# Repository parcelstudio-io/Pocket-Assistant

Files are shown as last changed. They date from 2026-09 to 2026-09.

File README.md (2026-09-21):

# Pocket AI Assistant

This repository turns the [Huy Vector Pocket AI Assistant](https://www.huyvector.org/robots-kinetic/pocket-ai-assistant) reference build into a reviewable project with a pinned vendor image, safe host-side flashing tools, a source-buildable Xiaozhi board port, an audited bill of materials, and an assembly/test checklist.

## Start here: one small step at a time

Follow the [action-only fast track](plan/FAST_TRACK.md). It tells you exactly
what to take out, what to connect, what command to run, and what result counts
as a pass. Do one numbered step at a time; do not unpack the whole project.

The first physical step needs one controller and a proven USB data cable. The
controller order is recorded, but the planned cable purchase is not confirmed;
the guide links the recorded candidate and shows how to test any cable you
already own. It then adds the button, OLED, and microphone one at a time. The
default source build is an **offline bench test**: it reports microphone levels
over USB and tests the OLED without Wi-Fi, a cloud account, an amplifier, or a
battery.

Leave the battery, charger, external regulators, amplifier, and metal case off
this first prototype. OLED/microphone power comes only from the controller's
3.3 V output. Never connect an external power source to that rail while USB is
connected.

The [technical USB quickstart](docs/PROTOTYPE_QUICKSTART.md) remains the compact
reference for experienced builders and troubleshooting. Engineering
explanations moved out of the action guide into the
[fast-track theory companion](plan/FAST_TRACK_THEORY.md). The
[15-session daily plan](plan/DAILY_STUDY_AND_LAB_PLAN.md) is the deep track —
full measurement labs, evidence discipline, and per-day material prep lists —
worth returning to before any future battery, audio-power, or enclosure work.

## Choose a firmware path

| Path | Use it when | What is reproducible |
| --- | --- | --- |
| Corrected source — recommended | Offline prototype tests first; assistant mode later | Pinned upstream/SDK, checked overlay, and a manifest of the actual local build |
| Pinned vendor image — historical | Investigating the creator's published behavior and face assets | Download integrity only; its GPIO8 microphone and 24 kHz audio are not the corrected prototype contract |

These paths are deliberately separate. The creator published only a merged binary, not the custom `pocket-wall-e-c3` source or face assets. Inspection identifies it as a private Xiaozhi `2.4.0` build made with `ESP-IDF v5.5.2-dirty`. The editable port in [`firmware/`](firmware/) reconstructs the board against public [Xiaozhi v2.4.0](https://github.com/78/xiaozhi-esp32/releases/tag/v2.4.0) and its supported ESP-IDF v6.0.2 toolchain; it is not claimed to be byte-identical.

## Repository map

```text
.
├── docs/
│   ├── FINAL_MATERIALS_FOR_REVIEW.md  current Phase 0 purchase authority
│   ├── CLAUDE_R1_BUILD_PROPOSAL.md    archived compact-build proposal
│   ├── MATERIALS.md              archived R1 order sheet; do not order from it
│   ├── BUILD_GUIDE.md            video correlation; final assembly is held
│   ├── WIRING_AND_ASSEMBLY.md    archived R1 power wiring; not build authority
│   └── BOM.md                    historical creator-page ↔ R1 reconciliation
├── edu/
│   ├── README.md                 course index and source-of-truth map
│   ├── STUDY_PLAN.md             battery-free fifteen-session curriculum
│   ├── 01-how-it-fits-together.md applied system and signal overview
│   ├── 05_COLOR_AND_FINISH.md    provisional finish study
│   └── fundamentals/             durable electronics lessons and references
├── firmware/
│   ├── src/                      editable pocket-wall-e-c3 board overlay
│   ├── scripts/                  prepare, build, and source-flash helpers
│   ├── source-build.json         validated source-build digest and inputs
│   └── README.md                 source workflow and known differences
├── simulation/
│   ├── diagram.json              partial ESP32-C3/OLED/button Wokwi fixture
│   └── README.md                 simulation limits and lint command
├── plan/
│   ├── FAST_TRACK.md             action-only beginner build guide
│   └── FAST_TRACK_THEORY.md      optional theory mapped to each build step
└── tools/
    ├── netcheck.py               static checker; legacy power model withdrawn
    ├── pocket_ai_device.py       vendor-image fetch/verify/flash/monitor CLI
    ├── vendor-firmware.json      artifact provenance and integrity metadata
    └── tests/                    host-tool unit tests
```

A [partial Wokwi fixture](simulation/README.md) checks the corrected OLED and
GPIO10 button diagram. It intentionally does not model the power or audio
hardware.

Software setup can start without a new purchase. The first physical boot needs
a proven data cable, and a fully bare controller/OLED/microphone set needs 26
header pins; check the fast track before ordering or soldering anything. For a
**later battery-powered assembly**,
[docs/FINAL_MATERIALS_FOR_REVIEW.md](docs/FINAL_MATERIALS_FOR_REVIEW.md)
records the proposed F0 hardware and its unresolved tests; it is not a prerequisite
shopping list for the USB prototype. Do not connect the cell, cut brass, assemble
that power chain, or pocket-carry it without completing the relevant tests.
The former complete-cart decision is retained
unchanged in [docs/CLAUDE_R1_BUILD_PROPOSAL.md](docs/CLAUDE_R1_BUILD_PROPOSAL.md)
for review; [docs/MATERIALS.md](docs/MATERIALS.md),
[docs/BUILD_GUIDE.md](docs/BUILD_GUIDE.md), and
[docs/WIRING_AND_ASSEMBLY.md](docs/WIRING_AND_ASSEMBLY.md) describe that
superseded R1 candidate and are not purchasing or assembly authority.

Use the [electronics course](edu/README.md) as a reference when a step introduces
a new concept, not an entrance exam. Regardless of revision,
do **not** strip a lithium cell, solder to its can, use the brass frame as a
conductor, or charge an undocumented cell.

## Historical vendor-image workflow

Skip this section for the beginner prototype. Use the corrected source below;
a matching vendor checksum does not establish compatible microphone wiring or
MAX98357A audio timing.

For Phase 0, flash a bare SuperMini. An assembled service design is not yet
released. Until the proposed supply and I2S/control isolation pass every
source-state test, **unplug the pack and detach the external power and
amplifier-signal harnesses before connecting the SuperMini USB-C**, and never
connect both USB-C ports. Generic SuperMini clones have varying VBUS/`5V`
arrangements, so the final solution cannot rely on an assumed clone diode.

```bash
python3 -m venv .venv
. .venv/bin/activate
python -m pip install --upgrade pip
python -m pip install --requirement tools/requirements.txt

python tools/pocket_ai_device.py fetch
python tools/pocket_ai_device.py verify
python tools/pocket_ai_device.py ports
python tools/pocket_ai_device.py info --port /dev/ttyACM0
python tools/pocket_ai_device.py flash --port /dev/ttyACM0 --dry-run
python tools/pocket_ai_device.py flash --port /dev/ttyACM0
python tools/pocket_ai_device.py monitor --port /dev/ttyACM0
```

Replace `/dev/ttyACM0` with the explicit port reported on your machine. The image is a merged ESP32-C3 image and is written at `0x0`; the tool verifies it and asks for confirmation before writing. See [`tools/README.md`](tools/README.md) for Windows/macOS port names, BOOT-mode recovery, Wi-Fi provisioning, and privacy notes.

## Build the editable source port

The source workflow fetches the pinned upstream repository into an ignored working directory, applies the local board files, checks the upstream commit, and builds with ESP-IDF v6.0.2:

```bash
firmware/scripts/setup.sh
. firmware/.work/esp-idf/export.sh
firmware/scripts/build.sh
```

Setup is needed once; activate `export.sh` again in each new terminal.
`build.sh` defaults to offline diagnostics. Use `build.sh --assistant` only
after those tests pass and you are ready to configure the third-party service.
Read [`firmware/README.md`](firmware/README.md) before using the source-flash helper.
It records the expected toolchain, generated output, pin assignments, and the
differences from the opaque vendor image.

## Hardware contract

| Function | Module signal | ESP32-C3 GPIO |
| --- | --- | ---: |
| OLED I2C | SDA / SCL | 21 / 20 |
| Shared I2S clocks | WS / BCLK | 1 / 2 |
| Microphone input | I2S microphone data (#6049 ICS-43434 Phase 0 primary; INMP441 alternate) | 4 |
| Amplifier output | MAX98357A DIN | 3 |
| Optional external action button | active-low button | 10 |

The corrected source build accepts a 0.96-inch 128×64 SSD1306 I2C module at address `0x3c` or `0x3d`, uses 16 kHz duplex audio, and puts the I2S microphone's data output on GPIO4 with its left-slot select grounded. The Phase 0 primary is the controlled Adafruit #6049 ICS-43434 (`SEL` → GND); INMP441 (`L/R` → GND) remains an alternate after its carrier pinout is checked. The pinned creator binary instead requires microphone data on GPIO8 and OLED address `0x3c`. Both audio modules share `WS` and `BCLK`. GPIO10 is the active-low application input, while the SuperMini's ROM BOOT button remains GPIO9.

## What has and has not been verified

- The published binary's size, digest, merged-image markers, chip target, application metadata, and partition offsets were inspected and pinned.
- The host CLI has unit tests and refuses an unverified image or implicit serial-port target.
- Each successful source build records its exact inputs, effective configuration,
  mode, and output digest in ignored `firmware/dist/source-build.json`. The
  [checked-in reference record](firmware/source-build.json) describes one specific
  build; neither a checksum nor successful compilation proves hardware operation.
- The USB prototype was built and established `PASS 9` on 2026-09-20: two cold
  starts without a reset loop, every button press logged, the OLED starting and
  toggling, and speech microphone RMS roughly 4x the quiet floor with
  `read_errors=0`. That is a bench result recorded by the builder, not an
  automated one: no assembled battery circuit has been connected, the amplifier
  stays disabled, and `firmware/source-build.json` still records
  `hardware_tested: false` because that flag describes what the build workflow
  verified, which remains nothing physical.
- On 2026-09-21 the builder provisioned board `A1` onto Wi-Fi under the 8.5 dBm
  transmit-power cap and received one remote response from the Xiaozhi backend
  (`PASS 10C`). That is also a builder-reported bench result. The amplifier
  stays disabled, so there is still no spoken output. Follow [Lesson 13's staged integration method](edu/fundamentals/13-debugging-integration-and-capstone.md), keep a separate [lab record](edu/fundamentals/reference/lab-record-template.md) for each article, and use the [current F0 promotion gates](docs/FINAL_MATERIALS_FOR_REVIEW.md#promotion-gates-before-claude-may-say-final-go) before any cell connection or pocket carry.

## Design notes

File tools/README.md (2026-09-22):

# Device host tools

For the beginner USB prototype, start with the
[action-only fast track](../plan/FAST_TRACK.md) and the corrected source
diagnostic build. The [quickstart](../docs/PROTOTYPE_QUICKSTART.md) remains the
compact technical reference. You do not need to download the vendor binary or
create a second Python environment after activating ESP-IDF. The tests and
`netcheck.py` below are useful for both paths; this page's `fetch`/`flash`
commands are for the **historical vendor image only**, not the corrected-source
artifact.

The Pocket AI Assistant normally runs without a laptop-side application. The
ESP32-C3 firmware provisions Wi-Fi locally, then obtains its MQTT or WebSocket
session details from a Xiaozhi-compatible OTA/bootstrap service. These tools are
only for retrieving the published image, flashing it safely, and viewing logs.

The published download is a **merged 4 MB ESP32-C3 image**. It must be written at
address `0x0`, not at the application-only address `0x10000`. The manifest pins
the exact byte size and SHA-256 observed on 2026-09-01. If the publisher changes
the file behind the Google Drive link, the tool stops instead of flashing an
unreviewed artifact.

## Set up the host environment

Python 3.10 or newer and a USB **data** cable are required. From the repository
root:

```bash
python3 -m venv .venv
. .venv/bin/activate
python -m pip install --upgrade pip
python -m pip install --requirement tools/requirements.txt
```

On Windows PowerShell, activate with `.venv\Scripts\Activate.ps1`. Linux users
may need membership in their distribution's serial-port group (often
`dialout`) and must sign out and back in after changing it.
If `python3 -m venv` reports that `ensurepip` is unavailable, install your
distribution's Python venv package (commonly `python3-venv`) and retry; do not
fall back to installing or running the flashing stack as root.

## Verify the host tools

From the repository root:

```bash
python3 -m unittest discover -s tools/tests -v
python3 tools/netcheck.py
```

The unit tests exercise image validation, write safeguards, source-build
provenance, and intentionally invalid logical connections. `netcheck.py`
checks the corrected-source GPIO/protocol contract, endpoint uniqueness, and
the modeled floating speaker connections. It does not inspect your breadboard
or qualify power, USB isolation, physical modules, audio, RF, or fit.

## Fetch and verify

```bash
python tools/pocket_ai_device.py fetch
python tools/pocket_ai_device.py verify
```

The default image location is the ignored `tools/.cache/pocket-esp-ai.bin`.
Neither the third-party binary nor credentials are committed to the repository.

## Identify and flash the board

Connect the ESP32-C3 directly over USB, close programs using its serial port,
then list ports:

```bash
python tools/pocket_ai_device.py ports
python tools/pocket_ai_device.py info --port /dev/ttyACM0
```

Use the port shown on your system (`/dev/ttyACM0`, `/dev/ttyUSB0`, a macOS
`/dev/cu.*` device, or a Windows `COM` port). The tool never guesses the target
for a write. To preview and then perform the flash:

```bash
python tools/pocket_ai_device.py flash --port /dev/ttyACM0 --dry-run
python tools/pocket_ai_device.py flash --port /dev/ttyACM0
```

Flashing at `0x0` replaces the bootloader, partition table, application, assets,
and NVS, so saved Wi-Fi configuration is cleared. The tool verifies the image
again and requires typing `FLASH` before it starts. Use `--yes` only in a
controlled automated workflow.

If automatic reset cannot enter the ROM bootloader, hold the board's **BOOT**
button, tap **RESET** (or reconnect USB), release **BOOT**, and retry. Do not use
the destructive erase command as a routine prerequisite. It is available for
recovery and has a separate confirmation:

```bash
python tools/pocket_ai_device.py erase --port /dev/ttyACM0
```

## View boot logs and provision Wi-Fi

```bash
python tools/pocket_ai_device.py monitor --port /dev/ttyACM0
```

The console uses 115200 baud; exit it with `Ctrl+]`. On a clean first boot, the
firmware is expected to create a `Xiaozhi-XXXX` Wi-Fi provisioning access point,
where the suffix is device-specific. Confirm the actual name in the boot log,
join it from a phone or computer, and open <http://192.168.4.1> if the captive
portal does not appear. Choose a 2.4 GHz network and enter its credentials in
the device-hosted form.

The stock image uses `https://api.tenclass.net/xiaozhi/ota/` as its bootstrap
service. That third-party service receives device metadata and assistant audio;
review its terms and privacy behavior before using it. No cloud token or API key
belongs in this repository. A different backend requires a compatible OTA
service URL and, preferably, a source build configured for that service.

## Check which Wi-Fi network a board has saved

`saved_wifi.py` reads only the board's NVS settings partition, prints the saved
network names with every password shown as `<hidden, set>` or `<hidden, empty>`,
and deletes its temporary copy even if a step fails. The read resets the board
once and writes nothing. Run it inside the ESP-IDF environment:

```bash
. firmware/.work/esp-idf/export.sh
python tools/saved_wifi.py --port /dev/ttyACM0
```

`No saved Wi-Fi network` is the expected result after a full diagnostics
reflash, which writes a blank settings area.

## Troubleshooting

- `No serial ports found`: try a known data-capable cable and another USB port.
- Permission denied on Linux: fix serial-group or device permissions; do not run
  the whole workflow as root.
- Connection timeout: manually enter download mode with BOOT/RESET and retry at
  a lower baud, for example `--baud 115200`.
- SHA-256 mismatch: do not bypass verification. Check whether the publisher has
  intentionally released a new image, then review and update the manifest.
- Boot loop after a successful write: capture the complete 115200-baud log and
  confirm the board is actually an ESP32-C3 with at least 4 MB of flash.

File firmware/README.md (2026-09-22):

# Pocket AI Assistant firmware

This directory provides a buildable source overlay for the Pocket AI Assistant's
ESP32-C3 hardware. It pins the public Xiaozhi application, adds the project's
board registration and intended pin map, forces the 4 MB flash layout,
and produces a merged image that can be flashed at address `0x0`.

> **Current-contract boundary:** the corrected source targets an I2S
> microphone on GPIO4 (Phase 0 primary: Adafruit `#6049` ICS-43434 with `SEL`
> low; held alternate: INMP441 with `L/R` low) and a MAX98357A
> amplifier on GPIO3, with shared clocks on GPIO1/GPIO2 at 16 kHz. This README
> is not purchase authority; the release decision is
> [FINAL_MATERIALS_FOR_REVIEW.md](../docs/FINAL_MATERIALS_FOR_REVIEW.md).

## Beginner default: offline USB diagnostics

Start with the [action-only fast track](../plan/FAST_TRACK.md), not the vendor
binary. The [prototype quickstart](../docs/PROTOTYPE_QUICKSTART.md) is the
compact technical reference. The default build tests the OLED and prints
microphone levels over USB. It does not start Wi-Fi, provision an account, or
send recordings anywhere. The amplifier is disabled. Begin with a bare
controller; add the OLED and microphone one at a time, powered from its 3.3 V
output only.

From the repository root, in Bash:

```bash
firmware/scripts/setup.sh
. firmware/.work/esp-idf/export.sh
firmware/scripts/build.sh
python3 firmware/scripts/verify_source_build.py
```

Setup downloads the pinned SDK and its tools and can take several minutes.
It does not need hardware or administrator privileges. Run setup once and
source `export.sh` again in each new terminal. Use `build.sh --diagnostics`
as an explicit alias for the default, or `build.sh --assistant` later for the
networked application. Both supported modes keep the amplifier disabled.
The last successful build is the one the verifier and flash helper select.

## Source status and limits

The project author publishes a merged binary but not the corresponding board
source. This adapter is therefore a careful source reconstruction, **not** the
author's original code and not a byte-for-byte rebuild of that binary.

- The vendor image identifies itself as Xiaozhi `2.4.0`, board
  `pocket-wall-e-c3`, built by a private `ESP-IDF v5.5.2-dirty` tree.
- This source workflow pins public Xiaozhi tag `v2.4.0` at commit
  `5540258abcbfa62518d09959308200be1c5b1b2b` and the upstream-preferred
  ESP-IDF `v6.0.2`.
- The author's `PocketOledDisplay` behavior is unpublished. The overlay keeps a
  board-specific display extension point but currently uses Xiaozhi's standard
  128x64 OLED interface instead of attempting to imitate the custom face UI.
- The checked-in `dependencies.lock` pins the 60 managed components and their
  registry hashes used by the validated build. The build fails if the component
  manager tries to rewrite that lock.
- `SOURCE_DATE_EPOCH` is fixed to the upstream commit timestamp so generated
  app metadata and compiler date/time strings do not depend on build time.
- A successful build creates ignored `dist/source-build.json`, recording the
  actual image, all local source inputs, effective configuration, build mode,
  and tool versions. Verification checks these again before flashing. The
  checked-in `source-build.json` is a reference for a specific build, not a
  permanent checksum every future source edit must reproduce. Local records
  do not inherit old claims of identical clean builds or hardware tests.
- The source and configuration can be compiled without the device. Electrical,
  microphone, speaker, button, and end-to-end assistant behavior still require
  a hardware smoke test.

Assistant mode additionally diverges for English users: wake word
`wn9s_hiesp` ("Hi, ESP") and `CONFIG_LANGUAGE_EN_US` replace the vendor
image's Mandarin `wn9s_nihaoxiaozhi` and zh-CN strings (both set in
`sdkconfig.defaults` and the board `config.json`; the explicit
`# CONFIG_SR_WN_WN9S_NIHAOXIAOZHI is not set` line is required because the
WakeNet9s entries are independent bools, not a choice group).

### Amplifier-enabled build for Step 11

`build.sh --assistant --amplifier` (or `--assistant-local ... --amplifier`)
enables the amplifier for fast-track Step 11, where the MAX98357A takes `VIN`
from the controller's `5V` pin and GPIO5 drives its `SD` pin directly with a
pull-down. The firmware holds GPIO5 low from its earliest board init, starts the
I2S clocks with zero data, waits the startup delay, raises GPIO5, waits the
turn-on delay, and only then sends audio, capped by `CONFIG_POCKET_AI_MAX_VOLUME`.
The diagnostics build refuses `--amplifier`. The build record, verifier, and
flash preview print `amplifier: ENABLED (Step 11, USB-powered)`. None of this
has run on hardware yet.

### Local OpenAI voice bridge

**Parked build note (2026-09-21):** The prepared A1 image is
`dist/pocket-wall-e-c3-v2.4.0-idf-v6.0.2.bin` (SHA-256
`903e5cfe6fedae2bd0f245ac432105347dc94b5688010092a39f8c20dfa753ff`).
It is the `assistant-local` build of Xiaozhi v2.4.0 on ESP-IDF v6.0.2,
targeting ESP32-C3 with a private bridge URL on host `192.168.1.171`.
The amplifier is disabled. The image passed source verification and a flash
dry run; it has **not** been flashed to A1 or tested with the OpenAI API or
speaker. Recheck the host IP and rebuild before use if the network changes.

`build.sh --assistant-local --bridge-url=http://HOST:8765/ota/SECRET` builds the
same A1 assistant with its Xiaozhi audio WebSocket pointed at the LAN bridge
in [`bridge/`](bridge/). Replace `HOST` with the computer's LAN IP address
that A1 can reach; use the `A1_OTA_TOKEN` generated for the bridge as `SECRET`.
The build keeps OpenAI credentials on that computer and
ignores any older Xiaozhi OTA URL saved on A1. If the bridge is unavailable,
the firmware waits for it instead of using a cached cloud WebSocket address.
The bridge computer and A1 must be on the same reachable network while using
this build. Reflashing the merged image at `0x0` may erase saved Wi-Fi settings;
be ready to provision Wi-Fi again.

The current supported build still holds GPIO5 low and writes silence to the
speaker path. It can validate microphone upload and OpenAI responses, but A1
will not speak until the MAX98357A interface and power sequence have passed
the hardware checks below and an amplifier-enabled build mode is added.

For the exact published image and its pinned checksum, use the
[host flashing and verification tools](../tools/README.md).

## Current corrected-source pin map

| Function | ESP32-C3 GPIO | Peripheral connection |
| --- | ---: | --- |
| I2S word select | 1 | #6049 ICS-43434 `WS/LRCLK` (alt: INMP441 `WS`) and MAX98357A `LRC` |
| I2S bit clock | 2 | #6049 ICS-43434 `BCLK` (alt: INMP441 `SCK`) and MAX98357A `BCLK`; expected 1.024 MHz |
| I2S speaker data | 3 | MAX98357A `DIN` |
| I2S microphone data | 4 | #6049 ICS-43434 `DOUT` (alt: INMP441 `SD`) |
| Optional action/config input | 10 | Active-low push button to GND if fitted |
| OLED SCL | 20 | SSD1306 SCL |
| OLED SDA | 21 | SSD1306 SDA |

These are logical endpoints. The F0 hardware experiment interposes a one-way
TXU0104 boundary between GPIO1/GPIO2/GPIO3 and the amplifier. It proposes
GPIO5, with 4.7 kΩ to ground, as channel A4; B4 then releases `SD_MODE` into
left-channel operation. The #2873 open-drain power-good output independently
gates TXU `OE` through a 10 kΩ pull-up to 5V_SYS, so loss of rail-good disables
all amplifier-side outputs. Official chip reset does not itself pull MTDI
(GPIO5) high, but firmware APIs can enable that pull-up: GPIO5 must be driven low
at the earliest board-init point and must not be reset into a pulled-up state.
The candidate has no MCU `PG` sense input: firmware sequencing uses a qualified
startup/rail delay and valid zero-data I2S while `PG` independently vetoes
`OE`. The delay before nonzero samples must cover measured worst-case `PG`
release plus amplifier turn-on, or the final schematic needs a reviewed
level-safe sense path.
The board codec implements the GPIO5 mute/startup/shutdown sequence, but the
physical interface and its timing are **not hardware-qualified**. The supported
prototype builds deliberately keep `CONFIG_POCKET_AI_ENABLE_QUALIFIED_AMPLIFIER`
off. Leave the amplifier disconnected for the USB quickstart; on a separate
unqualified audio fixture, keep `SD_MODE` hard-grounded. Do not bypass that mute
just to hear a sound. Enabling a qualified fixture later requires deliberate
configuration/tooling changes and measured startup, shutdown, and partial-power
checks. A firmware volume limit alone is not a speaker-power qualification.

At 16,000 frames/s and 64 bit clocks per frame, the I2S bit clock is
`16,000 × 64 = 1.024 MHz`. The microphone uses the intended left slot with its
select pin low (#6049 `SEL`; INMP441 `L/R`). The pinned codec selects mono DMA
with `I2S_STD_SLOT_LEFT`; source inspection therefore predicts active left and
inactive right TX slots because ESP-IDF copy-mono is enabled only for a `BOTH`
slot mask. Treat that as unverified until a hardware capture confirms it. Do
not assume the #3006 default mix gives full amplitude; qualify its `SD` mode
and select left explicitly if the capture confirms an inactive right slot.

### Historical vendor/video contract

The published vendor image uses a microphone harness with data on GPIO8,
SSD1306 address `0x3C`, and 24 kHz full-duplex audio. Those recovered values
are historical replication evidence only — never wire the corrected-source
GPIO4 harness for the vendor binary or vice versa. DFRobot `DFR0954` remains
an unqualified amplifier alternative; do not substitute it for a MAX98357A
breakout without revisiting the rail analysis in the materials decision.

The editable corrected source build uses 16 kHz duplex audio, receives mic data
on GPIO4 so GPIO8 can retain a defined high boot strap, probes SSD1306 at
`0x3C` and `0x3D`, and continues headless when no display answers. GPIO10 is
the active-low action/config input; GPIO9 remains ROM BOOT. The
[project overview](../edu/01-how-it-fits-together.md) summarizes this
corrected-source logical contract. This README and the board configuration
remain authoritative for firmware details. Do not mix the two wiring
contracts.

## Directory layout

```text
firmware/
├── partitions/       reviewed 4 MB partition table
├── patches/          Xiaozhi CMake/Kconfig board registration
├── scripts/          setup, prepare, build, record, verify, and flash entry points
├── src/boards/       project-owned board adapter and pin configuration
├── dependencies.lock pinned ESP-IDF component graph and registry hashes
├── source-build.json reference build record (local builds use dist/source-build.json)
├── sdkconfig.defaults
└── versions.env      pinned source and SDK versions
```

`scripts/prepare.sh` creates an ignored checkout under `.work/`, verifies the
exact upstream commit, applies the registration patch, and copies the reviewed
board files. A plain `prepare.sh` preserves and rejects a mismatched checkout.
`prepare.sh --refresh` archives that checkout instead of deleting it, then
prepares the updated overlay. `build.sh` uses this recoverable refresh
automatically, so an intentional source edit does not require manual cache
surgery. Build products go to ignored `dist/`.

## Build

The helper scripts require Bash and Python 3.10 or newer. Linux/macOS users
can use `setup.sh` above; Windows users should use a configured WSL environment
and arrange USB forwarding for the device. Git must already be installed. If
SDK setup reports a missing OS package such as Python venv support, install
that named prerequisite with your OS package manager and rerun setup; do not
run the firmware or flashing workflow as root.

An existing official Espressif ESP-IDF `v6.0.2` checkout at commit
`7101770dc6db2667b3c477cc31365dd1acd6db4e` can also be used: source its
`export.sh` instead. The build rejects a different SDK commit or tracked SDK
modifications. Python tool versions are recorded from the actual environment.

From the repository root:

```bash
firmware/scripts/build.sh
```

The build script rejects a different SDK version, regenerates `sdkconfig`, adds
the board overrides, compiles the app and default assets, and creates:

```text
firmware/dist/pocket-wall-e-c3-v2.4.0-idf-v6.0.2.bin
```

That file is a complete merged 4 MB-layout image for offset `0x0`. The app
partition begins at `0x10000`; do not write the merged image there.
Read the exact size, digest, and selected mode from `dist/source-build.json`
or run the verifier. There is intentionally no second, manually maintained
checksum in this README. A changed source input or modified binary after the
build fails verification; rebuild intentionally instead of bypassing the check.

To change an ordinary Kconfig option permanently, edit `sdkconfig.defaults` and
rerun the build. The CLI selects diagnostics versus assistant mode explicitly
and holds amplifier enable off. Temporary `menuconfig` edits are intentionally
replaced on the next scripted build. Source modifications belong in `src/` or
`patches/`, not the generated `.work/` checkout; refreshed checkouts are archived
so any earlier experiments remain recoverable.

## Flash and monitor source builds

For the USB bench prototype, use only the controller, button, and optional
OLED/microphone powered by the controller's 3.3 V output. Disconnect the
battery, charger, external regulators, amplifier, and all separately powered
wiring. A controller-powered peripheral is not an external supply; an
unpowered regulator connected to the same rail still is a back-power path.
Unplug USB before changing any wiring. Do not flash a permanently assembled
multi-supply harness until its service-isolation scheme is tested.
Then identify the serial port, close other serial
monitors, preview the operation, and run it, for example:

```bash
firmware/scripts/flash.sh /dev/ttyACM0 --dry-run
firmware/scripts/flash.sh /dev/ttyACM0 --monitor
```

Use the actual port on the host (`/dev/cu.*` on macOS; use the serial path exposed
inside WSL/Git Bash on Windows). The script requires typing the exact target
unless `--yes` is deliberately used for automation. It verifies the complete
merged image and byte-producing local inputs, then invokes esptool directly at
offset `0x0`; the flash step cannot trigger a rebuild after verification. Its
blank NVS area clears existing Wi-Fi settings. If automatic reset fails,
hold the module's GPIO9 **BOOT** button, tap RESET or reconnect USB, release
BOOT, and retry.

The default diagnostic image reports its mode over USB and remains offline;
use the quickstart to interpret the OLED and microphone results. No raw
recording is saved. Missing peripherals are reported, not prerequisites for
controller bring-up.

**Assistant mode only:** on a clean first boot, connect to the expected
device-specific `Xiaozhi-XXXX`
Wi-Fi provisioning access point, confirm its actual name in the boot log, and
open <http://192.168.4.1> if the captive portal does not appear. On this board
the firmware caps Wi-Fi transmit power at 8.5 dBm after every radio start, for
the provisioning access point and for the station connection, because the
SuperMini's ceramic antenna left the access point invisible at the default
20 dBm; the log prints `Wi-Fi max TX power capped at 8.5 dBm` for each. Xiaozhi's
default build uses `https://api.tenclass.net/xiaozhi/ota/` as its third-party
bootstrap service. Review that service's privacy and operational requirements
before sending microphone audio to it.

The pinned provisioning component creates that temporary access point without
Wi-Fi authentication and serves the form over unencrypted HTTP. It stores the
selected SSID and password in unencrypted NVS. Provision only in a private
location, preferably onto a dedicated guest/IoT SSID with a unique password;
nearby parties could otherwise observe or interfere. A reset does not remove
the saved credentials. The full source-flash operation above writes blank NVS
and clears them, so complete that reflash before a provisioned board leaves
your control.

This 4 MB layout has a factory application and no OTA application slot. The
firmware hides the unsupported manual-update tool and refuses OTA before
changing application state. Update this prototype using the USB flash helper,
not an online firmware-update command.

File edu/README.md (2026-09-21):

# Pocket Assistant electronics course

This directory teaches the electrical-engineering ideas needed to reason about
the Pocket Assistant and provides a small set of project-specific guides. It
assumes arithmetic and basic algebra, but no prior electronics experience.

Start with the [action-only fast track](../plan/FAST_TRACK.md) to boot the
controller and test the button, OLED, and microphone one part at a time. The
[USB prototype quickstart](../docs/PROTOTYPE_QUICKSTART.md) is the compact
technical reference. The [daily study and lab plan](../plan/DAILY_STUDY_AND_LAB_PLAN.md)
adds 2–3 hour sessions around that work. Read the relevant
[foundations lesson](fundamentals/README.md) as each circuit becomes useful;
you do not need to finish the course before starting. Keep these references
nearby:

- [equation sheet](fundamentals/reference/equations.md);
- [glossary](fundamentals/reference/glossary.md); and
- [lab record template](fundamentals/reference/lab-record-template.md).

Every lesson of the course, the project overview, the theory companion, the
Step 10 bench guide, and the current study plan are also published as
illustrated three-page web pages; the
[index of published learning pages](ARTIFACTS.md) holds the links. The
Markdown here remains the authority.

## Project-specific guides

- [Pocket Assistant project overview](01-how-it-fits-together.md) — system
  boundary, corrected-source logical contract, and lesson navigation.
- [White, silver, and black finish study](05_COLOR_AND_FINISH.md) — provisional
  visual direction and the tests required before a finish is adopted.

Project-specific component tables, power recipes, assembly instructions, and
acceptance worksheets are intentionally not duplicated here. Their status
changes as candidates are reviewed.

## Where truth lives

| Question | Source |
| --- | --- |
| Durable theory and safe technique | [Foundations course](fundamentals/README.md) |
| First USB prototype, owned-part wiring, and offline diagnostics | [Prototype quickstart](../docs/PROTOTYPE_QUICKSTART.md) |
| Firmware pins, rates, and build identity | [Firmware README](../firmware/README.md), [`config.h`](../firmware/src/boards/pocket-wall-e-c3/config.h), and [source-build manifest](../firmware/source-build.json) |
| Current candidates, purchase authority, and promotion gates | [Current material decision](../docs/FINAL_MATERIALS_FOR_REVIEW.md) |
| Results from a physical article | A completed [lab record](fundamentals/reference/lab-record-template.md) |

A marketplace listing, successful compile, static check, or CAD model is not
physical acceptance. The manifest still records `hardware_tested: false`,
which describes the build workflow, not the bench: the USB prototype itself
was built and passed its cold-start gate on 2026-09-20, and completed one
cloud round trip on 2026-09-21. Everything past that — amplifier, battery,
enclosure — remains unbuilt and unqualified.

## Safety boundary

Keep lithium cells out of early labs. Never strip, solder, heat, puncture, or
deliberately short a cell. Use a current-limited bench supply and follow the
current material decision before introducing stored energy.

Treat the metal frame as conductive and isolate it from every electrical net.
It is never a circuit conductor or return path. Neither bridge-amplifier
speaker lead is ground.

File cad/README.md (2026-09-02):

# CAD status and regeneration

> **STALE; NOT FIT OR FABRICATION AUTHORITY — 2026-09-02.** Everything in this
> directory models the withdrawn R0 architecture (16340 cell + BH123A holder +
> older Pololu stack, ~60 × 45 × 33 mm). It also predates the current F0
> candidate, which samples a 34 × 62 × 5 mm #258 pouch, #4410 charger, #2810
> switch, #2873 regulator, fuse, diode, two speaker geometries, and rigid cell
> guard. Use [docs/FINAL_MATERIALS_FOR_REVIEW.md](../docs/FINAL_MATERIALS_FOR_REVIEW.md).
> Do not regenerate from the old constants or cut brass. First measure the
> received Phase 0 parts, then rewrite `fitcheck.py`, regenerate every artifact,
> and verify the result with a 1:1 cardstock model.

`fitcheck.py` is the editable source for the placement study. The existing
`pager_rev_a.FCStd`, `pager_rev_a.step`, and `FITCHECK_REPORT.md` were
generated before the final audit; beyond the architecture change above, they
also used the wrong MPD BH123A dimensions, a discontinued capacitor, and an
incomplete antenna keepout. They are preserved for provenance only.
Regenerate after installing FreeCAD:

```bash
freecadcmd cad/fitcheck.py
```

Accept a new report only when every rule passes with measured part envelopes,
wire-bend room, insulation, fasteners, cell insertion/removal, and actual
connector plugs represented. A 1:1 cardstock/caliper dry fit remains required.

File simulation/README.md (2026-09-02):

# Partial Wokwi fixture

This fixture represents only the corrected ESP32-C3 display/action-button contract:

- SSD1306 on GPIO21 SDA / GPIO20 SCL;
- OLED deliberately set to `0x3d` to exercise the alternate-address probe; and
- active-low GPIO10 action button (`A` key in Wokwi).

It uses Wokwi's ESP32-C3 DevKitM model, not the mechanically different SuperMini. Wokwi does not prove the battery/charger/switch power path, real INMP441 acoustics, MAX98357A bridge output, speaker enclosure, Wi-Fi performance inside brass, solder quality, or temperature. Those require lesson 6's physical tests.

In `diagram.json`, the DevKitM model names GPIO20/21 `RX`/`TX`; these are connected to SCL/SDA respectively. The corrected firmware still addresses the GPIO numbers.

Validate the diagram without credentials:

```bash
wokwi-cli lint --warnings-as-errors simulation/diagram.json
```

To run the corrected source artifact after rebuilding it, export `WOKWI_CLI_TOKEN` in the same shell and point Wokwi CLI at the merged binary plus `firmware/.work/xiaozhi-esp32/build/xiaozhi.elf`. Do not store the token in this repository. The present Codex process has Wokwi CLI 0.26.1 but does not inherit that variable, so only linting was performed here.

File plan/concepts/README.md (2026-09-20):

# Illustrated concepts — the “why” behind each lab

[Back to the daily plan](../DAILY_STUDY_AND_LAB_PLAN.md) ·
[Action-only fast track](../FAST_TRACK.md) ·
[Fast-track theory map](../FAST_TRACK_THEORY.md) ·
[USB prototype technical reference](../../docs/PROTOTYPE_QUICKSTART.md)

Yes: start with the basic physics of **charge, energy, voltage, and current**,
then learn how complete circuits behave. You do not need to master all of
physics or finish every electronics lesson before booting a bare USB board.
Understand the circuit you are about to change, one small step at a time.

These are optional **5–10 minute illustrated explanations**, not extra lab
requirements. Each connects a physical idea to a calculation and a prototype
decision, then asks you to predict something. Expand the answer after trying.
Use these pages within the daily plan's existing study time, not on top of it.

## A small starting point

Read **01 → 02 → 03** first for the circuit foundation. Add **04 → 05** when
you reach capacitors and measurements. After that, open just the page for
the component you are testing. “I can explain why” is more useful than
memorizing every equation.

| Day | Illustrated explanation | The question it answers |
| ---: | --- | --- |
| 1 | [Charge, energy, and circuits](01-charge-energy-and-circuits.md) | What flows, what transfers energy, and why is a return needed? |
| 2 | [Voltage, current, resistance, power](02-voltage-current-resistance-and-power.md) | What do the units mean, and where does `P = VI` come from? |
| 3 | [Series, parallel, rails, loading](03-series-parallel-and-loading.md) | Why do resistor formulas work, and why does a divider sag? |
| 4 | [Capacitors and time](04-capacitors-and-time.md) | What is stored, and why does voltage change gradually? |
| 5 | [Measurement and uncertainty](05-measurement-and-uncertainty.md) | How does a meter affect the circuit, and what can it miss? |
| 6 | [From code to boot](06-from-code-to-boot.md) | How do files become electrical activity on a board? |
| 7 | [GPIO and buttons](07-gpio-and-buttons.md) | How do voltages become bits, and why do inputs need a defined state? |
| 8 | [I2C and the OLED](08-i2c-and-the-oled.md) | How can devices share a wire without fighting each other? |
| 9 | [Sampling and I2S](09-sampling-and-i2s.md) | How does sound become numbers and timed bits? |
| 10 | [Speakers and amplifiers](10-speakers-and-amplifiers.md) | How does electrical power move a cone, and why is neither output ground? |
| 11 | [Soldering and heat](11-soldering-and-heat.md) | Why must the joint get hot, not just the solder? |
| 12 | [Joints and strain relief](12-joints-and-strain-relief.md) | Where does a tug go, and why do wires break at rigid joints? |
| 13 | [Power integrity](13-power-integrity.md) | Why can a rail dip when current suddenly increases? |
| 14 | [Fit and radio](14-fit-and-radio.md) | Why do clearances, tolerances, and nearby metal matter? |
| 15 | [Debugging as experiments](15-debugging-as-experiments.md) | Which measurement best separates two possible causes? |

## How to read the drawings

A line on a **schematic** represents an electrical connection, not a physical
wire position. A filled dot marks a joined node. A resistor is drawn as a
rectangle; `GND` labels a voltage reference/return, not Earth or the brass frame.
Current arrows use the conventional direction. Block diagrams and mechanical
sketches are labeled and are not wiring layouts.

The SVG figures are original, editable diagrams. Labels and captions carry
the meaning; you do not have to distinguish the colors. Open a figure on its
own to enlarge it. Numeric examples are idealized predictions unless explicitly
identified otherwise, not measured limits of your parts.

These pages introduce **no new purchases or powered experiments**. Keep using
the daily plan's wiring checks, power limits, and stop conditions. Amplifier,
battery, and final enclosure work remain separate from the first USB prototype.
For a longer explanation, follow the existing `edu/` lesson linked at the end
of each page.

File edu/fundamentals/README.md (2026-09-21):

# EE foundations for the Pocket Assistant

The course moves from physical intuition to a complete system. Read it in
order the first time; later, use individual lessons as references. Each
lesson also exists as an illustrated three-page web page, listed in the
[index of published learning pages](../ARTIFACTS.md); these Markdown files
remain the authority.

| Stage | Lessons | You should be able to do afterward |
| --- | --- | --- |
| Orientation | [00](00-safety-evidence-and-course-map.md) | Work safely and distinguish facts, assumptions, calculations, and measurements |
| Physical model | [01](01-units-charge-voltage-current-power-energy-heat.md)–[03](03-components-rc-diodes-mosfets-converters.md) | Explain a closed current path, solve small DC circuits, and predict component behavior |
| Engineering representation | [04](04-boards-schematics-datasheets-and-connectors.md)–[05](05-measurement-dmm-supply-scope-logic-analyzer.md) | Read a schematic/datasheet and use basic bench tools without creating a short |
| Power and digital | [06](06-li-ion-power-integrity-decoupling-uvlo-thermal.md)–[09](09-i2s-sampling-and-digital-audio.md) | Analyze the power rail, GPIO, I2C, and I2S timing |
| Physical implementation | [10](10-class-d-btl-speakers-and-acoustics.md)–[12](12-soldering-mechanics-insulation-tolerance.md) | Reason about audio, RF, soldering, insulation, and packaging |
| Integration | [13](13-debugging-integration-and-capstone.md) | Bring a system up one layer at a time and diagnose planted faults |

The recommended learning kit is a solderless breadboard, resistor/capacitor
assortment, LED, pushbutton, fused digital multimeter, current-limited bench
supply, jumper wires, and a bare ESP32-C3 plus OLED. A logic analyzer is very
helpful; an oscilloscope is optional. No lithium cell is needed for the
foundations course.

The course uses the five
[evidence labels defined in Lesson 00](00-safety-evidence-and-course-map.md#the-five-evidence-labels).
Never silently promote `TYPICAL` or `ASSUMED` to a guaranteed fact.

For bench work, make a fresh copy of the
[lab record template](reference/lab-record-template.md). Write the prediction,
pass/fail rule, current limit, and stop conditions before turning power on.

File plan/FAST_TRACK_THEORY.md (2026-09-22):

# Fast-track theory companion — why each build step works

[Back to the action-only fast track](FAST_TRACK.md) ·
[Parts outline](FAST_TRACK_PARTS.md) ·
[All illustrated concept notes](concepts/README.md) ·
[Full electronics course](../edu/README.md) ·
[Illustrated version of this page](../edu/ARTIFACTS.md)

This page is optional while you build. The action guide contains every safety
rule, command, wire, and pass condition you need. Open only the section for the
step you are doing when you want to understand the engineering underneath it.

## Step 0 — why the boundary is so small

A circuit works only when current has a complete path from a source and back.
Using USB as the only source gives the prototype one known supply and one known
return. Adding a charger, battery, regulator, or amplifier would create new
power paths—including paths that can feed an unpowered board backwards—before
the simple digital parts have been tested.

- Short explanation: [charge, energy, and complete circuits](concepts/01-charge-energy-and-circuits.md)
- Short explanation: [voltage, current, resistance, and power](concepts/02-voltage-current-resistance-and-power.md)
- Deeper reference: [safety, evidence, and the course map](../edu/fundamentals/00-safety-evidence-and-course-map.md)

## Steps 1 through 4 — from source code to a running board

The build converts source files into a binary image. Verification checks that
the image matches the recorded inputs; it cannot prove that a physical board
works. `flash-id` is the first hardware observation. Flashing then replaces the
board's stored bootloader, partitions, application, and assets. The serial log
is the first evidence that those bytes actually boot on board `A1`.

- Short explanation: [from code to boot](concepts/06-from-code-to-boot.md)
- Deeper reference: [boards, schematics, datasheets, and connectors](../edu/fundamentals/04-boards-schematics-datasheets-and-connectors.md)
- Exact project workflow: [firmware guide](../firmware/README.md)

## Step 5 — soldering and connections

Solder is not glue. The pad and pin must both become hot enough for molten
solder to wet them. The metal joint carries current; a header and later strain
relief carry mechanical force. Visual inspection can find bridges and damage,
while the unpowered continuity tests separately ask whether the intended path
conducts and neighboring paths remain isolated.

A continuity beeper is a small current source watching for a low resistance.
Every module carries decoupling capacitors across its supply and ground, and an
empty capacitor briefly accepts that current as though it were a short, then
stops as it charges. That is why the action guide treats a **brief chirp**
between a supply and ground as normal and a **persistent tone or near-zero
resistance** as a stop condition: the first is a capacitor filling, the second
is a real fault. This distinction appears in Steps 5C–5E, 6, 7, 8, and 9, so it
is worth reading once.

- Short explanation: [soldering and heat](concepts/11-soldering-and-heat.md)
- Short explanation: [joints and strain relief](concepts/12-joints-and-strain-relief.md)
- Short explanation: [measurement and uncertainty](concepts/05-measurement-and-uncertainty.md)
- Short explanation: [capacitors and time](concepts/04-capacitors-and-time.md) — why a chirp is not a short
- Deeper reference: [soldering, mechanics, insulation, and tolerance](../edu/fundamentals/12-soldering-mechanics-insulation-tolerance.md)

## Step 6 — button and digital input

A solderless breadboard hides spring clips under its holes. On this build, an
ordinary group of five holes is one electrical node, while the center trench
separates the two sides. Side power rails run lengthwise but may be broken at
the midpoint. Printed red and blue stripes are only labels; the continuity
test establishes which holes are really connected. Creating one verified
`3V3` rail and one verified `GND` rail provides clean fan-out for the later
OLED and microphone instead of trying to crowd several leads onto one pin.

A digital input is still a voltage measurement. The firmware's pull-up makes
GPIO10 read high while the external button is open. Pressing the button connects
GPIO10 to ground, so it reads low. GPIO9 is different: the ESP32-C3 samples it
during reset to select boot behavior, which is why it stays reserved for
recovery.

- Short explanation: [series, parallel, and hidden breadboard nodes](concepts/03-series-parallel-and-loading.md)
- Short explanation: [GPIO and buttons](concepts/07-gpio-and-buttons.md)
- Deeper reference: [DC circuits and breadboard topology](../edu/fundamentals/02-dc-circuits-ohm-kirchhoff-series-parallel.md#know-the-solderless-breadboard-before-using-it)
- Deeper reference: [digital logic, GPIO, pulls, and boot straps](../edu/fundamentals/07-digital-logic-gpio-pullups-boot-straps.md)

## Step 7 — I2C and the OLED

I2C lets the controller address a device over two shared signals: `SCL` carries
the clock and `SDA` carries data. An acknowledgement at `0x3C` or `0x3D` proves
that a device at that address answered; the all-on/all-off pixel test
separately proves that the panel initialized and responds. Power polarity is
not part of I2C, which is why the actual `VCC` and `GND` labels must be checked
first.

- Short explanation: [I2C and the OLED](concepts/08-i2c-and-the-oled.md)
- Deeper reference: [I2C and the OLED lesson](../edu/fundamentals/08-i2c-and-the-oled.md)

## Step 8 — I2S microphone and RMS

The microphone samples sound and sends numbers, not an analog audio voltage.
At 16,000 frames per second, `WS` marks each frame, `SCK` shifts each bit, and
`SD` carries the microphone data into GPIO4. Grounding `L/R` chooses the left
slot used by this firmware. RMS summarizes the size of many samples, so a
repeatable quiet-versus-speech difference matters more than one magic number.
The two 32-bit slots in every 16,000 Hz frame require a bit clock of
`16,000 × 2 × 32 = 1.024 MHz`.

The `L/R` mapping rests on two facts that must agree. The mic side is
datasheet-defined: the INMP441 drives the left slot when `L/R` is low. The
controller side — which slot the firmware reads — is configured in upstream
`NoAudioCodecDuplex` (xiaozhi v2.4.0), which is fetched at build time and is
not in this repository. Step 8 is therefore the verification, not a formality:
a slot mismatch produces the specific signature of nonzero `samples` with
`min` and `max` both stuck at zero and `read_errors=0`, and the firmware
itself names "slot" as a suspect in that case.

GPIO2 is also an ESP32-C3 startup strap. The 10 kΩ pull-up gives it a defined
startup level before firmware takes control. The 100 kΩ pull-down prevents the
microphone-data input from floating while it is not actively driven.

- Short explanation: [sampling and I2S](concepts/09-sampling-and-i2s.md)
- Short explanation: [measurement and uncertainty](concepts/05-measurement-and-uncertainty.md)
- Deeper reference: [I2S, sampling, and digital audio](../edu/fundamentals/09-i2s-sampling-and-digital-audio.md)

## Step 9 — integration and repeatability

A device working once can be a lucky contact or an unrecorded setup. Two cold
starts exercise boot order and physical connections again. Adding one layer at
a time localizes a failure: if the button worked before the OLED was added, a
new failure should first be investigated at the OLED layer rather than by
randomly changing firmware.

- Short explanation: [debugging as experiments](concepts/15-debugging-as-experiments.md)
- Deeper reference: [systematic debugging and the capstone](../edu/fundamentals/13-debugging-integration-and-capstone.md)
- Optional record: [lab record template](../edu/fundamentals/reference/lab-record-template.md)

## Step 10 — network and cloud boundary

Assistant mode adds Wi-Fi provisioning and a remote service. That changes both
the failure surface and the privacy boundary: a local microphone problem, a
Wi-Fi problem, account activation, or a remote outage can now look similar.
Returning to offline diagnostics removes the network variables. The default
third-party service receives device metadata and microphone audio, so using it
is a deliberate product/privacy decision rather than an automatic build step.
The pinned provisioning component also uses an open temporary access point and
an unencrypted HTTP form, then stores the selected network credentials in
unencrypted flash settings. A full diagnostic reflash clears those settings;
a reset does not. That is why the action guide calls for a private location and
a unique guest/IoT network.

**Why the transmit power goes down, not up.** The SuperMini places its ceramic
chip antenna too close to the ground plane and neighbouring parts, so much of
the transmitter's output is reflected instead of radiated. On three boards from
this batch the setup hotspot was invisible at the firmware's default 20 dBm and
board `A1` became visible once the cap was lowered to 8.5 dBm, the same
workaround Arduino users apply to this board with
`WiFi.setTxPower(WIFI_POWER_8_5dBm)`. The value in the source, `34`, is in
quarter-dBm units, so it means 8.5 dBm. Why lower power helps is not settled:
the usual explanations are the power amplifier distorting into the mismatched
antenna, or the board's small regulator sagging under the current peaks of a
20 dBm burst. Either way the fix is empirical, and the cost is range. ESP-IDF
only honours the cap after the radio has started, which is why the board
applies it after each start: once for the setup hotspot and once for the
station connection, with a log line for each.

- Project reference: [assistant-mode firmware notes](../firmware/README.md#flash-and-monitor-source-builds)
- System overview: [how the parts fit together](../edu/01-how-it-fits-together.md)

## Step 11 — one supply, no translator

The purchase authority's amplifier fixture was designed for a battery device.
There, the controller can run from USB while the amplifier's rail is off. Clock
and data lines driven into an unpowered chip can push current backwards through
its input protection diodes into its supply, so the fixture needed a translator
that isolates the two sides until power is good. Powering the amplifier from the
controller's own `5V` pin removes that state: both sides rise and fall together
with USB, and the amplifier's supply, taken straight from USB, normally rises
before the controller's 3.3 V regulator output.

Three safeguards remain. A pull-down on `SD` keeps the amplifier in shutdown
while GPIO5 floats during reset; above about 1.5 V the same pin selects the left
channel, which is the channel the firmware fills. The volume cap limits the
digital amplitude, and the firmware squares the setting, so a cap of 15 passes
only about 2 % of full scale. The dummy load lets the scope measure the output
before a speaker sees it. Filtering the difference of the two outputs at
about 20 kHz matters because a class-D stage switches at a few hundred kilohertz,
and a speaker's coil, not the resistor, is what normally removes that carrier.

- Short explanation: [speakers and amplifiers](concepts/10-speakers-and-amplifiers.md)
- Deeper reference: [class-D, BTL, speakers, and acoustics](../edu/fundamentals/10-class-d-btl-speakers-and-acoustics.md)

## Theory for the later projects

Do not turn these readings into permission to connect held hardware. They
explain the questions that later qualification must answer.

| Later project | Short explanation | Deeper reference |
| --- | --- | --- |
| Portable power, out of scope for this prototype | [Power integrity](concepts/13-power-integrity.md) | [Li-ion, decoupling, UVLO, and thermal behavior](../edu/fundamentals/06-li-ion-power-integrity-decoupling-uvlo-thermal.md) |
| Enclosure and radio | [Fit and radio](concepts/14-fit-and-radio.md) | [RF, EMC, antennas, and the metal frame](../edu/fundamentals/11-rf-emc-antennas-and-metal-frame.md) |

The release authority for all three remains the
[current Phase 0 promotion gates](../docs/FINAL_MATERIALS_FOR_REVIEW.md#promotion-gates-before-claude-may-say-final-go).

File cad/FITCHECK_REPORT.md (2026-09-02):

# Rev A fit-check report

FreeCAD 1.1.3 · frame envelope 60 x 45 x 33 mm · 162/162 checks pass

> Geometric desk check only. Replace generic-board dimensions with caliper measurements and rerun before cutting the frame.

## Envelope provenance

| Part | Provenance | Source |
| --- | --- | --- |
| `oled_hosyond` | PROVISIONAL | Hosyond B09T6SJBV5 generic 0.96in; measure on arrival |
| `holder_aceirmc` | VENDOR | ACEIRMC B0CRGK889F listing dims 43.2x18.3x14.2; 16340 fit is inference - qualify on arrival |
| `speaker_cap` | PROVISIONAL | Treedix speaker in trimmed 20mm-ID vinyl cap; gate on measured cap OD (<=22.7mm fits) |
| `supermini` | PROVISIONAL | generic clone; measure on arrival |
| `amp_hiletgo` | VENDOR | HiLetgo B0CDWXZZCH, Adafruit-3006 lineage 0.9x0.65in; wire direct or right-angle pins, <=7mm height |
| `reg_xl63070` | PROVISIONAL | JESSINIE B0FFSHDLMV 16x30 footprint; inductor height unpublished - measure before committing |
| `star_board` | PROVISIONAL | perfboard scrap carrying buses + passives |
| `switch_slide` | PROVISIONAL | SPDT slide (SS12F44/SS12D00 class) incl. actuator; carries gate current only |
| `mic_inmp441` | PROVISIONAL | generic breakout; measure on arrival |
| `cap_220u` | PROVISIONAL | bulk cap from ALLECIN kit; measure the chosen can |
| `tact_button` | VENDOR | 6x6 mm tact with cap |
| `ptc_pair` | VENDOR | 2x Bourns RUEF110 7.4mm discs + P-FETs on the holder solder tag |
| `service_jumper` | VENDOR | 2-pin 0.1in header + shunt |

## Acceptance

**Not fit evidence yet** - 8 envelope(s) are PROVISIONAL. Measure them on arrival, update `fitcheck.py`, and regenerate:

- `cap_220u`
- `mic_inmp441`
- `oled_hosyond`
- `reg_xl63070`
- `speaker_cap`
- `star_board`
- `supermini`
- `switch_slide`

A 1:1 cardstock dry fit of the real parts is required regardless of this report.

## Rules

    PASS  R1 no overlap oled_hosyond vs holder_aceirmc
    PASS  R1 no overlap oled_hosyond vs speaker_cap
    PASS  R1 no overlap oled_hosyond vs supermini
    PASS  R1 no overlap oled_hosyond vs amp_hiletgo
    PASS  R1 no overlap oled_hosyond vs reg_xl63070
    PASS  R1 no overlap oled_hosyond vs star_board
    PASS  R1 no overlap oled_hosyond vs switch_slide
    PASS  R1 no overlap oled_hosyond vs mic_inmp441
    PASS  R1 no overlap oled_hosyond vs cap_220u
    PASS  R1 no overlap oled_hosyond vs tact_button
    PASS  R1 no overlap oled_hosyond vs ptc_pair
    PASS  R1 no overlap oled_hosyond vs service_jumper
    PASS  R1 no overlap holder_aceirmc vs speaker_cap
    PASS  R1 no overlap holder_aceirmc vs supermini
    PASS  R1 no overlap holder_aceirmc vs amp_hiletgo
    PASS  R1 no overlap holder_aceirmc vs reg_xl63070
    PASS  R1 no overlap holder_aceirmc vs star_board
    PASS  R1 no overlap holder_aceirmc vs switch_slide
    PASS  R1 no overlap holder_aceirmc vs mic_inmp441
    PASS  R1 no overlap holder_aceirmc vs cap_220u
    PASS  R1 no overlap holder_aceirmc vs tact_button
    PASS  R1 no overlap holder_aceirmc vs ptc_pair
    PASS  R1 no overlap holder_aceirmc vs service_jumper
    PASS  R1 no overlap speaker_cap vs supermini
    PASS  R1 no overlap speaker_cap vs amp_hiletgo
    PASS  R1 no overlap speaker_cap vs reg_xl63070
    PASS  R1 no overlap speaker_cap vs star_board
    PASS  R1 no overlap speaker_cap vs switch_slide
    PASS  R1 no overlap speaker_cap vs mic_inmp441
    PASS  R1 no overlap speaker_cap vs cap_220u
    PASS  R1 no overlap speaker_cap vs tact_button
    PASS  R1 no overlap speaker_cap vs ptc_pair
    PASS  R1 no overlap speaker_cap vs service_jumper
    PASS  R1 no overlap supermini vs amp_hiletgo
    PASS  R1 no overlap supermini vs reg_xl63070
    PASS  R1 no overlap supermini vs star_board
    PASS  R1 no overlap supermini vs switch_slide
    PASS  R1 no overlap supermini vs mic_inmp441
    PASS  R1 no overlap supermini vs cap_220u
    PASS  R1 no overlap supermini vs tact_button
    PASS  R1 no overlap supermini vs ptc_pair
    PASS  R1 no overlap supermini vs service_jumper
    PASS  R1 no overlap amp_hiletgo vs reg_xl63070
    PASS  R1 no overlap amp_hiletgo vs star_board
    PASS  R1 no overlap amp_hiletgo vs switch_slide
    PASS  R1 no overlap amp_hiletgo vs mic_inmp441
    PASS  R1 no overlap amp_hiletgo vs cap_220u
    PASS  R1 no overlap amp_hiletgo vs tact_button
    PASS  R1 no overlap amp_hiletgo vs ptc_pair
    PASS  R1 no overlap amp_hiletgo vs service_jumper
    PASS  R1 no overlap reg_xl63070 vs star_board
    PASS  R1 no overlap reg_xl63070 vs switch_slide
    PASS  R1 no overlap reg_xl63070 vs mic_inmp441
    PASS  R1 no overlap reg_xl63070 vs cap_220u
    PASS  R1 no overlap reg_xl63070 vs tact_button
    PASS  R1 no overlap reg_xl63070 vs ptc_pair
    PASS  R1 no overlap reg_xl63070 vs service_jumper
    PASS  R1 no overlap star_board vs switch_slide
    PASS  R1 no overlap star_board vs mic_inmp441
    PASS  R1 no overlap star_board vs cap_220u
    PASS  R1 no overlap star_board vs tact_button
    PASS  R1 no overlap star_board vs ptc_pair
    PASS  R1 no overlap star_board vs service_jumper
    PASS  R1 no overlap switch_slide vs mic_inmp441
    PASS  R1 no overlap switch_slide vs cap_220u
    PASS  R1 no overlap switch_slide vs tact_button
    PASS  R1 no overlap switch_slide vs ptc_pair
    PASS  R1 no overlap switch_slide vs service_jumper
    PASS  R1 no overlap mic_inmp441 vs cap_220u
    PASS  R1 no overlap mic_inmp441 vs tact_button
    PASS  R1 no overlap mic_inmp441 vs ptc_pair
    PASS  R1 no overlap mic_inmp441 vs service_jumper
    PASS  R1 no overlap cap_220u vs tact_button
    PASS  R1 no overlap cap_220u vs ptc_pair
    PASS  R1 no overlap cap_220u vs service_jumper
    PASS  R1 no overlap tact_button vs ptc_pair
    PASS  R1 no overlap tact_button vs service_jumper
    PASS  R1 no overlap ptc_pair vs service_jumper
    PASS  R2 oled_hosyond fully inside envelope (100.0% in)
    PASS  R2 holder_aceirmc fully inside envelope (100.0% in)
    PASS  R2 speaker_cap fully inside envelope (100.0% in)
    PASS  R2 provisional antenna region clears frame by 15.2 mm (>=15)
    PASS  R2 amp_hiletgo fully inside envelope (100.0% in)
    PASS  R2 reg_xl63070 fully inside envelope (100.0% in)
    PASS  R2 star_board fully inside envelope (100.0% in)
    PASS  R2 switch_slide fully inside envelope (100.0% in)
    PASS  R2 mic_inmp441 fully inside envelope (100.0% in)
    PASS  R2 cap_220u fully inside envelope (100.0% in)
    PASS  R2 tact_button fully inside envelope (100.0% in)
    PASS  R2 ptc_pair fully inside envelope (100.0% in)
    PASS  R2 service_jumper fully inside envelope (100.0% in)
    PASS  R3 keep-out clear of oled_hosyond
    PASS  R3 keep-out clear of holder_aceirmc
    PASS  R3 keep-out clear of speaker_cap
    PASS  R3 keep-out clear of amp_hiletgo
    PASS  R3 keep-out clear of reg_xl63070
    PASS  R3 keep-out clear of star_board
    PASS  R3 keep-out clear of switch_slide
    PASS  R3 keep-out clear of mic_inmp441
    PASS  R3 keep-out clear of cap_220u
    PASS  R3 keep-out clear of tact_button
    PASS  R3 keep-out clear of ptc_pair
    PASS  R3 keep-out clear of service_jumper
    PASS  R3 keep-out clear of frame tubes
    PASS  R4 USB corridor clear of oled_hosyond
    PASS  R4 USB corridor clear of holder_aceirmc
    PASS  R4 USB corridor clear of speaker_cap
    PASS  R4 USB corridor clear of amp_hiletgo
    PASS  R4 USB corridor clear of reg_xl63070
    PASS  R4 USB corridor clear of star_board
    PASS  R4 USB corridor clear of switch_slide
    PASS  R4 USB corridor clear of mic_inmp441
    PASS  R4 USB corridor clear of cap_220u
    PASS  R4 USB corridor clear of tact_button
    PASS  R4 USB corridor clear of ptc_pair
    PASS  R4 USB corridor clear of service_jumper
    PASS  R5 holder_aceirmc <-> supermini clearance 15.4 mm (>= 3.0)
    PASS  R5 holder_aceirmc <-> oled_hosyond clearance 10.1 mm (>= 1.5)
    PASS  R5 holder_aceirmc <-> speaker_cap clearance 2.0 mm (>= 2.0)
    PASS  R5 holder_aceirmc <-> cap_220u clearance 2.7 mm (>= 2.0)
    PASS  R5 holder_aceirmc <-> ptc_pair clearance 2.8 mm (>= 2.0)
    PASS  R5 amp_hiletgo <-> reg_xl63070 clearance 11.0 mm (>= 2.0)
    PASS  R5 speaker_cap <-> mic_inmp441 clearance 12.5 mm (>= 3.0)
    PASS  R5 speaker_cap <-> oled_hosyond clearance 3.4 mm (>= 0.5)
    PASS  R5 reg_xl63070 <-> oled_hosyond clearance 2.9 mm (>= 1.5)
    PASS  R6 cell removal path clear of oled_hosyond
    PASS  R6 cell removal path clear of speaker_cap
    PASS  R6 cell removal path clear of supermini
    PASS  R6 cell removal path clear of amp_hiletgo
    PASS  R6 cell removal path clear of reg_xl63070
    PASS  R6 cell removal path clear of star_board
    PASS  R6 cell removal path clear of switch_slide
    PASS  R6 cell removal path clear of mic_inmp441
    PASS  R6 cell removal path clear of cap_220u
    PASS  R6 cell removal path clear of tact_button
    PASS  R6 cell removal path clear of ptc_pair
    PASS  R6 cell removal path clear of service_jumper
    PASS  R7 jumper access clear of oled_hosyond
    PASS  R7 jumper access clear of holder_aceirmc
    PASS  R7 jumper access clear of speaker_cap
    PASS  R7 jumper access clear of supermini
    PASS  R7 jumper access clear of amp_hiletgo
    PASS  R7 jumper access clear of reg_xl63070
    PASS  R7 jumper access clear of star_board
    PASS  R7 jumper access clear of switch_slide
    PASS  R7 jumper access clear of mic_inmp441
    PASS  R7 jumper access clear of cap_220u
    PASS  R7 jumper access clear of tact_button
    PASS  R7 jumper access clear of ptc_pair
    PASS  R1 no overlap oled_hosyond vs frame tubes
    PASS  R1 no overlap holder_aceirmc vs frame tubes
    PASS  R1 no overlap speaker_cap vs frame tubes
    PASS  R1 no overlap supermini vs frame tubes
    PASS  R1 no overlap amp_hiletgo vs frame tubes
    PASS  R1 no overlap reg_xl63070 vs frame tubes
    PASS  R1 no overlap star_board vs frame tubes
    PASS  R1 no overlap switch_slide vs frame tubes
    PASS  R1 no overlap mic_inmp441 vs frame tubes
    PASS  R1 no overlap cap_220u vs frame tubes
    PASS  R1 no overlap tact_button vs frame tubes
    PASS  R1 no overlap ptc_pair vs frame tubes
    PASS  R1 no overlap service_jumper vs frame tubes

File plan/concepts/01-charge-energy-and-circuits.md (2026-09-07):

# 01 — Charge, energy, and a complete circuit

[Concept index](README.md) · [Day 1 lab](../DAILY_STUDY_AND_LAB_PLAN.md#day-1--system-map-safety-and-a-green-software-baseline)

**Question:** What actually moves, and what does a component “use up”?

## Start with the physical picture

Matter contains positive and negative **electric charge**. Electrons carry
negative charge; some electrons in a metal can move through it. The wire
already contains these carriers before you connect a supply. Charge is a
property of matter, not another name for energy.

An **electric field** exerts a force on charge. A powered source maintains a
voltage difference between its terminals; the field established in a connected
circuit drives an average movement of charge. That flow is **current**.
This is the starting point of the
[charge model](https://openstax.org/books/college-physics-2e/pages/18-1-static-electricity-and-charge-conservation-of-charge).

Schematic arrows show **conventional current**: the direction positive charge
would move. Electron drift in a metal is opposite that arrow. Use conventional
current consistently; you do not need to track individual electrons.

Two circuits with the same 3.3 V source and 1 kilohm resistor: a closed switch allows 3.3 mA around a complete loop; an open switch leaves voltage across the break but no steady current.

*Ideal DC model: an open circuit can have voltage even though its current is zero.*

## Energy is transferred; charge is not consumed

A source supplies electrical **energy**, measured in joules (`J`). A resistor
converts electrical energy into heat; an OLED also produces light. Neither
destroys the charge flowing through it.

At steady state in this one-loop circuit, the current entering the resistor
equals the current leaving it. There is no “used-up current” on the return wire.

**Voltage** tells you the energy change per unit charge between two points:
`1 volt = 1 joule per coulomb`. A coulomb (`C`) is a unit of charge.
See [potential difference](https://openstax.org/books/college-physics-2e/pages/19-1-electric-potential-energy-potential-difference).

**Example:** If `0.002 C` passes through a resistor with `3.3 V` across it,
the energy converted is `3.3 J/C × 0.002 C = 0.0066 J`. The same amount of
charge enters and leaves; its electrical potential energy changes.

## Ground and rails are names for connections

A **node** is a set of directly joined conductors treated as one electrical
point. **GND** names the node we choose as the `0 V` reference. It is not a
drain that swallows current, nor automatically Earth or the brass frame.

A **power rail** is a shared supply connection, such as the controller's
`3.3 V` output feeding several peripherals. Each peripheral also needs a return.

```text
3.3 V rail ──┬── OLED ──┬── GND return
             └── mic ───┘
```

*The two devices are branches between the same supply and return nodes.*

For your prototype, think **source → load → return → source** before thinking
about code. A signal wire describes information, but it is still an electrical
connection referenced to another node. Follow the daily lab for wiring and
power limits; this picture is not a replacement wiring guide.

## Predict before opening the answer

With the switch open, does “no current” prove that every point is at `0 V`?

<details>
<summary>Answer</summary>

No. In the ideal drawing, the source still maintains `3.3 V`; that voltage
appears across the open switch. An open path stops steady current, not the
existence of voltage. Disconnect power before changing wiring.

</details>

**Next:** [voltage, current, resistance, and power](02-voltage-current-resistance-and-power.md).
For more detail, see [Lesson 01](../../edu/fundamentals/01-units-charge-voltage-current-power-energy-heat.md).

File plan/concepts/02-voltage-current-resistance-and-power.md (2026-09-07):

# 02 — Voltage, current, resistance, and power

[Concept index](README.md) · [Day 2 lab](../DAILY_STUDY_AND_LAB_PLAN.md#day-2--voltage-current-resistance-power-and-units)

**Question:** How do the physical ideas become useful calculations?

Read [charge and complete circuits](01-charge-energy-and-circuits.md) first
if those words are still unfamiliar.

## Four quantities, four different questions

| Quantity | What it asks | Unit |
| --- | --- | --- |
| Voltage `V` | Energy change **per charge**, between which two points? | volt, `J/C` |
| Current `I` | How much charge passes a point **per second**? | ampere, `C/s` |
| Resistance `R` | For this resistor, how much voltage is needed for a given current? | ohm, `Ω = V/A` |
| Power `P` | How much energy is transferred **per second**? | watt, `J/s` |

`Δ` means “change in,” so `I = ΔQ/Δt` gives the **average current** over an
interval: charge moved divided by elapsed time. For steady current, this is
also its value at every instant. For an **ohmic resistor at fixed conditions**, measurements follow
`V = IR`: voltage and current change in proportion. This is a material model,
not a rule that every component has one constant resistance.
[Ohm's law](https://openstax.org/books/college-physics-2e/pages/20-2-ohms-law-resistance-and-simple-circuits)
describes that relationship.

A resistor has voltage measured between its ends and current flowing through it. Beside it, a straight current-versus-voltage graph for a 1 kilohm resistor marks 3.3 V at 3.3 mA and 6.6 V at 6.6 mA.

*One resistor, fixed temperature: doubling voltage doubles current. The graph is a calculation, not an instruction to raise the lab supply.*

## Why a resistor heats up

The field drives carriers through the material. Interactions with its atomic
structure transfer energy to the material's thermal motion. Charge is not
lost; electrical energy becomes heat. The resistor's resistance and its
**power rating** therefore answer different questions.

For steady voltage and current, the units explain the power equation:

```text
P = V × I = (joules/coulomb) × (coulombs/second) = joules/second
```

Using `V = IR`, you can also write `P = I²R` or `P = V²/R` for that resistor.
These are substitutions, not three unrelated formulas to memorize.

## One complete example

Use the nominal values for a prediction; the lab uses your measured values.

```text
R = 1 kΩ = 1,000 Ω
I = 3.3 V / 1,000 Ω = 0.0033 A = 3.3 mA
P = 3.3 V × 0.0033 A = 0.01089 W ≈ 10.9 mW
Energy in 10 s = P × time = 0.1089 J
```

`k` means ×1,000; `m` means ÷1,000; `µ` means ÷1,000,000. Convert prefixes
before multiplying. A `¼ W` resistor's rating is not its actual dissipation;
here the predicted dissipation is much smaller. Temperature also depends on
how well heat escapes, not only on watts.

## The engineering decision

A `20 mA` supply **current limit** is a ceiling, not a command to push `20 mA`
through the resistor. This load should draw about `3.3 mA`. If a supply reaches
its limit, it generally reduces voltage; `3.3 V` may no longer describe the
actual circuit. Stop and investigate instead of raising the limit.

## Predict before opening the answer

At the same `3.3 V`, changing `1 kΩ` to `2 kΩ` does what to current and power?

<details>
<summary>Answer</summary>

Both halve: `I = 1.65 mA`, and `P ≈ 5.45 mW`. Conversely, doubling voltage
across the original resistor doubles current but **quadruples power**, because
`P = V²/R`.

</details>

**More depth:** [Lesson 01](../../edu/fundamentals/01-units-charge-voltage-current-power-energy-heat.md).

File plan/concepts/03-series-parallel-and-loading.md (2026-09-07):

# 03 — Series, parallel, rails, and divider loading

[Concept index](README.md) · [Day 3 lab](../DAILY_STUDY_AND_LAB_PLAN.md#day-3--series-parallel-kvl-kcl-and-divider-loading)

**Question:** Where do equivalent resistance and the divider formula come from?

Start with [Ohm's law and units](02-voltage-current-resistance-and-power.md).

## Two conservation rules

**KCL — Kirchhoff's current law:** total current entering a node equals total
current leaving it. This is charge accounting; include every branch, including
a capacitor branch when present.

**KVL — Kirchhoff's voltage law:** voltage rises and drops around a closed
loop add to zero in our small, lumped-circuit model. This is energy-per-charge
accounting. A `3.3 V` source rise can balance drops of `2.2 V` and `1.1 V`.

A **rail** is a shared supply node. Its incoming current is the sum of the
branch currents, not necessarily the current at every point along the wire:

```text
I_rail → ●──→ I_OLED
         ├──→ I_mic
         └──→ I_controller

I_rail = I_OLED + I_mic + I_controller
```

*Each load also returns current to the source through the GND network, omitted here.*

## Equivalent means “the same from two terminals”

Replace a resistor network with one resistor that draws the **same total
current at the same applied voltage**. Thus `R_eq = V_AB / I_total`, where
`V_AB` is the voltage between terminals A and B. Internal branch currents need
not be equal: the equivalence is what the source sees.

Series and parallel two-terminal resistor networks. Two 10 kilohm resistors in series give 20 kilohms; the same resistors connected between two common nodes in parallel give 5 kilohms.

*Series means one unbranched path; parallel means the same two end nodes. Physical placement on a breadboard is not the definition.*

<details>
<summary>Derive both results instead of memorizing them</summary>

**Series:** the current `I` is the same through both resistors. KVL gives
`V_AB = IR1 + IR2 = I(R1 + R2)`. Divide by `I`:
`R_eq = R1 + R2`.

**Parallel:** both branches have voltage `V_AB`. Ohm's law and KCL give
`I_total = V_AB/R1 + V_AB/R2`. Substitute `I_total = V_AB/R_eq` and cancel
nonzero `V_AB`:

```text
1/R_eq = 1/R1 + 1/R2
R_eq = (R1 × R2)/(R1 + R2)   [two resistors only]
```

`R1 ∥ R2` means “the equivalent resistance of R1 in parallel with R2.”
For two `10 kΩ` branches, `R_eq = 5 kΩ`: twice the current can flow at the
same voltage. With positive finite resistances, parallel resistance is below
either branch resistance.

</details>

## A divider changes when you connect a load

With negligible load, the two resistors carry one current:
`I = Vin/(R1 + R2)`. The output is the voltage across the lower resistor:
`Vout = IR2 = Vin × R2/(R1 + R2)`.

An unloaded 10 kilohm plus 10 kilohm divider gives 1.65 V from 3.3 V. Adding a 10 kilohm load from the output to ground makes the lower equivalent resistance 5 kilohms and reduces the output to 1.10 V.

*The new load shares both nodes with R2, not with R1.*

Loaded result: `Vout = 3.3 × 5/(10 + 5) = 1.10 V`. The top resistor carries
`220 µA`, which splits into `110 µA` through R2 and `110 µA` through the load.
KCL still balances. The unloaded current was only `165 µA`.

**Prototype lesson:** a divider can set a sensing voltage, but it does not
hold that voltage against arbitrary module current. Do not use one to power
the OLED or controller.

## Predict before opening the answer

If the load is removed, does the output return to `1.65 V` or stay at `1.10 V`?

<details>
<summary>Answer</summary>

It returns to `1.65 V` in this ideal steady-state model. Removing the load
restores `10 kΩ` as the lower resistance. This is a paper prediction; unplug
power before changing the lab wiring.

</details>

**More depth:** [Lesson 02](../../edu/fundamentals/02-dc-circuits-ohm-kirchhoff-series-parallel.md),
including unequal resistors; textbook reference:
[series and parallel networks](https://openstax.org/books/college-physics-2e/pages/21-1-resistors-in-series-and-parallel).

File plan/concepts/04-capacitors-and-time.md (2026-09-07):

# Capacitors: electric fields and time

[Concept index](README.md) · [Day 4 lab](../DAILY_STUDY_AND_LAB_PLAN.md#day-4--components-and-an-observable-rc-time-constant)

Optional reading · about 5 minutes · builds on voltage, current, and resistance.

## The physical idea

A capacitor has two conductors separated by an insulator, the **dielectric**.
Charging moves electrons through the external wires: one conductor gains
electrons while the other loses them. The resulting charge separation creates
an electric field. Electrons do **not** travel through an ideal dielectric.

A capacitor stores separated charge across an insulating gap. A complete circuit connects a source through a resistor to the capacitor, with a return wire to the source.

For a fixed capacitance:

```text
Q = C × V            charge = capacitance × voltage
i = C × dV/dt        current = capacitance × rate of voltage change
E = ½ × C × V²       stored energy, in joules
```

`C` is measured in farads (F); `Q` in coulombs. Without calculus, read the
middle equation as `average current = C × ΔV / Δt` over a time interval.
More current changes the voltage faster; more capacitance makes the same
current change it more slowly. An ideal capacitor carries no steady DC
current once its voltage stops changing. Real ones leak a little.

A capacitor stores electric-field energy; a battery stores energy through
electrochemical reactions. Neither creates energy, and their discharge
behavior is different.

## Why the charging curve bends

At the start, an uncharged capacitor has `V_C = 0`. Most of the source voltage
is across the resistor, so current is largest. As `V_C` rises, resistor voltage
and current fall: `i = (V_source − V_C) / R`. Charging therefore slows down.

Ideal charging curve for a 100 kilohm resistor and 100 microfarad capacitor on a 3.3 volt source: 2.09 volts at 10 seconds, approaching 3.3 volts without overshooting.

The **time constant**, `τ` (tau), is `R × C`. Ohms times farads gives seconds.
After one `τ`, an initially uncharged capacitor reaches about **63%** of its
final voltage—not 63% more on every interval.

## One worked example

Day 4 uses `100 kΩ` and `100 µF` with a `3.3 V` source:

```text
τ = 100,000 Ω × 0.000100 F = 10 seconds
V_C(10 s) = 3.3 × (1 − e⁻¹) ≈ 2.09 V
V_C(50 s) = 3.3 × (1 − e⁻⁵) ≈ 3.28 V
```

This prediction assumes constant supply voltage, an initially discharged
capacitor, and negligible loading. Component tolerance, leakage, and the
voltmeter can change your observations.

## In your prototype

A nearby **decoupling capacitor** supplies some current during brief load
changes, reducing rail dips while the supply responds. Short connections
matter because real wires also resist changing current. It cannot compensate
for an inadequate supply indefinitely.

Power off does not guarantee zero stored charge. Check polarity and voltage
rating, and follow the existing Day 4 discharge procedure; never short the
capacitor with a wire.

<details>
<summary>Check yourself: if resistance doubles but capacitance stays the same, what changes?</summary>

The time constant doubles: charging takes twice as long to reach each
fraction of its final voltage. The ideal final voltage remains 3.3 V.

</details>

Go deeper: [Lesson 03: capacitors, RC timing, and the existing battery-free lab](../../edu/fundamentals/03-components-rc-diodes-mosfets-converters.md#capacitors).

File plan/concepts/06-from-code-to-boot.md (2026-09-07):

# Day 6 — From code to a running controller

[Concept index](README.md) · [Day 6 lab](../DAILY_STUDY_AND_LAB_PLAN.md#day-6--exact-part-evidence-and-bare-controller-boot)

## The physical idea

Your C++ source is a description, not something a chip can directly execute.
The compiler translates it into machine instructions. A linker places code
and data into an image; flashing stores the image in the board's nonvolatile
memory. **Nonvolatile** means it retains information without power. RAM is
working memory and does not retain the running program's state after power is
removed.

Physically, transistor circuits implement the logic that moves and transforms
bits. A clock coordinates operations, and the power supply provides the energy
for switching. Correct instructions cannot compensate for a missing supply or
an unstable reset signal. Think of firmware and hardware as two sides of one
execution environment—not as independent products.

Source and pinned tools produce a verified image; USB writes flash; reset enters ROM, a bootloader, then the diagnostic application.

*Building changes a file on your computer. Flashing changes memory on the
board. Resetting starts execution; monitoring only observes its messages.*

## The engineering idea: isolate each stage

A successful build proves that the selected source and tools can produce an
image. A matching checksum proves that bytes match a recorded image. Neither
proves that an OLED is correctly wired or that a microphone works.

At reset, the chip starts with built-in ROM code. Its boot selection can lead
to the download path or to the flash bootloader and application. That is why
the onboard BOOT control is different from your application's action button:
the recovery path must work before your application runs.

Use the project's scripts for the exact image, addresses, and boot procedure;
this sketch is a mental model, not a replacement flashing command.

## One small example

A **hypothetical** `512 KiB` application needs:

```text
512 × 1,024 = 524,288 bytes
524,288 × 8 = 4,194,304 bits
```

That is storage capacity, not the amount of RAM it needs or how fast it runs.
Flash partitions also reserve space for other content, so total flash size is
not identical to available application space.

## In your pocket prototype

The first target is the bare controller producing a stable **offline
diagnostic log**, not a complete AI conversation. Missing peripherals are
expected. Add one tested peripheral at a time using the
[USB quickstart](../../docs/PROTOTYPE_QUICKSTART.md). No extra parts or cloud
account are needed for that first result.

**Predict:** The image checksum matches, but the board repeatedly resets. Has
the checksum proved that the power and wiring are good?

<details>
<summary>Answer</summary>

No. It verified image identity only. Reset logs and the bare-board setup help
separate application faults, power problems, and attached-peripheral problems.
Keep each claim tied to what its test actually observes.

</details>

For more: [Lesson 04 — Boards, pinouts, and datasheets](../../edu/fundamentals/04-boards-schematics-datasheets-and-connectors.md).

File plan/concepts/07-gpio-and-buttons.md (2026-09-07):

# Day 7 — How a button becomes a bit

[Concept index](README.md) · [Day 7 lab](../DAILY_STUDY_AND_LAB_PLAN.md#day-7--digital-logic-and-the-action-button)

## The physical idea

A GPIO input does not receive the abstract value `true`. It senses a voltage
relative to the controller's ground. Voltages below the guaranteed LOW limit
count as LOW; voltages above the HIGH limit count as HIGH. The region between
those limits has no guaranteed interpretation. A digital input is therefore
an analog circuit with a digital interpretation.

An input draws little current, but it still has capacitance and leakage. If
left disconnected, nearby electric fields and tiny leakage currents can change
its voltage. That is a **floating input**: its reading is not a reliable
default, even if it happens to look stable today.

An active-low button connects a pulled-up GPIO to ground; the voltage scale distinguishes LOW, an undefined region, and HIGH.

*The resistor sets the released state. Closing the button provides a much
lower-resistance path to ground. Its current returns through the supply.*

## The engineering idea: choose a default

A **pull-up** is a weak resistive connection to the positive logic supply.
With the button open, it brings the input near 3.3 V. With the button closed,
the switch holds the input near ground and the resistor limits current.
The result is **active-low**: pressed means LOW, so firmware interprets
`pressed = !pin_level`.

A push-pull output is different: it actively drives HIGH or LOW. Do not connect
an output configured HIGH directly to a button that shorts it to ground. The
GPIO must be configured as an input for this circuit. Likewise, do not feed
5 V into a 3.3 V controller GPIO.

Mechanical contacts can bounce—briefly opening and closing several times
during one press. Debouncing filters those rapid transitions so one physical
press becomes one application event. A pull-up fixes the default voltage;
debouncing fixes repeated transitions. They solve different problems.

## One small example

For an **illustrative external** 10 kΩ pull-up:

```text
button released: almost no steady input current
button pressed:  I = 3.3 V / 10,000 Ω = 0.33 mA
```

This is an Ohm's-law example, not an instruction to add that resistor. The
prototype firmware already enables GPIO10's internal pull-up, whose resistance
is not assumed to be 10 kΩ.

## In your pocket prototype

GPIO10 is the external action button; the onboard GPIO9 BOOT button is for
recovery. Wire only with USB disconnected, following the
[quickstart](../../docs/PROTOTYPE_QUICKSTART.md#add-the-button-and-oled).
A four-leg tactile switch often contains two permanently connected pairs:
identify which contacts actually switch before using them.

**Predict:** If the pull-up is removed while the button is released, must the
input read LOW?

<details>
<summary>Answer</summary>

No. Without another bias path it floats. An open circuit is not a connection
to ground, and “no current” does not mean “zero voltage.”

</details>

For more: [Lesson 07 — GPIO, pull resistors, and boot straps](../../edu/fundamentals/07-digital-logic-gpio-pullups-boot-straps.md).

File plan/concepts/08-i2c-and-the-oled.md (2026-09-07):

# Day 8 — Why two I2C wires need resistors

[Concept index](README.md) · [Day 8 lab](../DAILY_STUDY_AND_LAB_PLAN.md#day-8--i2c-and-the-oled)

## The physical idea

The OLED receives commands and pixel data over I2C: **SDA** carries data and
**SCL** provides timing. Both are shared open-drain signals: a device can pull
a line LOW or release it. A pull-up resistor restores HIGH. This differs from
a push-pull output, which actively drives both levels. Nobody should fight a
LOW by actively forcing HIGH on this bus.

Wires and input pins store a small amount of charge: together they act like a
capacitor. After release, the resistor must charge that capacitance, so the
voltage rises gradually. This is the same RC behavior as
[Day 4](04-capacitors-and-time.md), now happening much faster.

A pull-up charges the shared SDA wire when both open-drain switches release it; either switch can pull LOW. A curve shows the slower RC rise.

*One signal line is shown; SCL also needs its own pull-up. “Two wires” excludes
the supply and common ground connections.*

## The engineering idea: timing is a voltage requirement

A receiver needs the line to become reliably HIGH before it samples the bit.
Longer wiring generally adds capacitance; more capacitance means a slower
rise for the same resistance. Reducing resistance speeds the rise but increases
the current a device must sink while holding LOW. So “use the smallest
resistor” is not a complete design rule.

For I2C's 30%–70% rise-time definition, `t_r ≈ 0.847 × R × C`.
Fast-mode at 400 kHz allows up to 300 ns. These requirements come from the
[NXP I2C specification, sections 6 and 7](https://www.nxp.com/docs/en/user-guide/UM10204.pdf).

## One small example

Assume **illustrative**, not measured, values:

```text
R = 10 kΩ; C = 100 pF
t_r ≈ 0.847 × 10,000 × 100 × 10⁻¹² seconds
    ≈ 847 ns
```

That exceeds the 400 kHz rise-time limit. Short working wires and an address
response are useful observations, but neither measures the actual rise time.
Do not add resistors blindly: the OLED carrier may already contain pull-ups,
and additional ones would be in parallel.

## In your pocket prototype

The current source uses GPIO21/SDA and GPIO20/SCL and tries OLED addresses
`0x3C` and `0x3D`. An address is a digital identifier, not a voltage. Treat the
[quickstart pin map](../../docs/PROTOTYPE_QUICKSTART.md#add-the-button-and-oled)
as the wiring instructions.

An **ACK** is the addressed device's acknowledgement. It proves a response at
that address, not that every pixel works. The all-on/all-off test adds that
different observation. With no display connected, headless operation keeps
the rest of the diagnostic program running.

**Predict:** If capacitance doubles but resistance stays the same, what
happens to rise time?

<details>
<summary>Answer</summary>

It approximately doubles because `t_r` is proportional to `RC`. Firmware
cannot remove that electrical delay by calling the same write function again.

</details>

For more: [Lesson 08 — I2C transactions and OLED diagnosis](../../edu/fundamentals/08-i2c-and-the-oled.md).

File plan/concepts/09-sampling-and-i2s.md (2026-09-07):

# Day 9 — From air pressure to audio numbers

[Concept index](README.md) · [Day 9 lab](../DAILY_STUDY_AND_LAB_PLAN.md#day-9--i2s-clocks-and-microphone-input)

## The physical idea

Sound is a changing air pressure. Inside a MEMS microphone, pressure moves a
tiny diaphragm; electronics turn that movement into an electrical signal and
then numbers. **Sampling** chooses when to measure. **Quantization** represents
each measured value using one of a finite set of codes. Neither requires you
to design the microphone's internal converter.

A smooth pressure waveform is sampled at evenly spaced instants and its sample heights are represented on a finite set of amplitude levels.

*Dots show selected instants. Amplitude levels are deliberately coarse to make
rounding visible; this is not the microphone's actual resolution.*

More samples per second preserve faster changes. More bits per sample provide
more amplitude codes. These are different axes of detail. More bits do not
remove microphone noise, and a 32-bit storage container does not imply 32 bits
of useful acoustic information.

**Aliasing** means different continuous waveforms can produce identical
samples. At 16,000 samples/s, the theoretical Nyquist boundary is 8,000 Hz;
the usable band must stop below it. Filtering before the relevant sampling
or downsampling step limits frequencies that would fold into the wanted band.
Once aliased, those components cannot be uniquely separated from the wanted
signal using those samples alone.

## The engineering idea: numbers need a transport format

I2S is a timed stream, not the OLED's addressed I2C bus. BCLK advances the bit
positions, WS identifies left/right timing, and SD carries microphone data.
There is no per-sample acknowledgement or address scan.

An I2S frame contains 32 clock periods for each left and right interval; an inset shows the new sample's most significant bit one clock after the word-select edge.

*The controller consumes the selected left channel. The wire still carries
two 32-clock intervals per frame; mono capture does not halve this clock.*

The owned INMP441 supplies 24-bit samples using 64 clocks per frame. Its L/R
selection chooses the active channel; it is not an I2C address.
See the [TDK INMP441 datasheet](https://invensense.tdk.com/wp-content/uploads/2015/02/INMP441.pdf).
Standard I2S places a word's most-significant bit one BCLK period after the WS
change, per the [NXP I2S specification](https://www.nxp.com/docs/en/user-manual/UM11732.pdf).

## One small example

```text
sample interval = 1 / 16,000 = 62.5 µs
BCLK = 16,000 frames/s × 2 intervals/frame × 32 clocks/interval
     = 1,024,000 clocks/s = 1.024 MHz
```

The 24 meaningful data bits do not replace the 32-clock transport interval.

## In your pocket prototype

The [microphone-only lab](../../docs/PROTOTYPE_QUICKSTART.md#add-the-microphone)
uses WS/GPIO1, BCLK/GPIO2, and microphone data/GPIO4. Serial min/max and RMS
levels should change with speech. RMS summarizes signal magnitude; it is not
a calibrated sound-pressure reading. Keep the amplifier disconnected.

**Predict:** Does receiving changing numbers prove that the sample rate and
bit alignment are correct?

<details>
<summary>Answer</summary>

No. It is evidence of changing captured data. Configuration checks and, when
available, timing measurements test different claims. Misaligned samples can
still vary.

</details>

For more: [Lesson 09 — Digital audio timing and sampling](../../edu/fundamentals/09-i2s-sampling-and-digital-audio.md).

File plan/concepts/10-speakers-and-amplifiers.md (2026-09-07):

# Day 10 — Turning information into moving air

[Concept index](README.md) · [Day 10 lab](../DAILY_STUDY_AND_LAB_PLAN.md#day-10--class-d-btl-speaker-limits-and-the-audio-gate)

## The physical idea

Microphone data describes sound; it does not carry enough power to drive a
speaker. An amplifier draws energy from its supply and controls how that
energy reaches the speaker, following the audio signal.

In a moving-coil speaker, current in a coil interacts with a magnetic field
and produces force. The coil moves a diaphragm, which changes the surrounding
air pressure. Electrical resistance also turns some energy into heat. The
speaker therefore has electrical, mechanical, and thermal limits—not just a
maximum volume setting.

Audio data controls a supply-powered amplifier; its OUT+ and OUT− terminals drive the speaker between them, with no connection from either output to ground.

*Information chooses the motion; the supply pays its energy cost. This is a
conceptual future audio path, not today's wiring: leave the amplifier and
speaker disconnected in the beginner prototype.*

## The engineering idea: neither speaker lead is ground

A Class-D amplifier uses rapidly switching output transistors to control
power efficiently. Switching still causes losses, heat, and electrical noise.
The speaker's electrical and mechanical behavior responds mainly to the
audio-band part of that drive; “Class-D” does not mean the speaker moves only
between two positions.

**BTL**, or bridge-tied load, places the speaker between two actively driven
outputs:

```text
V_speaker = V_OUT+ − V_OUT−
```

For example, if those terminal voltages are 3 V and 1 V relative to circuit
ground at some instant, the speaker sees 2 V. Reversing the two voltages gives
−2 V. Neither terminal has to become negative relative to ground to reverse
the speaker's voltage.

Never ground either output or attach a grounded instrument clip to it. The
MAX98357A also requires valid audio clocks: losing WS while BCLK continues can
cause dangerous DC output. See the [manufacturer's datasheet](https://www.analog.com/media/en/technical-documentation/data-sheets/max98357a-max98357b.pdf).
Do not create powered clock-disconnection experiments.

## One small power example

Treating an 8 Ω speaker as a resistor **only for an estimate**:

```text
P = V_rms² / R
At 0.8 W: V_rms = √(0.8 × 8) ≈ 2.53 V across the speaker
```

RMS is the voltage with the same resistor-heating effect as that DC voltage.
Real speaker impedance varies with frequency; this result is neither a safe
volume setting nor permission to apply 2.53 V DC. A speaker's measured DC
resistance and its nominal AC impedance need not be equal.

## In your pocket prototype

You can learn these ideas with unpowered inspection and calculations while
the USB controller, OLED, and microphone remain useful. Default firmware keeps
the amplifier disabled. Audio power integration is a later, separately checked
step—not a prerequisite for learning or for microphone capture.

**Predict:** What happens to the resistive power estimate if RMS voltage
doubles?

<details>
<summary>Answer</summary>

Power becomes four times larger because voltage is squared. A small increase
in voltage can therefore make a large difference to heating.

</details>

For more: [Lesson 10 — Speakers, power, and acoustics](../../edu/fundamentals/10-class-d-btl-speakers-and-acoustics.md).

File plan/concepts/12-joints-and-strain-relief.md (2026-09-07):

# 12 — Strain relief: give forces another path

[Concept index](README.md) · [Day 12 lab](../DAILY_STUDY_AND_LAB_PLAN.md#day-12--wire-joints-strain-relief-and-controlled-rework)

**The idea:** an electrical connection and a mechanical anchor have different
jobs. A wire can conduct perfectly today yet break after repeated movement.

## Force, stress, and strain

A **force** is a push or pull, measured in newtons (`N`). **Stress** describes
how concentrated an internal force is: for simple uniform tension,
`stress = force / cross-sectional area`. **Strain** is relative deformation:
`strain = change in length / original length`.

At a soldered wire, flexible strands become a comparatively rigid section.
Bending tends to concentrate near that transition. Repeated bending can grow
small cracks: this is **fatigue**, and it can happen without a single dramatic
tug. Solder that wicks farther up a stranded wire lengthens its rigid region;
it does not automatically make the assembly more durable.

Without an anchor a cable pull reaches the solder pad; with an anchor the support takes the load and a slack loop protects the connection.

*These arrows show mechanical force, not current. A support must actually hold
the cable; covering it is not enough.*

**Strain relief** transfers cable loads into a support before they reach the
delicate electrical joint. A supported cable jacket and a small service loop
let the connection remain relatively still. An insulating sleeve prevents
electrical contact; it is not necessarily an anchor. Heat-shrink can stiffen
and protect a splice, but bending can simply move to its edge.

## A lever example

A sideways force also produces a turning effect, called a **moment** or
**torque**:

```text
moment = force × perpendicular distance from the pivot
M = F × d
```

In a simplified rigid-lever model, a `1 N` force applied `20 mm` from a pad
produces `1 × 0.020 = 0.020 N·m`. Applied at `5 mm`, it produces
`0.005 N·m`: one quarter as much. Real flexible wires bend, so these are
illustrative values, not a pad's safe-load rating. The useful insight is to
intercept movement before a pad becomes the cable's pivot.

## Why it matters for your prototype

Use only Day 12's unpowered sacrificial samples for the gentle supported versus
unsupported comparison. Notice **where** bending occurs; do not try to break
a project module or pull the speaker's fine factory leads. Reserve wire slack
for unplugging and inspection instead of making every connection taut.

Rework is another heating cycle, not an unlimited undo button. After a practice
joint is restored, inspect for loosened pads, bridges, and damaged insulation;
repeat continuity and isolation checks with sources absent. A continuity beep
does not show fatigue resistance or prove a joint can carry substantial current.

## Predict before reading

A wire has heat-shrink over its soldered end but no anchor. Is the pad now
protected from an external cable pull?

<details>
<summary>Answer</summary>

Not necessarily. If the only force path still ends at the pad, the pad still
takes the pull. Insulation, local stiffening, and strain relief are related but
different functions. Look for the separate support that carries the load.

</details>

Go deeper: [Lesson 12 — wire support and insulation](../../edu/fundamentals/12-soldering-mechanics-insulation-tolerance.md#wires-need-mechanical-support).

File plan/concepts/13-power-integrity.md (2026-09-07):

# 13 — Power integrity: a rail is not an ideal source

[Concept index](README.md) · [Day 13 lab](../DAILY_STUDY_AND_LAB_PLAN.md#day-13--power-integrity-without-a-battery)

**The idea:** a rail must deliver the right voltage *at the load*, including
when the load's current suddenly changes. A label saying `3V3` is a target,
not a guarantee.

## Follow both sides of the loop

A **rail** is a shared supply connection. Current leaves the source, passes
through loads, and returns through ground wiring. Real wires, connectors, and
contacts have resistance; a current creates voltage drops in both outgoing
and return paths. Fast changes also encounter **inductance**, the property that
opposes changes in current. Together, these effects contribute to **impedance**:
opposition to current that can depend on frequency.

A source powers a load through outgoing and return resistance; a local capacitor supplies part of a brief current pulse through a short local loop.

*The capacitor is across the load, not in series. Right: illustrative timing,
not a measurement of your board.*

At a junction, KCL still applies. During a brief increase in demand:

```text
current into load = current from source + current from local capacitor
```

The capacitor's stored electric-field energy supports the rail temporarily.
Its voltage falls as it supplies charge; afterward, the source replenishes it.
A nearby capacitor makes the fast current loop short. It cannot replace a
source capable of supplying the long-term average load.

## Two paper calculations

First, assume an ideal `3.3 V` source and `0.50 Ω` total outgoing-plus-return
resistance. A sustained `0.20 A` load gives:

```text
path drop = I × R = 0.20 × 0.50 = 0.10 V
voltage across load = 3.30 − 0.10 = 3.20 V
```

Separately, suppose an ideal `100 µF` capacitor alone supplies an extra
`0.10 A` for `100 µs`:

```text
Q = C × V and I = ΔQ / Δt
so voltage decrease ΔV = I × Δt / C
ΔV = 0.10 × 0.000100 / 0.000100 = 0.10 V
```

These are simplified examples, not measured pager demands. Real behavior also
depends on capacitor resistance, inductance, wiring, and source response.
Do not blindly add these two examples into a single predicted waveform.

## Why it matters for your prototype

A multimeter reading near 3.3 V can miss brief dips. A reset log can provide a
clue; it does not measure the dip. Use existing diagnostics and the Day 13
resistor-load exercise, not a newly improvised amplifier load test.

Keep USB `5V`, regulated `3V3`, and possible battery power distinct. Regulation
sets voltage; current limiting limits current; charging manages a cell's charge;
source isolation controls unwanted current between supplies. None implies the
others. This lesson does not authorize joining supplies or connecting a cell.

## Predict before reading

If the same capacitor must supply the same current for twice as long, what
happens to its ideal voltage decrease?

<details>
<summary>Answer</summary>

It doubles because `ΔV = I × Δt / C`. A bigger capacitor can help temporarily,
but any finite capacitor eventually runs down under sustained demand.

</details>

Go deeper: [Lesson 06 — source impedance and decoupling](../../edu/fundamentals/06-li-ion-power-integrity-decoupling-uvlo-thermal.md#source-impedance-is-more-than-a-resistor).

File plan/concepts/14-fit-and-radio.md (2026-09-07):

# 14 — Fit and radio: parts need space beyond their outlines

[Concept index](README.md) · [Day 14 lab](../DAILY_STUDY_AND_LAB_PLAN.md#day-14--rf-awareness-and-a-11-nonconductive-mock-up)

**The idea:** “the rectangles fit” is only the beginning. Real parts vary in
size, connectors need a path in and out, and antennas interact with nearby
materials without touching them.

## Fields are part of the hardware

An antenna turns rapidly changing electrical currents into electromagnetic
fields, and incoming fields into electrical signals. The antenna, its circuit
board, and its surroundings form a system. Metal nearby can carry induced
currents that change the antenna's behavior even when there is no direct
electrical connection.

An insulating film helps prevent a short; it does **not** make metal invisible
to radio. Metal can change the directions in which energy travels, the antenna's
tuning, and losses. Plastic and your hand can affect the fields too. Espressif
therefore calls for antenna clearance and final-product RF testing in its
[ESP32-C3 layout guidance](https://docs.espressif.com/projects/esp-hardware-design-guidelines/en/latest/esp32c3/pcb-layout-design.html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).

Conceptual antenna fields interact with nearby metal without contact; a second panel shows an opening, a part, and the clearance remaining between them.

*Left: conceptual fields, not an antenna location map or a keepout dimension.
Right: check the smallest opening against the largest part.*

Do not copy a universal keepout distance from another board or derive it just
from wavelength. Identify the antenna on your exact received board and preserve
space to adjust the mock-up. An unpowered cardboard model can check geometry;
it cannot verify radio performance.

## Nominal size is not guaranteed clearance

A **nominal** dimension is the design target. A **tolerance** states permitted
variation. **Clearance** is the remaining space; negative clearance means the
parts interfere.

Assume an opening is `20.2 ± 0.2 mm` and a module is `20.0 ± 0.15 mm`:

```text
nominal clearance = 20.2 − 20.0 = 0.20 mm
smallest opening = 20.2 − 0.2 = 20.00 mm
largest module = 20.0 + 0.15 = 20.15 mm
worst-case clearance = 20.00 − 20.15 = −0.15 mm
```

The nominal drawing fits, but the allowed extremes do not. For stacked parts,
board thickness, headers, insulation, and lid variation also accumulate: a
**tolerance stack**. Caliper digits alone do not establish part tolerances or
measurement accuracy.

## Why it matters for your prototype

For Day 14, use owned paper/cardboard and measured parts. Include the USB plug,
insertion direction, cable bend, button travel, microphone opening, and part
removal—not just board bodies. Leave room for insulation and supported wires.

Keep the cell represented by an inert dummy and final metal fabrication held.
An open desk prototype is useful without a finished pocket case. No additional
parts or RF instrument purchase is required to learn these distinctions.

## Predict before reading

If the board cannot touch a metal lid because tape separates them, can you
conclude that Wi-Fi will behave as it did on the open bench?

<details>
<summary>Answer</summary>

No. Electrical isolation prevents direct contact, not field coupling. The lid
can still change radio behavior. RF confidence requires controlled, repeated
tests of the relevant geometry, not just an insulation check.

</details>

Go deeper: [Lesson 11 — antennas and nearby metal](../../edu/fundamentals/11-rf-emc-antennas-and-metal-frame.md) and [Lesson 12 — tolerances](../../edu/fundamentals/12-soldering-mechanics-insulation-tolerance.md#dimensions-are-distributions-not-perfect-numbers).

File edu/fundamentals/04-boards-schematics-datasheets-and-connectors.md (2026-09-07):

# 04 — Boards, schematics, datasheets, and connectors

## Learning objectives

After this lesson, you should be able to:

- distinguish an IC, package, module, development board, and assembled product;
- follow nodes and net labels on a schematic without confusing it with physical
  layout;
- distinguish a schematic symbol from a PCB footprint and a 3D envelope;
- find operating limits, pin definitions, timing, and mechanical data in a
  datasheet;
- identify the evidence gap between a chip datasheet and a marketplace module;
- specify a connector by family, pitch, positions, contacts, and mating part;
- explain why firmware, schematic, BOM, PCB/CAD, and the received hardware must
  describe one configuration; and
- create an unpowered evidence record for an unfamiliar board.

## Five levels that beginners often call “the chip”

These are different objects:
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

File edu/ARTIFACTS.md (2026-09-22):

# Published learning pages (Claude artifacts)

Educational material for this project is published as illustrated web pages
alongside the Markdown here. Each page is built from a repository file, which
stays the authority; the page adds diagrams of the mechanisms. If a page and
the repository disagree, the repository wins.

The links are private to the builder's Claude account until shared from each
page's Share menu.
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

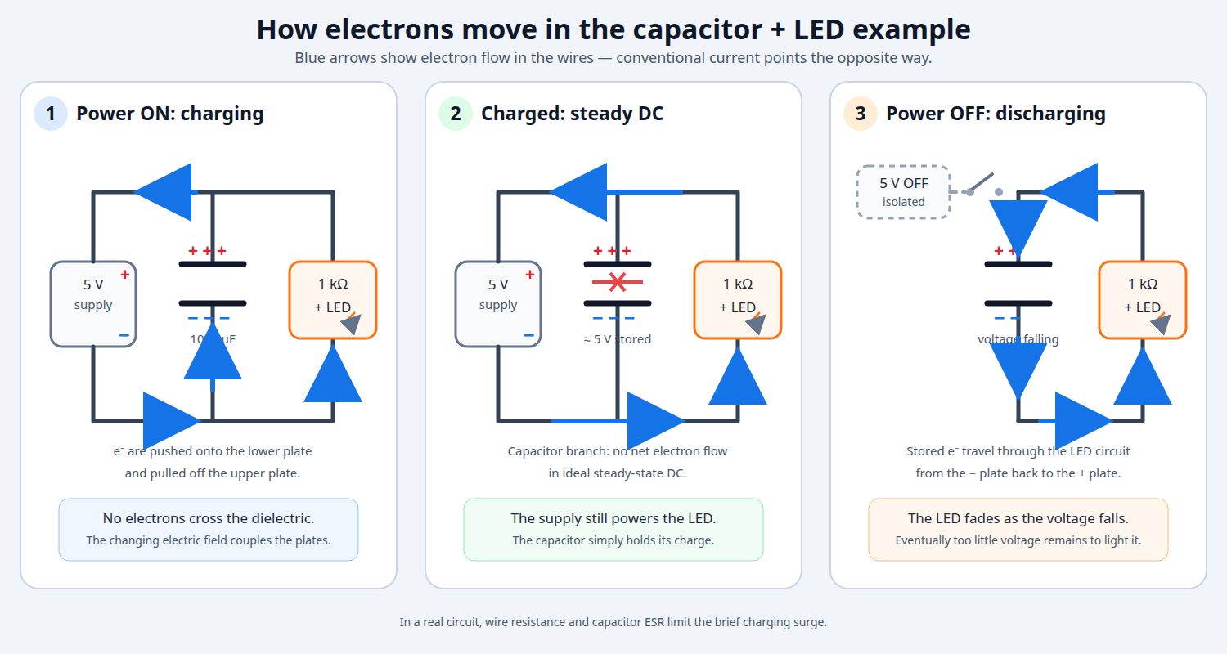
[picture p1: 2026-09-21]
edu/fundamentals/assets/capacitor-electron-flow.png

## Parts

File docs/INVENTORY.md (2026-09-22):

# Purchased inventory — what is in hand and what each item is for

> **Factual purchase record, last updated 2026-09-21.** This tracks what was
> *bought*, not what is *approved*. It takes no side in the R1/F0 design fork —
> part-selection authority stays in
> [FINAL_MATERIALS_FOR_REVIEW.md](FINAL_MATERIALS_FOR_REVIEW.md). Mark items off
> as boxes arrive and incoming inspection passes.

**Status: the recorded orders provide a starting set for the USB prototype.**
Check what has actually arrived before each session. This inventory does not
establish a complete battery-powered design. Start with the
[action-only fast track](../plan/FAST_TRACK.md), using what is already owned;
software setup needs no new purchase, while the first physical boot needs any
proven USB data cable.

## Orders placed

| Order | Date | Contents |
| --- | --- | --- |
| X-Tronic | earlier | Soldering station — $64.80 |
| Adafruit | Sep 1 | Cells, charger, flux pen — $81.29 incl. shipping + tax |
| Amazon #4 | Sep 1 | Bench supply, saw, solder, stripper, brass flux, jumpers, headers |
| Amazon #5 | Sep 1 | Multimeter, calipers, breadboards, safety glasses, pliers |
| Amazon #1 | Sep 2 | Core electronics, passives, insulation, switch, buttons, JST |
| Amazon #2 | Sep 2 | OLED, electrolytic caps |
| Amazon #3 | Sep 2 | K&S 1 mm brass rod |
| DigiKey | Sep 2 | `CES-20134-088PM` speaker |
| Amazon #6 | Sep 2 | K&S #9831 brass tube, TUOFENG 26 AWG wire |
| Amazon #7 | Sep 2 | CBAZY 30 AWG wire (re-ordered after cancellation) |
| Amazon #8 | Sep 2 | Heat gun $10.33 · hot glue gun $11.92 · diamond needle files |
| Amazon #9 | Sep 21 | Rigol DHO802 oscilloscope, [B0CKX699F5](https://www.amazon.com/dp/B0CKX699F5); price paid not recorded |
| Amazon #10 | Sep 21 | BAISDY 45-piece wet/dry sandpaper, 400–3000 grit ([B07D2YYC11](https://www.amazon.com/dp/B07D2YYC11)) · JoTownCand solder wick 3-pack ([B0DRN688Q5](https://www.amazon.com/dp/B0DRN688Q5)) · Epic Medical Supply 91% isopropyl alcohol, 2 × 16 oz ([B0BSJ93RKB](https://www.amazon.com/dp/B0BSJ93RKB)); prices not recorded |
| DigiKey | Sep 21 | 5 × Same Sky `CES-20134-088PM` speaker, 2223-CES-20134-088PM-ND, $4.10 each — $20.50 |
| Amazon #12 | Sep 21 | Rust-Oleum Stops Rust spray paint, 12 oz: `7789830` gloss canvas white ([B000PIG3AS](https://www.amazon.com/dp/B000PIG3AS)) and `7791830` satin white ([B000Z8FGII](https://www.amazon.com/dp/B000Z8FGII)); prices not recorded |

Estimated total spend: **≈ $635–660**, plus the DHO802 (Rigol list price $329; the price paid is not recorded here), $20.50 for five more speakers, and the 21 September Amazon consumables (prices not recorded).

---

# 1 · Electronics

| Item | Qty | What it is and why it is here |
| --- | ---: | --- |
| **Meshnology ESP32-C3 SuperMini** dev board | 10 | The brain. A postage-stamp ESP32-C3 board with Wi-Fi, native USB-C, and the GPIO layout the firmware targets. It runs the assistant, talks to the cloud backend, and drives every peripheral. **Gate each board with `esptool flash_id` — reject anything under 4 MB flash**, and reject any "Plus" variant with an RGB LED on GPIO8, which breaks this pin map. ⚠️ **2026-09-21: the received boards carry a ceramic chip antenna and hit the SuperMini's documented Wi-Fi range problem.** The red rectangular block at the end opposite USB is the antenna; there is no U.FL socket and no PCB trace antenna on these. The SuperMini design is widely reported to leave too little clearance around that antenna and to place it too close to other components, so the board interferes with itself — see [Elektor's antenna mod](https://www.elektormagazine.com/articles/boosting-wifi-range-of-the-esp32c3-supermini-antenna-mod). Symptom here: Step 10 provisioning logged `WifiConfigurationAp: Access Point started` and the OLED showed the config screen, but no phone or laptop could see the SSID at any distance — on three separate boards from this pack (A1 in the breadboard, and two spares bare on an open desk), so it is the batch, not one unit or the wiring. Keep the antenna end clear of jumper wires, modules and metal; a 31 mm quarter-wave wire mod recovers 6-10 dB if clearance alone is not enough. **What worked on A1 (2026-09-21, builder-reported, not instrument-verified):** capping Wi-Fi transmit power at 8.5 dBm (`esp_wifi_set_max_tx_power(34)`, quarter-dBm units) made the hotspot visible, A1 was provisioned onto Wi-Fi, and one spoken question returned a remote response (PASS 10C, same day); the source build now applies that cap after every radio start, so try the current assistant build before any wire mod. Ten boards means you can afford to throw out bad clones. **VBUS-01, 2026-09-22 (builder-measured on A1, diode mode):** A1's `5V` pin is wired directly to the USB-C VBUS, with no diode: 0.001 V with red on VBUS and 0.002 V with the probes swapped, beeping both ways. This matches the published SuperMini schematic ([sigmdel.ca](https://sigmdel.ca/michel/ha/esp8266/super_mini_esp32c3_en.html)), which shows VBUS tied straight to the `5V` header pin. Anything connected to `5V` is therefore connected to the computer's USB port. |
| **Hosyond SSD1306 OLED**, 0.96" 128×64 I²C, white | 5 | The screen — the device's only visual output, showing state, the pairing code, and responses. White pixels on black glass are also the intended white/silver accent. Firmware probes both `0x3C` and `0x3D`, so either address works. **Read the silkscreen pin order before wiring**: vendors ship GND-VCC-SCL-SDA *and* VCC-GND-SCL-SDA on identical-looking boards. |
| **AITRIP INMP441** I²S MEMS microphone | 5 | The ears. A digital microphone that outputs I²S directly, so no analog audio wiring is needed. This is the creator's exact part. Tie `L/R` to GND to select the left slot; data goes to GPIO4. **Keep flux, IPA, glue, paint, and compressed air away from the acoustic port** — contaminating it is permanent. |
| **HiLetgo MAX98357** I²S class-D amplifier | 3 | Converts I²S to speaker output. Used in fast-track Step 11, powered only from the controller's `5V` pin; keep it disconnected before Step 11. Its supply range alone does not define a complete power circuit. Later inspect the exact carrier's gain and `SD/MODE` network: shutdown can be intentional, and mono-mix can attenuate left-only source audio. Do not change the mode or power it from a raw cell based on this inventory. |
| **Same Sky CES-20134-088PM** speaker, 8 Ω 0.8 W | 6 | The mouth. A factory-enclosed micro-speaker — the sealed rear cavity is what makes it audible at this size, and it removes the hardest acoustic problem in the build. 20 × 13 × 4.87 mm, top-firing, with two mounting flanges and a built-in dust mesh. Ships with 60 mm of 32 AWG lead, longer than the whole device, so **it needs no wire from you**. Cap output at ≤ 2.53 V RMS differential to respect the 0.8 W rating. One bought 2026-09-02; five more bought 2026-09-21 from DigiKey at $4.10 each, so no single unit is irreplaceable. Still never cut the leads of a unit you intend to use. |
| **QTEATAK tactile push buttons** | 420 | The only user control: a momentary button on GPIO10 to ground. Short press toggles chat, long press resets Wi-Fi. Pick a white cap to match the finish. Note the onboard GPIO9 button is ROM BOOT, not this input. |
| **2.54 mm male breakaway header pins** | 22 | Snap-apart pin strips for soldering onto modules so they can plug into a breadboard. Makes the whole Phase 0 bench stack reversible instead of permanent. |

# 2 · Power

| Item | Qty | What it is and why it is here |
| --- | ---: | --- |
| **Adafruit #1578** LiPo 3.7 V **500 mAh**, protected | 2 | Previously purchased compact battery candidate, nominally 29 × 36 × 4.75 mm. Keep disconnected and terminal-protected. The current material review records a 0.5 A maximum continuous-discharge rating and rejects it for the former estimated load; ownership is not permission to use it. Never solder to or alter its factory lead. |
| **Adafruit #258** LiPo 3.7 V **1200 mAh**, protected | 2 | The margin battery option, 34 × 62 × 5 mm. Roughly 1.2 A capable and more than twice the runtime, but 62 mm long — longer than the intended device — so fitting it changes the silhouette. Buying both sizes turns the capacity-vs-size argument into a measurement. |
| **Adafruit #4410** USB-C Micro-Lipo charger | 1 | Purchased LiPo charger, with a default 100 mA setting and no load sharing. Store separately from the USB prototype. A future charging arrangement needs its own wiring procedure; the slide-switch OFF position alone is not evidence of source isolation. Leave the charge-rate jumper unchanged. |
| **Chanzon SPDT mini slide switch** | 25 | Purchased switch samples. Useful for unpowered continuity exercises; not selected to carry the final device's battery current. The beginner prototype turns off by unplugging its USB cable. |
| **daier JST-PH 2.0 mm** 2-pin connector cables | 20 pr | Mating connectors for the battery. Their real value is bench testing: they let the current-limited power supply stand in where the battery goes, so the whole power chain is proven before a cell is ever connected. ⚠️ **Verify polarity with the meter, not wire color** — generic JST-PH leads are frequently wired opposite to Adafruit's convention. |
| **LuminologyPro resistor kit**, 25 values, 1/4 W | 1000 | Pull-up and pull-down resistors. 10 kΩ holds the I²S bit clock line GPIO2 (a boot-strap pin) at a defined level; 100 kΩ pulls down the microphone data line GPIO4. The action button needs no external resistor: it goes from GPIO10 to GND and the firmware enables the chip's internal pull-up (as wired and passed in fast-track Step 6). Without these the board can boot unpredictably. |
| **BOJACK ceramic capacitor kit** | 650 | Local decoupling — small capacitors placed at each module's power pins that supply the instantaneous current spikes digital chips demand, which long wires cannot deliver fast enough. 100 nF and 10 µF are the values used here. |
| **ALLECIN electrolytic capacitor kit**, 24 values | 1 kit | Bulk energy storage. The 220 µF sits at the amplifier's power input as a reservoir for bass notes and Wi-Fi transmit bursts, which would otherwise drag the shared battery rail down and reset the processor. |

Both cell sizes remain stored and terminal-protected. Portable battery power is
out of scope for this prototype by the builder's decision of 2026-09-21. Battery selection is later work and depends on a complete power
design and measured demand.

# 3 · Frame, insulation, and wire

| Item | What it is and why it is here |
| --- | --- |
| **K&S #9831 brass tube**, 1.5 mm OD × 0.225 mm wall × 300 mm, 4 tubes | The frame itself — the exposed brass cage that gives the device its look and holds everything together. The reference build's exact stock. The wall is only 0.225 mm, so it must be cut with the jeweler's saw; flush cutters crush it. ASIN verified to resolve to 9831 and not a wrong-diameter variant. |
| **K&S 1.0 mm round brass rod**, 5 rods | Corner posts and cross braces. Solid rod, so it is stiffer than the tube and telescopes inside it (tube ID ≈ 1.05 mm) for clean joints. |
| **XFJYMXDM fish paper**, 16.4 ft | Flame-rated electrical insulation board that lines the battery bay. This is the mandatory barrier between the lithium cell and everything else — the one insulation layer that is a safety requirement rather than good practice. |
| **ELEGOO polyimide (Kapton) tape**, 4-pack | High-temperature insulating tape for module backs and anywhere a wire crosses brass. Survives soldering heat without melting, unlike vinyl electrical tape. |
| **Pointool heat-shrink tubing kit**, 14 sizes, **white** | Tubing that shrinks tightly around a solder joint when heated, insulating it and adding a little strain relief. White matches the intended finish. |
| **TUOFENG 26 AWG silicone wire**, 6 colors, 33 ft each | The power wiring — battery bus and any load-carrying run. Thicker than the signal wire for mechanical robustness at the connection you least want to fail. Silicone insulation stays flexible and resists soldering-iron burns. |
| **CBAZY 30 AWG silicone wire**, 6 colors, 32.8 ft each | The signal wiring — I²C to the display, I²S to the microphone and amplifier, and the button. Thin and flexible so 15+ conductors can be routed inside a 45 mm cage without levering on fragile breakout pads. |

### Wire-gauge note — current is not the deciding factor

The "26 AWG for power" rule came from the withdrawn R0 design, which pushed
~1.15 A through a long chain. The current frame is ~45 mm and the chain is
three parts, so on **current** either gauge is comfortable:

| | 30 AWG | 26 AWG |
| --- | ---: | ---: |
| Resistance | ~0.34 Ω/m | ~0.13 Ω/m |
| Loop drop @ 0.8 A peak, 160 mm | 43 mV | 17 mV |
| Loop drop @ 150 mA average | 8 mV | 3 mV |

Both are far inside the ≤300 mV upstream-drop screen. The real trade is
**mechanical**: 26 AWG resists nicking and fatigue on the battery bus, while
30 AWG routes without stressing pads on the signal side. Both are on hand —
use each where it belongs, and strain-relieve every conductor either way.

# 4 · Tools — soldering

| Item | What it is and why it is here |
| --- | --- |
| **JoTownCand solder wick**, 3-pack, 3 widths, bought 2026-09-21 | Braided copper that lifts solder off a joint: the way to clear a bridge or remove header pins. Use the narrowest width on OLED, microphone and amplifier pads, with a touch of flux, and cut off the used end each time. |
| **Epic Medical Supply 91% isopropyl alcohol**, 2 × 16 oz, bought 2026-09-21 | Cleans flux residue off boards and rinses the brass after acid flux. 91% has little enough water to evaporate cleanly; keep it away from the microphone's acoustic port and away from flame or a hot iron. |
| **X-Tronic 3020-XTS station** + 5 tips, solder roll, solder sucker, tweezers, 2 helping hands, silicone mat | Temperature-controlled soldering iron and the bench kit around it. Temperature control matters because a MEMS microphone and an OLED flex tail are heat-sensitive. The helping hands hold parts while both of yours are busy; the silicone mat is the only heat-safe work surface you own. |
| **MAIYUM 63/37 rosin-core solder**, 0.8 mm, 100 g | Electronics solder. The 63/37 tin-lead alloy melts lower and wets faster than lead-free, meaning less time with a hot iron pressed against fragile parts. Wash hands, do not eat at the bench, ventilate. |
| **Chip Quik CQ4LF no-clean flux pen**, 10 ml | Flux chemically strips oxide off metal so solder actually bonds instead of balling up. "No-clean" residue is safe to leave on electronics. ⚠️ Duplicate — one was already owned. |
| **Harris SCLF4 Stay-Clean flux**, 4 oz | A far more aggressive **acid** (zinc-chloride) flux, needed because brass oxidizes too fast for rosin flux to handle. **Empty brass frame only — never near electronics.** It is corrosive and must be washed off and neutralized with baking soda, or it will eat the joints and blister any paint later. |

# 5 · Tools — measurement

| Item | What it is and why it is here |
| --- | --- |
| **KAIWEETS TRMS multimeter**, 6000 counts, + hard case | The most important instrument in the build. Every safety step is a meter step: battery polarity before the first connection, checking the brass frame is isolated from every circuit, continuity, switch voltage drop, charge termination voltage. Nothing electrical gets connected without it. |
| **SKY TOPPOWER DC supply**, 0–30 V / 0–5 A | An adjustable, **current-limited** bench power supply that substitutes for the battery during testing. If something is wired wrong it politely limits current instead of dumping a lithium cell's full energy into the fault. This is what lets the entire power chain be proven before a cell is ever installed. |
| **Rigol DHO802 oscilloscope**, 70 MHz, 2 channels + external trigger, 12-bit, two PVP3150 10X probes, bought 2026-09-21, **not yet received** | Shows voltage against time, which the multimeter cannot: clock edges, rail dips during Wi-Fi bursts, power-up order, and the speaker's differential signal. Two channels with both probe grounds on circuit ground plus its A−B math give the differential-safe speaker measurement the audio gate asks for; **never clip a probe ground to either speaker lead**. Its Single trigger mode catches one-off start-up events. Powered from a USB-C 15 V adapter; before first use, meter whether the BNC shells connect to the adapter's earth and to the rear GND terminal, and record the answer. Warranty three years on the mainframe, not the probes. It does not measure millisecond current peaks or log a charge cycle. |
| **NEIKO digital caliper**, 0–6" | Measures parts to a hundredth of a millimetre. Every module, board, and connector needs its real measured size before the frame geometry can be trusted — listing dimensions are frequently wrong. |
| **REXQualis breadboards**, 4 pcs (830 + 400 point) | Use for resistor labs and the controller's button/OLED/microphone connections. Check split power rails and header joints before use. Amplifier supply and speaker current do not go through breadboard contacts. Loose module headers must be soldered and inspected before jumper testing. |
| **TODOELEC Dupont jumper kit**, 120 wires, 10 cm | Pre-terminated jumper wires for breadboarding. Bench use only — not for final assembly, and never for the speaker output or high-current runs. |

**Instrument decision, 2026-09-21:** the DHO802 is the last instrument purchase. The purchase authority's remaining `ARRANGE` instruments — the fast current meter, the calibrated charge-voltage logger, and the three-channel temperature logger — are to be borrowed or rented if needed. Until access exists, the gates that name them stay closed.

# 6 · Tools — fabrication and safety

| Item | What it is and why it is here |
| --- | --- |
| **SE 3-in-1 jeweler's saw** + 144 blades + V-slot bench pin with clamp | The only correct way to cut 0.225 mm-wall brass tube — a fine-toothed blade removes material without crushing the tube. The bench pin clamps to the table and supports small work while you cut. |
| **WORKPRO jewelry pliers**, 3-pack | Round-nose and chain-nose pliers for bending brass into the frame's rectangles and forming braces. Round jaws make smooth curves without kinking the tube. |
| **Hakko CHP CSP-30-1 wire stripper**, 30–20 AWG | Removes insulation without nicking the conductor. Sized correctly for both wire gauges here; a blade or generic stripper nicks fine strands, which then break later inside a sealed frame. |
| **QWORK mini heat gun**, 300 W, with stand | Shrinks the heat-shrink tubing. Directed hot air is controllable in a way a lighter is not — no soot, no scorching adjacent insulation. |
| **SHJADE hot glue gun**, 20 W mini, + 30 sticks, white | Low-temperature adhesive for retaining modules in the frame — the reference build's own method. Low-temp matters near plastic module bodies and the OLED. Keep glue away from the microphone port, the switch mechanism, and connectors. |
| **SE 10-piece diamond needle file set**, 150 grit, 744DF-R | Small shaped files for deburring cut tube ends and fine shaping. ⚠️ **See the note below — diamond is not ideal for brass.** |
| **BAISDY wet/dry sandpaper**, 45 sheets, 400–3000 grit, bought 2026-09-21 | Deburrs every cut brass edge so none can cut a wire or a hand; 400–800 does the deburring, the finer grits polish or key a surface before paint. Sand brass wet or with a mask, well away from the electronics. |
| **3M Solus 1000 safety glasses**, clear | Eye protection for sawing, filing, and clipping wire, all of which throw metal fragments. Wear them; the saw is the sharpest thing on the bench. |

### ⚠️ Note on the diamond file set

Diamond files cut by holding abrasive grit in a metal surface. Soft metals —
brass, copper, aluminium — pack into the gaps between the grit and the file
stops biting. They are excellent on glass, stone, and hardened steel, and they
will do light deburring on brass, but they will load up and dull with repeated
use.

This is not a problem to fix urgently:

- **Clean them** with a stiff brass brush when they load up, and they keep working.
- **Sandpaper does most of this job anyway.** Deburring a thin tube end is
  mostly a few strokes of 400–800 grit wet/dry, now in hand (bought 2026-09-21).
- **If filing gets frustrating**, a steel needle file set in cut 2 is about
  $10 and is the correct tool for brass.

Keep the diamond set — it earns its place on the harder materials.

---

## Still needed

A working data cable was proven at fast-track Step 3, and the 21 September
order covered the wick, sandpaper and alcohol, so nothing below blocks the
build. What remains is small and local.

| Item | Why | Approx. |
| --- | --- | ---: |
| **Swabs · baking soda** — buy **locally** (pharmacy + grocery) | Needed only if the frame is soldered with the Harris acid flux: baking soda neutralizes it and the owned 91% IPA rinses it off. Residue left on brass corrodes joints and blisters paint | ~$5 |
| Gel cyanoacrylate (super glue) — optional | Spot-bonding where hot glue is too bulky; keep it and its fumes away from the microphone port and the OLED glass | ~$5 |
| USB-A-to-C data cable, spare — optional | One proven cable is enough; a spare helps once one stays plugged into the finished device | ~$10 |

### Optional — white/silver finish

White system. **Bought 2026-09-21:** both topcoats, Rust-Oleum `7789830` gloss
canvas white, a warm off-white, and `7791830` satin white. **Not bought:** the
`7780830` white primer. The Rust-Oleum 249322 dark-green self-etching primer
was ordered and then canceled the same day.

1. Sand the bare brass with the owned 400–600 wet/dry and wipe it with the owned
   91% IPA, so the paint has a clean, keyed surface.
2. Rust-Oleum `7780830` Stops Rust Clean Metal Primer, flat white
   ([B000Z8C3PM](https://www.amazon.com/dp/B000Z8C3PM)).
3. One topcoat, chosen on the test coupons: Rust-Oleum `7791830` satin white
   ([B000Z8FGII](https://www.amazon.com/dp/B000Z8FGII)) or `7789830` gloss
   canvas white ([B000PIG3AS](https://www.amazon.com/dp/B000PIG3AS)). Use one
   sheen on the whole frame.

Without an etching primer, adhesion on smooth non-ferrous brass is the open
question, so the finish stays gated: spray test coupons cut from brass offcuts
first and check that the paint does not lift, and paint the frame only after
the fit and Wi-Fi checks pass. If the coupons peel, an etching primer returns
under the white coats. NYC Admin Code §10-117 keeps spray paint 21+ and locked.
Spray the empty frame outdoors or with strong ventilation, never with
electronics installed, and store cans away from the soldering iron and heat
gun. White styrene sheet for guards (~$10, Blick or Canal Plastics) remains
optional.

---

## What to do first

Follow the [action-only fast track](../plan/FAST_TRACK.md): identify and flash
one bare controller, prepare reliable headers, add the button and OLED, then
observe microphone levels in the offline diagnostic firmware. This uses the
controller's USB supply and needs no cloud account, amplifier, battery, or
enclosure. Save a wiring photograph and the serial output at each step. The
[USB prototype quickstart](PROTOTYPE_QUICKSTART.md) remains the compact
technical reference.

After those local tests pass, the regular source firmware provides the next
software/backend experiment. Speaker output and portable power remain separate
integration tasks; buying the parts did not verify them.

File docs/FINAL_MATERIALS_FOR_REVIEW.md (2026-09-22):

# Final Phase 0 qualification materials list — for Claude review (F0)

> **Procurement authority for a reversible Phase 0 qualification build only.**
> Checked 2026-09-02. This document replaces the earlier complete-cart claim.
> It is safe to order the items marked `BUY-P0`, but it does **not** release a
> battery-powered pocket device, final quantities, or brass cutting. Claude's
> compact R1 proposal is preserved separately in
> [CLAUDE_R1_BUILD_PROPOSAL.md](CLAUDE_R1_BUILD_PROPOSAL.md).

This is the **finalized order list for Phase 0**, not a final-build BOM. A
truthful final-build BOM cannot exist until measurements choose the cell,
USB-source isolation, fuse, speaker/cavity, guard, and real enclosure geometry.
Claude should review and correct this list before checkout; passing that review
still authorizes only the `BUY-P0` quantities below.

The honest verdict is **GO for one reversible bench/fit batch; NO-GO for final
assembly or pocket carry**. The firmware pin/rate contract is credible, but no
physical board, battery chain, speaker, or frame has been tested in this
workspace. The former 500 mAh/direct-rail proposal also failed a datasheet
audit: its 0.5 A maximum continuous-discharge rating was below that design's
estimated 0.7–0.8 A coincident load. The new 5 V whole-load candidate must be
recalculated because its low-cell input current can be higher still.

## Scope decision 2026-09-21: a USB-powered home device

The builder decided that this prototype stays on USB power. It lives at home
or moves between Wi-Fi networks; portable battery power is out of scope. The
rest of this document was written for a battery-powered pocket device and is
kept, unchanged, for a possible future portable revision. For this prototype:

- **Audio uses the USB-powered stage in fast-track Step 11.** The amplifier's
  `VIN` comes from the controller's `5V` pin, the same USB supply as everything
  else, so there is no powered-controller, unpowered-amplifier state. GPIO5
  drives `SD_MODE` directly with a pull-down. It uses the owned HiLetgo
  amplifier, the owned CES-20134-088PM speaker, kit passives, and a dummy load
  built from kit resistors. Gate 7's measured output limit is met by Step 11's
  PASS 11B instead of Fixture B.
- **Not needed for this prototype:** Fixture A and Fixture B, the future
  cell-discharge fixture, and gates 5, 6, 8 and 9. Gate 4's TXU sequencing
  clause no longer applies; its clock check remains.
- **Do not buy for this prototype:** Adafruit #3006, the TI TXU-EVM, Pololu
  #2873 and #2810, the Molex harness, the fuse samples, the Panasonic
  capacitors, the Yageo 1% resistors and SQP10 dummy loads, the Adafruit #1131
  adapters and #501 charger supply, cell samples, Formex barrier, polycarbonate
  guard, and the calibrated charge and current loggers. The CMS-20143-158SP
  speaker stays an optional acoustic upgrade.
- **Still in force:** gates 1 to 3, and gates 10 and 11 for any enclosure,
  because a USB-powered frame still needs measured fit, the antenna keep-out,
  and a tested finish.
- **Stored, not used:** the owned cells and the #4410 charger stay
  terminal-protected in storage.
- **Measured 2026-09-22:** A1's SuperMini `5V` pin is the USB-C VBUS node
  directly, with no diode (builder, diode mode, both directions), matching the
  published SuperMini schematic. Step 11's
  amplifier therefore sees the full USB voltage, and no other source may ever
  be connected to `5V` while USB is in. For any future battery revision this
  confirms the controller-interface finding above: the diode-only scheme stays
  `REJECT`.

## How to read the list

| Mark | Meaning |
| --- | --- |
| `OWNED` | Already purchased; do not buy again unless the incoming check fails. |
| `BUY-P0` | Buy now in the stated quantity for breadboard, measurement, and physical-fit qualification. |
| `ARRANGE` | Borrow, rent, obtain a sample, or confirm access before testing. |
| `HOLD` | Candidate only; do not buy final quantity or install until its named gate passes. |
| `REJECT` | Do not use in this revision. |

Confidence is the chance that the exact choice will survive Phase 0 unchanged,
not a claim that an untested assembly is safe: **high 85–100%**, **medium
60–84%**, **low below 60%**. Prices and stock are intentionally not frozen;
seller inventory changes faster than the engineering decision. Recheck the
exact manufacturer part number in the cart.

In this document, an **unresolved device choice** is one that is marked `HOLD`,
has confidence below 85%, or carries a supplier/lifecycle risk that could force
a redesign. Each such role has a preferred candidate plus two viable design
alternatives in the alternatives matrix. Workshop consumables and instruments
are capability requirements rather than parts of the device; where no exact
MPN is named, arrange access or select a reputable equivalent meeting the whole
specification rather than treating an example as frozen.

## Implemented functional contract and proposed control extension

The source-build target remains the plain ESP32-C3 layout already implemented
in `firmware/src/boards/pocket-wall-e-c3`:

| Function | Signal | Source-build GPIO / setting |
| --- | --- | ---: |
| OLED | SDA / SCL | 21 / 20 |
| Shared I2S | WS / BCLK | 1 / 2 |
| Amplifier | DIN | 3 |
| Microphone | data out | 4 |
| Amplifier | candidate hardware enable | 5; firmware sequencing implemented but disabled in supported prototype builds; physical interface/timing still unqualified |
| Action switch | active-low input | 10 |
| OLED | controller/address | SSD1306, 128×64, 0x3C or 0x3D |
| Audio | sample rate / frame | 16 kHz, two 32-bit slots, 1.024 MHz BCLK |

The opaque creator image is a separate wiring path and keeps microphone data
on GPIO8. Never combine the two maps. Microphone modules with different names
have analogous I2S signals, not guaranteed identical physical pin order.

## Candidate power architecture

These are **mutually exclusive fixtures** to draw and review in KiCad. Phase 0
discharge qualification is literally battery-free; the only cell-connected
Phase 0 activity is the later staged OCV/standalone-charge gate.

```text
FIXTURE A — standalone charging only, no load branch:
  #258 factory JST-PH ── reviewed, polarity-keyed #1131-derived measurement adapter
    CELL_POS power branch ── `0251.500MXL` fuse immediately after the connector
      ── calibrated battery-side charge-current logger ── #4410 BAT+
    COMMON_GND power branch ───────────────────────────────── #4410 BAT−
    CELL_POS Kelvin-sense branch ── source-adjacent 1 kΩ ── shrouded SENSE+
    COMMON_GND Kelvin-sense branch ── source-adjacent 1 kΩ ── shrouded SENSE−
  Calibrated endpoint logger connects only across SENSE+ / SENSE−.
  #4410 USB-C ── qualified USB source
  The Molex harness, #2810, #2873, controller, and amp are absent.

FIXTURE B — battery-free discharge/power qualification only:
  current-limited bench supply positive (the sole CELL_POS substitute)
    ── separately guarded candidate-fuse test point at the source
    ── Molex two-pole bench harness ── Pololu #2810 VIN/VOUT
    ── VBAT_SW (sweep 4.2 V through candidate cutoff/restart)
         ── Pololu #2873 VIN; bridge SEL to its adjacent VIN-pulled pad for 5 V
              ── 5V_SYS (whole-load 3.0 V falling cutoff / ~3.4 V restart)
                   ├── Adafruit #3006 amp VIN + 220 µF reservoir
                   │     └── SD/MODE held LOW until rail and I2S are ready
                   └── controller power interface: HOLD; see the paragraph after this diagram
                        ── received-board LDO ── 3V3
                             ├── OLED
                             ├── I2S microphone
                             └── TI TXU-EVM TXU0104 VCCA

  bench supply return ── the other Molex conductor ── COMMON_GND

MCU WS/BCLK/DIN ── TXU0104 A1…A3; GPIO5 ── A4, with 4.7 kΩ to GND
TXU0104 B1…B4 ── amp LRC/BCLK/DIN/SD_MODE; VCCB = 5V_SYS
#2873 PG ── TXU0104 OE; OE has 10 kΩ to 5V_SYS; SD_MODE has 4.7 kΩ to GND

FUTURE CELL-DISCHARGE FIXTURE — HOLD, not Phase 0 wiring authority:
  #258 factory JST-PH ── polarity-mapped mating adapter
    ── selected fuse immediately after the source connector
    ── two-pole disconnect ── #2810 ── #2873 and loads
  The only unavoidable pre-fuse wire is the guarded factory battery lead.
  #4410 and its PCB traces are never used as a load pass-through.

Speaker: amplifier OUT+ and OUT− only; neither lead goes to GND or frame.
Brass frame: mechanically structural and electrically floating.
```

Why the extra power parts exist:

- `#4410` performs the Li-ion CC/CV charge algorithm; protection inside a pack
  is not a charger.
- `#2810` lets a tiny slide actuator control the load without forcing the
  ampere-class cell current through a generic 0.5 A mechanical contact. It is a user
  power control, **not** the positive-disconnect charging interlock.
- `#2873` gives the whole active load a regulated 5 V rail and a hysteretic
  3.0 V cutoff. The amplifier must remain in hardware shutdown during the
  regulator's 700 mA-limited startup and until I2S is valid; otherwise this
  topology is rejected. Brownout/reboot cycling and the pack PCM are not the
  normal empty-battery policy.
- The controller power/service interface remains `HOLD`. If continuity shows
  that the SuperMini `5V` pin is the USB-C receptacle's VBUS node, the former
  diode-only scheme is categorically `REJECT`: feeding `5V` would source power
  outward on the receptacle, regardless of diode orientation. The final path
  then requires reviewed board-trace separation plus true reverse blocking, a
  different controller, or a positive interlock that opens 5V_SYS before USB
  can mate. A `1N5820` also cannot prove the former ≤10 µA criterion: onsemi
  specifies reverse-current maxima in milliamps at rated reverse voltage.
- The populated `TXU0104` section of TI's `TXU-EVM` is the Phase 0 experiment
  across the powered-MCU/unpowered-amplifier boundary. Unlike the rejected
  auto-direction TXB0104 network, it is a one-way A-to-B translator with
  partial-power-down, supply isolation, output disable, and strong outputs that
  may drive the required `SD_MODE` pull-down. The #2873 `PG` signal supplies a
  hardware rail-good veto at `OE`; GPIO5 then controls channel 4 and amplifier
  shutdown independently. Its 1.024 MHz waveform, sequencing, and all
  partial-power states still need measurement.
- The fuse is branch/wire fault containment. Its final value remains `HOLD`
  until the current waveform and nuisance-opening margin are measured.

In Fixture A, “source-adjacent” means the positive power fuse and both sense
resistors are the first components after the mating battery connector, on a
rigid guarded adapter with no accessible raw-cell copper. Never attach ordinary
meter clips to the cell side. The two 1 kΩ sense resistors limit a single-lead
short to about 4.3 mA at the maximum accepted voltage; their loading/divider
error, tolerance, temperature coefficient, lead leakage, and logger input
impedance must all be included in the ≤5 mV uncertainty budget. Stage-1 OCV is
measured at the downstream, source-fused power output with #4410 absent.

Do not size the cell from the former 0.8 A estimate. At minimum cell voltage,
the new planning calculation is `(amplifier input power + controller/peripheral
input power) / (#2873 efficiency × cell voltage)`, followed by transient and
temperature margin. A 1.5 W speaker workload can make that result exceed
1.2 A; the measured waveform and every exact-part limit decide the answer.

The #4410 has no load sharing. In Phase 0 it may charge the quarantined pack
only on a standalone fixture with the load harness physically disconnected,
attended and outside a pocket. It cannot be promoted into the finished device
on a remembered OFF rule: final charging needs #4755-class power-path hardware
or an electrical/mechanical interlock that physically opens the load before a
charger plug can mate. For SuperMini service USB, disconnect the battery,
charger, external regulators, amplifier, and all separately powered wiring.
Cell removal alone is insufficient: an unpowered converter left on the shared
rail can still be back-powered. A bare controller or the USB-only prototype
with button/OLED/microphone supplied by the controller's own 3.3 V output is
permitted. Unplug USB before rewiring. A later multi-supply assembly needs a
tested service-isolation scheme before its USB connector is used.

All Phase 0 powered work is attended on a nonflammable bench. For the first
amplifier tests, `SD/MODE` is physically tied to GND while the regulator
starts, and TXU B4 is physically disconnected. De-energize the fixture, remove
the hard-ground link, and meter-confirm that it is open before connecting B4;
never let the translator drive a hard short. The proposed next experiment uses the populated TXU0104 section on
TI's `TXU-EVM`: connect VCCA=3V3 and VCCB=5V_SYS; route WS/BCLK/DIN through
A1→B1, A2→B2, and A3→B3; connect the uncommitted GPIO5 to A4 with 4.7 kΩ from
A4 to GND; and route B4 to `SD/MODE` with a separate 4.7 kΩ from B4 to GND.

Meter-map the TXU0104 section's J3 before power. Connect #2873's open-drain
`PG` to J3 center/`OE`, and pull that node up through **10 kΩ to VCCB/5V_SYS**.
The EVM shunt may remain only in the meter-confirmed center-to-VCCB position,
which uses its fitted 10 kΩ path; attach `PG` to the center node with a secure
test connection. If that is mechanically unreliable, remove the shunt and fit
the explicit 10 kΩ resistor. Never short `OE` directly to 5V_SYS. A 3V3
pull-up is not the candidate because USB could then feed an unpowered regulator
`PG` node.
Pololu describes `PG` as low until roughly 95% of nominal output and open-drain
afterward, but does not publish the limits needed to accept this circuit by
inspection. Scope it through cold start, slow ramp, brownout, switch-off, and
USB-only transitions. Scope evidence can qualify the current-limited bench
experiment but cannot establish unpublished absolute-maximum/sink ratings;
obtain written Pololu limits or add a reviewed buffer before a final design.

Firmware must configure GPIO5 output-low at its earliest board-init point and
initialize continuous clocks with zero data. The MCU does **not** sense `PG` in
this candidate: it may raise GPIO5 only after its own startup/rail-stabilization
delay and valid zero-data I2S, while `PG` independently keeps `OE` disabled
until the regulator is good. Keep samples at zero for a scope-qualified delay
that covers worst-case `PG` release plus the amplifier datasheet turn-on time;
if that bound cannot be guaranteed, add a reviewed level-safe `PG` sense path
before promotion. Official ESP32-C3 reset behavior does not itself
enable a GPIO5/MTDI pull-up, but firmware APIs can; never reset that pad into or
configure it with a pull-up. On stop, lower GPIO5 before clocks or power.
Measure `OE` below the TXU0104 guaranteed-low limit whenever `PG` is low.
Measure `SD/MODE` below **0.08 V** including instrument uncertainty while
disabled and above **1.5 V** only after the enable event; these are the
MAX98357A guaranteed comparator boundaries, not the 0.16 V and 1.4 V typical
values. KiCad review, the firmware change, a signal-integrity capture, and
per-line plus total unpowered-I/O injection tests are required before this
experiment can become the final circuit.

## BUY-P0 — exact electronics and power samples
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

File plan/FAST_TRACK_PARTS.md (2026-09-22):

# Fast-track parts outline — every component, by step, with its link

[Back to the action-only fast track](FAST_TRACK.md) ·
[Theory companion](FAST_TRACK_THEORY.md) ·
[Full purchase record](../docs/INVENTORY.md)

This page is the "do not forget anything" checklist. It does not replace the
[fast track](FAST_TRACK.md), which stays the authority on order, wiring, and
safety. Use this page to answer one question only: *what do I need in my hand
before I start this step, and where did it come from?*

Do not go shopping from this page alone. Steps 0–4 need almost nothing, and
buying ahead of a gate is how a bench fills with parts you are not allowed to
connect yet.

## How to read the link column

| Mark | Meaning |
| --- | --- |
| ✅ | Recorded purchase link — this exact listing is in the purchase record |
| 📦 | Owned and recorded, but the exact order URL was not saved. The search link is only for comparing names and packaging with your pile |
| 🔍 | Candidate or search link. **Not** purchase provenance and **not** recorded as bought |
| ⬜ | On the still-needed list in [INVENTORY.md](../docs/INVENTORY.md#still-needed) |

Marketplace sellers and board revisions change. When a link and the label on
the received part disagree, **the label on the part wins.**

## Where you are now

**The USB prototype is complete — PASS 9 established 2026-09-20.** Two cold
starts booted without a reset loop, the button logged every press, the OLED
started and toggled, and speech read higher than quiet. This is the first
physical-hardware result in the project. **Step 10 followed on 2026-09-21:**
`A1` joined Wi-Fi under the 8.5 dBm transmit-power cap and one spoken question
returned a remote response from the Xiaozhi backend (PASS 10C,
builder-reported). No spoken output yet; the amplifier stays disabled.

Build history:

| Module | Headers | Notes |
| --- | --- | --- |
| Controller `A1` | 16 soldered in 5C, passed | Two 8-pin strips |
| OLED | Arrived factory-soldered | Silkscreen order `GND-VCC-SCL-SDA` |
| Microphone | 6 soldered in 5E | Two rows of three: `SD VDD GND` / `SCK WS L/R` (re-read 2026-09-20; an earlier note had the second row reversed) |

The Sullins 1×40 strip is in hand, so header supply is no longer a constraint.
Everything from Step 6 on is breadboard, jumpers, and the serial monitor.

**Step 6 passed 2026-09-20:** rails built and verified, button on GPIO10, ten
presses logged `BUTTON GPIO10: click 1`–`10`. The button's legs do not span
the trench, so it sits on one side with each joined leg pair in its own
column — the guide's Step 6 was corrected to state that requirement.

## Master list — everything the USB prototype touches

| Component | First needed at | Link |
| --- | --- | --- |
| Meshnology ESP32-C3 SuperMini (10-pack, use 1) | Step 0 | ✅ [Amazon B0F888JQ91](https://www.amazon.com/dp/B0F888JQ91) |
| USB-A-to-C **data** cable | Step 0 | ⬜ [Rankie 3-pack B01JRY0VE4](https://www.amazon.com/dp/B01JRY0VE4) — you already proved a working cable at Step 3 |
| KAIWEETS HT118A multimeter | Step 5A | ✅ [Amazon B08BL288LW](https://www.amazon.com/dp/B08BL288LW) |
| Hosyond SSD1306 OLED (5-pack, use 1) | Step 5A | ✅ [Amazon B09T6SJBV5](https://www.amazon.com/dp/B09T6SJBV5) |
| AITRIP INMP441 microphone (5-pack, use 1) | Step 5A | ✅ [Amazon B092HWW4RS](https://www.amazon.com/dp/B092HWW4RS) |
| 2.54 mm male breakaway headers (22 loose pins in hand) | Step 5A | 📦 Amazon order #4, URL not saved |
| Extra 1×40 headers, if you are short | Step 5A | 🔍 [Sullins PRPC040SAAN-RC — DigiKey](https://www.digikey.com/en/products/detail/sullins-connector-solutions/PRPC040SAAN-RC/2775214) |
| 3M Solus 1000 safety glasses | Step 5B | ✅ [Amazon B016KZ1ZPM](https://www.amazon.com/dp/B016KZ1ZPM) |
| X-Tronic 3020-XTS station, tips, mat, helping hands | Step 5B | 📦 [X-Tronic search](https://www.amazon.com/s?k=X-Tronic+3020-XTS) |
| MAIYUM 63/37 solder, 0.8 mm | Step 5B | ✅ [Amazon B076QF1Y85](https://www.amazon.com/dp/B076QF1Y85) |
| Chip Quik CQ4LF no-clean flux pen | Step 5B | 📦 [Chip Quik search](https://www.amazon.com/s?k=Chip+Quik+CQ4LF) |
| BOENFU flush cutters | Step 5C | 📦 [BOENFU search](https://www.amazon.com/s?k=BOENFU+flush+cutters) |
| Practice material (perfboard or offcuts) | Step 5B | 🔍 [2.54 mm perfboard search](https://www.amazon.com/s?k=2.54mm+perfboard+prototype) |
| Solder wick | Step 5B rework | ✅ [JoTownCand B0DRN688Q5](https://www.amazon.com/dp/B0DRN688Q5), bought 2026-09-21 |
| REXQualis breadboards (use the clean 830-point) | Step 6 | 📦 [Breadboard search](https://www.amazon.com/s?k=REXQualis+830+400+breadboard) |
| TODOELEC Dupont jumpers, 120 × 10 cm | Step 6 | 📦 [Jumper search](https://www.amazon.com/s?k=TODOELEC+10cm+Dupont+jumper+120) |
| QTEATAK tactile buttons (420, use 1) | Step 6 | ✅ [Amazon B0FHW6HMG4](https://www.amazon.com/dp/B0FHW6HMG4) |
| LuminologyPro resistor kit (need 10 kΩ + 100 kΩ) | Step 8 | ✅ [Amazon B0F4P352BB](https://www.amazon.com/dp/B0F4P352BB) |
| Phone camera in a clean clear bag | Step 5A | General tool; no project purchase |

## Step by step

### Steps 0–4 — controller, cable, toolchain ✅ done

| Need | Link |
| --- | --- |
| One plain ESP32-C3 SuperMini, flash-ID gated ≥ 4 MB, no RGB LED on GPIO8 | ✅ [B0F888JQ91](https://www.amazon.com/dp/B0F888JQ91) |
| One proven USB-A-to-C **data** cable | ⬜ [B01JRY0VE4](https://www.amazon.com/dp/B01JRY0VE4) |
| A computer with a Bash terminal | — |

### Step 5A — inspect and count ✅ done

| Need | Link |
| --- | --- |
| KAIWEETS meter, continuity mode, self-checked | ✅ [B08BL288LW](https://www.amazon.com/dp/B08BL288LW) |
| One OLED and one microphone, to inspect | ✅ [OLED](https://www.amazon.com/dp/B09T6SJBV5) · ✅ [Mic](https://www.amazon.com/dp/B092HWW4RS) |
| Header pins for every unsoldered position | 📦 22 in hand · 🔍 [Sullins 1×40](https://www.digikey.com/en/products/detail/sullins-connector-solutions/PRPC040SAAN-RC/2775214) if short |

**Pin arithmetic:** controller 16 + OLED 4 + microphone 6 = **26** if every
position is bare. The purchase record confirms only **22 loose pins**. Count
the positions you actually still need before ordering anything.

### Steps 5B–5E — soldering ✅ done

If all 26 positions already passed 5A, skip this whole block and go to Step 6.

| Need | Link |
| --- | --- |
| Safety glasses — required, not optional | ✅ [B016KZ1ZPM](https://www.amazon.com/dp/B016KZ1ZPM) |
| Soldering station, silicone mat, helping hands | 📦 [X-Tronic search](https://www.amazon.com/s?k=X-Tronic+3020-XTS) |
| 63/37 solder, 0.8 mm | ✅ [B076QF1Y85](https://www.amazon.com/dp/B076QF1Y85) |
| Electronics flux pen — **not** the Harris acid brass flux | 📦 [Chip Quik search](https://www.amazon.com/s?k=Chip+Quik+CQ4LF) |
| Flush cutters, to break header strips | 📦 [BOENFU search](https://www.amazon.com/s?k=BOENFU+flush+cutters) |
| Practice material for the three warm-up joints (5B) | 🔍 [Perfboard search](https://www.amazon.com/s?k=2.54mm+perfboard+prototype) |
| Solder wick, for removing excess solder | ✅ [B0DRN688Q5](https://www.amazon.com/dp/B0DRN688Q5), bought 2026-09-21 |
| Ventilation that moves fumes away from your face | — |

Without wick you have no recovery path for a solder bridge: the fast track
tells you to stop rather than improvise. Decide before you heat the iron.

### Step 6 — button ✅ done

| Need | Link |
| --- | --- |
| The clean 830-point breadboard — not the 400-point jig | 📦 [Breadboard search](https://www.amazon.com/s?k=REXQualis+830+400+breadboard) |
| Four male-to-male jumpers | 📦 [Jumper search](https://www.amazon.com/s?k=TODOELEC+10cm+Dupont+jumper+120) |
| One tactile button | ✅ [B0FHW6HMG4](https://www.amazon.com/dp/B0FHW6HMG4) |
| The meter, to map rails and find the switched legs | ✅ [B08BL288LW](https://www.amazon.com/dp/B08BL288LW) |

### Step 7 — OLED ✅ done

| Need | Link |
| --- | --- |
| One soldered OLED; keep a second packaged as a swap spare | ✅ [B09T6SJBV5](https://www.amazon.com/dp/B09T6SJBV5) |
| Four more male-to-male jumpers | 📦 [Jumper search](https://www.amazon.com/s?k=TODOELEC+10cm+Dupont+jumper+120) |

### Step 8 — microphone ✅ done

| Need | Link |
| --- | --- |
| One soldered INMP441 | ✅ [B092HWW4RS](https://www.amazon.com/dp/B092HWW4RS) |
| Six more male-to-male jumpers | 📦 [Jumper search](https://www.amazon.com/s?k=TODOELEC+10cm+Dupont+jumper+120) |
| One 10 kΩ and one 100 kΩ resistor, **meter-verified** | ✅ [B0F4P352BB](https://www.amazon.com/dp/B0F4P352BB) |

### Step 9 ✅ done · Step 10 ✅ done (2026-09-21)

No new components. Step 9 needs the phone camera and somewhere to save the
log. Step 10 needs a dedicated 2.4 GHz guest/IoT network with a unique
password, and a deliberate privacy decision; it passed on `A1` with one
remote response. No part fixes the SuperMini's
invisible setup hotspot; the assistant build caps transmit power at 8.5 dBm
instead. Do not buy an external antenna for these boards: they have no socket.
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

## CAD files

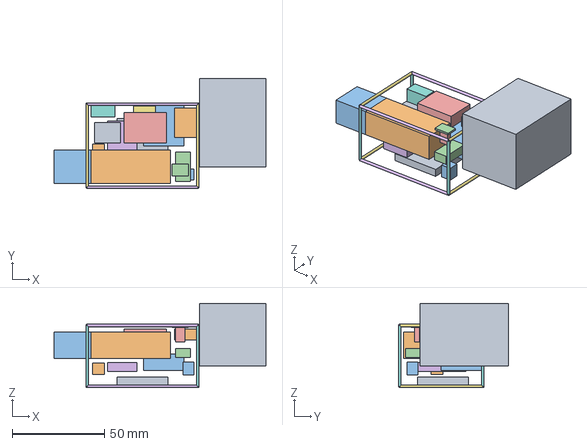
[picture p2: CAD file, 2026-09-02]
cad/pager_rev_a.step
115.0 x 59.7 x 45.7 mm

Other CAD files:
cad/pager_rev_a.FCStd

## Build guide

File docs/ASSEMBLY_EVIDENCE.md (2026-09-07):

# Why the R1 assembly was proposed — archived evidence

> **SUPERSEDED DESK STUDY; NOT PROOF OF A SAFE ASSEMBLY.** The independent
> audit found unresolved cell-current, USB-source, regulator, switch, and audio
> issues in this compact architecture. `hardware_tested` remains `false`.
> Use [FINAL_MATERIALS_FOR_REVIEW.md](FINAL_MATERIALS_FOR_REVIEW.md) for the
> current Phase 0 decision and promotion gates; the discussion below is kept
> so Claude can inspect the prior reasoning.

Three things set the honest ceiling on all of this:

1. **The reference device exists.** Someone built this from these part classes
   and it talks. We are not inventing an architecture; we are correcting a
   known-working one. That is the single strongest piece of evidence available.
2. **Nothing here has run on physical hardware in this workspace.**
   `firmware/source-build.json` records `"hardware_tested": false`. Every
   number below is a datasheet calculation or a static check.
3. **Therefore Phase 0 is not optional.** It converts this document from
   argument into evidence.

---

## The machine checks you can re-run

| Check | Command | What it proves |
| --- | --- | --- |
| Compile the current source | `firmware/scripts/build.sh` | Compiles the offline diagnostic image with pinned ESP-IDF v6.0.2 and records its actual inputs/digest; one build does not establish repeat-build identity or hardware operation |
| Static wiring checks | `python3 tools/netcheck.py` | GPIO/protocol constraints hold (pins, sample rate, strap rules). It does not check power, fit, or acoustics |
| Stale placement study | `freecadcmd cad/fitcheck.py` | **Stale** — models the withdrawn R0 architecture. Regenerate from measured R1 parts before treating any output as fit evidence |

---

## Phase 0 — bench bring-up

**Why it comes first:** every irreversible step (cutting brass, soldering a
frame, painting) is downstream of assumptions that a breadboard settles in an
afternoon and a finished sculpture makes expensive.

| Step | Evidence it rests on | What failure looks like |
| --- | --- | --- |
| `esptool flash_id` ≥ 4 MB | The partition table fills exactly 4 MB (`firmware/partitions/pocket-ai-4m.csv`) | Flash fails to write; a 2 MB clone bricks at boot |
| Confirm plain SuperMini | Only listing text distinguishes variants; a U.FL socket or RGB LED means a different board | Wrong pin map |
| I²C scan finds the display | Firmware probes 0x3C then 0x3D and falls back to headless (`pocket_wall_e_c3.cc`) | Neither address answers → check the module's silkscreen pin order |
| Mic records, amp plays | Datasheet agreement at 16 kHz (below) | Silence → meter the amp's `SD` pin |
| Bench power sweep 4.2 → 3.3 V under load | The LDO-direct rail analysis below | Reset during Wi-Fi burst → more bulk capacitance, then a bigger pack |
| Backend round trip | `CONFIG_OTA_URL` defaults to a third-party service | A beautiful object that cannot talk |
| Speaker choice | Same Sky publishes it plainly: *"Enclosure: Required"* — an unbaffled driver's front and back waves cancel | The phone-speaker fallback audible only held to your ear |

---

## The audio path — why 16 kHz is the only rate that works

Three parts must agree on one number, because they share one set of clocks.

| Part | Constraint | At 16 kHz |
| --- | --- | --- |
| MAX98357A | Datasheet, verbatim, twice: *"LRCLK clocks at 11.025kHz, 12kHz, 22.05kHz and **24kHz are NOT supported**"*; supported windows are 8, 16, 32, 44.1, 48, 88.2, 96 kHz | 16 kHz sits dead-centre in its fS2 window ✅ |
| INMP441 | Needs exactly 64 SCK per frame; SCK range 0.5–3.2 MHz | 16 000 × 64 = 1.024 MHz ✅ |
| Xiaozhi firmware | Opus voice encoder is hard-coded to 16 kHz | No input resampler needed; server audio uses the existing output resampler ✅ |

**The original build runs 24 kHz** — recovered from the vendor image
(`firmware/README.md`). The reference device sits on an operating point its
own amplifier's datasheet excludes. It evidently works, but nothing
guarantees it across part lots or temperature. 16 kHz is two numbers in
`config.h` and costs nothing: telephony and voice assistants live there.

`netcheck.py` enforces both constraints, so this cannot silently regress.

**The shared-clock trick works** because the ESP32-C3's I²S peripheral is
full-duplex: it transmits speaker samples and receives microphone samples in
the same frame. Four wires do the work of six. The one hazard: wire each clock
as a separate stub to each module, never daisy-chained — the amplifier's
datasheet warns that losing LRCLK while BCLK runs produces *"a large DC output
voltage"*, and DC is how voice coils die.

**Digital-audio correction:** the archived R1 review misapplied an Espressif
copy-mono comment. The pinned codec requests mono DMA with
`I2S_STD_SLOT_LEFT`, while the pinned ESP-IDF enables TX copy-mono only for a
`BOTH` slot mask. Source inspection therefore predicts active left and inactive
right TX slots. Hardware capture remains required, and the #3006 default mix
must not be assumed to produce full amplitude. See
the [amplifier lesson](../edu/fundamentals/10-class-d-btl-speakers-and-acoustics.md).

---

## The power path — the R1 numbers

The released chain is deliberately the reference's chain with a documented
protected pack:

```text
pack (3.0–4.2 V, PCM inside) → slide switch → SuperMini 5V pin → LDO → 3.3 V
                                            → MAX98357A VIN (2.5–5.5 V rated)
```

**Why each interface closes:**

| Interface | Evidence |
| --- | --- |
| Amp on the raw cell rail | MAX98357A datasheet: 2.5–5.5 V supply. 3.0–4.2 V sits inside it with margin on both ends |
| MCU/OLED/mic on the LDO | All three are 3.3 V parts. Above ~3.4 V cell the LDO regulates; below it the rail follows the cell minus dropout, and the ESP32-C3 runs to ~3.0 V. The reference device operates this way for its whole discharge |
| Peak load vs the pack | Worst coincident estimate: Wi-Fi TX ~335 mA (ESP32-C3 datasheet, 802.11b @21 dBm) + volume-limited amp peaks ~300–400 mA + OLED ~25 mA ≈ **0.7–0.8 A** transient at the cell — ~1.5C pulses on the 500 mAh pack. Short and infrequent; the bench sweep is the proof, and the 220 µF bulk cap carries the microseconds |
| Over-discharge | Pack PCM cuts at 3.0 V — below the useful operating floor anyway, so the device browns out (and the display dies) before the cell is endangered |
| Charging | #4410: CC/CV, 4.2 V termination, 100 mA default (0.2C) / 500 mA jumper (1C, the pack page's stated maximum). Device off while charging because there is no load sharing |
| Fault current | Pack PCM short-circuit protection + the JST as a hard disconnect. No separate fuse fitted — at these energies and with the pack's own protection, a fuse guards mainly against wiring errors the unpowered continuity check catches first |

**Runtime:** idle-listening ~130–150 mA at the cell → **≈ 3 h** on 500 mAh.
An estimate until measured; the R0 5–6 h figure assumed the withdrawn 950 mAh
16340.

**What was given up vs the withdrawn converter chain, knowingly:** regulation
of the last ~10 % of cell capacity (LDO dropout region), electronic UVLO
ahead of the PCM, and reverse-cell protection (the keyed JST connector and the
polarity check before first mating replace it). What was gained: roughly half
the device volume, five fewer failure-prone parts, and a build a beginner can
actually solder. The full trade-off record is in
[FINAL_MATERIALS_FOR_REVIEW.md](FINAL_MATERIALS_FOR_REVIEW.md).

---

## Why the pin map is safe

| Pin | Use | Evidence |
| --- | --- | --- |
| GPIO4 | mic data in | Moved off GPIO8. ESP32-C3 datasheet Table 3-3 marks GPIO2/8/9 as strapping pins; GPIO8 also carries the SuperMini's onboard LED. This build has **no OTA partitions**, so USB download mode is the only recovery path — losing it inside a soldered frame is permanent |
| GPIO2 | I²S BCLK | Strapping pin, so it gets a 10 kΩ pull-up per Espressif's schematic checklist |
| GPIO20/21 | I²C | Firmware `config.h`; verified against the netcheck |
| GPIO10 | action button | The firmware's only user input — chat toggle *and* long-press Wi-Fi reset |
| 11–17, 18–19 | untouched | SPI flash and native USB; netcheck asserts this |

A fair caveat from the adversarial pass: because this build sets
`CONFIG_ESP_CONSOLE_USB_SERIAL_JTAG=y`, esptool triggers download over USB
without the GPIO8 strap, so a board with an LED on GPIO8 would probably still
flash. Moving the mic to GPIO4 is cheap insurance that also frees GPIO8 to sit
at a defined level — not a fix for a proven failure.

---

## Why the frame is safe

**The frame carries no current.** The video uses the brass as its ground bus;
this build never does. That single decision removes the entire class of faults
where a structural joint becomes an electrical one.

- The pack lives behind a **fish-paper barrier**, connects only by its factory
  JST lead, and is never soldered. JST unplugged for every soldering,
  painting, cleaning, and flashing operation.
- **Paint is not insulation** — no rated dielectric strength, thins to nothing
  on edges, hides whether metal is live. Kapton, fish paper and heat-shrink do
  the insulating; paint (if used at all — the reference is raw brass) is
  decoration.
- Deburring every cut tube end is a safety step, not cosmetics: the acceptance
  rule is that no sharp edge can reach the pack.
- **USB service is physical:** switch off + JST unplugged before the
  SuperMini's port is used. No electronic mux exists to get confused.

**Antenna:** Espressif's layout guidance asks for clearance around the PCB
antenna. Keep the SuperMini's antenna end at the frame's edge with open air
beyond it (the reference does the same), and compare in-frame RSSI against
open air in acceptance test 10.5.

---

## What would falsify this

Honest failure modes, in rough order of likelihood:

1. **The bench sweep resets near 3.3 V under Wi-Fi + audio** → the clone's
   LDO or the pack's sag is worse than the reference's. Fix: more bulk
   capacitance; then a 1000 mAh-class pack; a boost converter is the last
   resort, not the first.
2. **A clone board differs** from its listing photo (LDO, VBUS path, flash
   size). This is why every marketplace part is bought in multipacks and
   qualified, and why the USB rule is procedural rather than trusting a diode
   that may not exist.
3. **The pack doesn't fit the frame you drew** → the cardstock dry-fit
   catches it before brass is cut. The #4237 350 mAh alternate is 7 mm
   shorter.
4. **The speaker is too quiet** through a grille → the A/B and the volume
   limit are set on the bench first.
5. **The backend is unacceptable** — unreachable, or you don't want your
   microphone audio going there. Fix: self-host, or stop at Phase 0.

Each of these is caught on a breadboard, before any brass is cut. That
sequencing is the real safety property of this plan.

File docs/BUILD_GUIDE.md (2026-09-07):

# Step-by-step build guide — archived R1 candidate

> **SUPERSEDED; DO NOT USE AS FINAL ASSEMBLY AUTHORITY.** This guide's compact
> #1578/direct-rail/generic-switch power architecture did not pass the final
> audit. It remains useful only for video timestamps and non-powered mock-up
> ideas. Follow [FINAL_MATERIALS_FOR_REVIEW.md](FINAL_MATERIALS_FOR_REVIEW.md)
> and do not connect a cell, cut brass, or install final wiring until its
> schematic, power, audio, fit, and finish gates close.

This guide follows the sequence of the reference video
([*\[Satisfying\] Building a Tiny Pocket AI Assistant*](https://www.youtube.com/watch?v=25RGnr407PM),
8:19, no narration — instruction is on-screen caption cards) so you can watch
each phase and then do the corrected version of it. Timestamps are ±5 s.
Where this guide differs from the video it says so explicitly and links the
reasoning in [edu/](../edu/README.md).

**Firmware note before anything else:** this guide wires for the repository's
**corrected source build** (microphone data on **GPIO4**, 16 kHz audio,
display probed at 0x3C/0x3D). If you instead flash the creator's published
image the way the video does at 5:20, you must wire the microphone's SD to
**GPIO8** and use a 0x3C display — the vendor image knows nothing about the
corrections. Don't mix the two.

**The old five-rule R1 shortcut is withdrawn.** OFF does not provide source
isolation and #4410 has no load sharing. The current
[power architecture](FINAL_MATERIALS_FOR_REVIEW.md#candidate-power-architecture)
uses physically separate battery-free and standalone-charge fixtures; no cell
connection is allowed without its signed release. Never solder to, unwrap,
heat, clamp, or puncture a cell; stop on swelling, warmth, damage, or odor.

---

## Materials

Shop only from the status-marked
**[current Phase 0 list](FINAL_MATERIALS_FOR_REVIEW.md)**. The archived R1
[MATERIALS.md](MATERIALS.md) is comparison evidence, not an order sheet. Read
the [power-integrity lesson](../edu/fundamentals/06-li-ion-power-integrity-decoupling-uvlo-thermal.md)
before any power work.

---

## Phase 0 — before cutting brass: prove everything on the bench *(not in the video)*

The video starts at the template. Don't. This firmware has **never run on
physical hardware** in this workspace, and the assistant is useless if its
cloud backend isn't acceptable to you.

1. **Build the current firmware.** Follow the
   [USB prototype quickstart](PROTOTYPE_QUICKSTART.md). It now defaults to
   offline diagnostics, not the networked application assumed by this archived
   procedure. The old two-clean-build result applies to the earlier source
   revision only; current evidence is recorded in the build manifest.
2. **Qualify the boards.** `esptool flash_id` → 4 MB minimum. Plain SuperMini
   only (one blue LED, no U.FL socket — a "Plus" variant with a WS2812 on
   GPIO8 cannot use this pin map).
3. **Flash a bare SuperMini and test the backend.** Provision Wi-Fi, pair at
   xiaozhi.me (video 6:00 shows the flow), confirm one full voice round trip.
   The default backend is `api.tenclass.net` — a third-party service that
   receives your microphone audio. Decide *now* whether that's acceptable;
   self-hosting a Xiaozhi-compatible server and changing `CONFIG_OTA_URL` is
   the alternative.
4. **Breadboard the full stack** — OLED (I2C scan: 0x3C generic / 0x3D
   Adafruit), INMP441 records, MAX98357A plays. Meter the amp's `SD` pin:
   ~0.30 V stock (mix mode — fine); **~0 V means shutdown** — rework.
   Speaker leads only to the amp's terminals — never to a breadboard rail.
5. **Bench power test — the R1 chain from a current-limited supply.** Wire
   supply (+) → slide switch → SuperMini `5V` + amp `VIN` (with the 220 µF
   bulk cap fitted), supply (−) → common GND. Set 4.2 V, 1 A limit:
   - device boots, display up, one voice round trip completes;
   - sweep the supply 4.2 → 3.3 V under Wi-Fi + loud audio: **no reset**
     anywhere in the range (below ~3.4 V the LDO is in dropout — the MCU
     rides the sag; that's the reference topology's behavior);
   - toggle the slide switch 20× — clean boot every time;
   - record idle current (~expect 100–180 mA) and peak behavior. If Wi-Fi
     bursts reset the board near 3.3 V, double the bulk capacitance before
     blaming a module.
6. **Charger check, no cell yet.** Plug the #4410 into USB-C alone: 5V pad
   present, JST polarity verified against the pack's connector **with a
   meter, not by wire color**. First real charge happens in Phase 8.
7. **Acoustic A/B (only if using the phone-speaker fallback):** primary
   CES-20134-088PM vs fallback at 0.5 m and 1 m; wake word ("Hi, ESP") at
   1 m and 2 m. If it fails on the bench, no soldering fixes it.
8. Run `python3 tools/netcheck.py` — the static wiring rules must pass before
   you commit the layout.

## Phase 1 — template *(video 0:50–1:10)*

The video: modules measured with a steel ruler, outline drawn on paper with a
machinist square (his marks: ~40 mm × ~15 mm). **Copy the method; derive your
own numbers from the real parts.** The R1 target envelope is **≈ 45 × 32 ×
20 mm**: OLED face front; pack (29 × 36 × 4.75 mm) flat against the back;
SuperMini + amp + mic in the middle layer; charger board edge-mounted so its
USB-C faces out; switch and button reachable on the top face.

Lay the *actual parts* on cardstock. Draw every wire route. Confirm the
SuperMini's antenna end has clear space (no brass, wiring, or pack directly
over the antenna region — give it the board-edge overhang the reference uses).
Nothing gets cut until the cardstock version closes, and
`cad/fitcheck.py` is regenerated from your measured parts if you want the CAD
check (the committed report models the withdrawn architecture and is stale).

## Phase 2 — bend and solder the frame rectangles *(video 1:10–1:30)*

As the video does: bend 1.5 mm brass tube over the template with round-nose
pliers, two matching rectangles. Cut with a jeweler's saw — never flush
cutters, which crush the 0.225 mm wall. Deburr and dome every cut end
(no sharp edge may ever reach the pack).

Solder the frame with the brass process: Harris SCLF4 zinc-chloride flux
(acid-class — it exists ONLY at this empty-frame stage), 2–3 mm chisel tip at
370–400 °C, joints abraded and fluxed immediately before heating. Corner
posts and braces from the #9861 1.0 mm rod; rectangles from the #9831 tube.
**The frame is completed, washed (hot water + baking-soda rinse + IPA), and
optionally painted before any electronic part exists near it.**

## Phase 3 — complete the cage; do NOT glue the OLED yet *(video 1:30–2:05)*

The video glues the OLED into the front rectangle at 1:30, then solders the
four corner posts around it. **Invert that order**: solder all four corner
posts first, finish *all* hot work, wash, then (optionally) paint, then mount
the display. Gluing glass-bearing modules into a frame you're still soldering
is how displays die.

Finish choice: the reference is raw brass — that's fine, the frame carries no
current in this build. If painting white, follow
[edu/05_COLOR_AND_FINISH.md](../edu/05_COLOR_AND_FINISH.md); either way, paint
is decoration — Kapton/fish paper do the insulating.

## Phase 4 — insulation and the power spine *(video has no equivalent)*

The video free-forms everything and uses the frame as the ground bus (4:20:
"I'll connect all the ground connections directly to the brass frame").
**This build never passes current through the frame.** Instead:

1. **Line the pack bay first**: fish paper under and around where the pack
   sits — the flame-rated layer between the cell and everything else. Kapton
   over any module back or splice that can reach brass.
2. Mount the charger board where its USB-C port exits the frame; hot-glue at
   the corners, port and status LED visible.
3. **Battery spine, in order:**
   `pack JST ↔ charger battery port` (or via the JST pigtail splitter), then
   `charger BAT pad → slide switch → switched-positive bus`, and
   `charger GND pad → common ground bus`. The switched bus feeds the
   SuperMini `5V` pin and the amp `VIN`; the ground bus collects every
   return. 26 AWG for the spine, 30 AWG for signals. Sleeve every junction.
4. **Caps:** 220 µF bulk + 10 µF ceramic at the amp's VIN/GND; 10 µF at the
   SuperMini's `5V` entry; 100 nF at OLED and mic supplies.

The pack itself goes in **last** (Phase 7) — the spine is built and tested
with the JST unplugged.

## Phase 5 — wire the modules *(video 2:10–3:35, changed)*

The video piggybacks the amp on the ESP32-C3 with five stiff 1 mm jumpers and
stacks the mic on shared clocks. Keep the *architecture* (shared BCLK/WS,
separate data), change the details:

| Signal | ESP32-C3 | Video | Corrected |
| --- | ---: | --- | --- |
| OLED SDA / SCL | 21 / 20 | same | same — read the silkscreen pin order first (GND/VCC order varies by vendor) |
| I2S WS (mic + amp) | 1 | same | same — **two separate stubs**, never daisy-chained (a broken WS with BCLK alive = DC into the speaker) |
| I2S BCLK (mic + amp) | 2 | same | same + 10 kΩ pull-up to 3.3 V (strap pin) |
| Amp DIN | 3 | same | same |
| Mic SD | **4** | GPIO8 | moved to **GPIO4** + 100 kΩ pull-down; GPIO8 gets a 10 kΩ pull-up instead |
| Action button | 10 | absent | GPIO10 → tact switch → GND, 10 kΩ pull-up + 100 nF |
| Power | `5V` pin | same | same idea — but from the **protected, switched** bus, never a bare cell |

Amp specifics: do not assume stock `SD` mix mode plays at full amplitude.
Source inspection predicts an active left and inactive right TX slot; capture
both and select a compatible channel mode before any audio promotion (see the
[amplifier lesson](../edu/fundamentals/10-class-d-btl-speakers-and-acoustics.md)).
Mic select goes low for the intended
left slot. Speaker leads form a twisted pair at the amp's output terminals;
**neither lead ever grounded or touching the frame**.

Mic handling: port tape stays on until final test; solder only at the header
pads; no flux/IPA/hot-air near the port; all heat-shrink work happens
*before* the mic joins the assembly.

## Phase 6 — the switch *(video 4:25–4:35, corrected)*

Video: a slide switch soldered to the frame, switching the raw cell into the
`5V` pin. R1 keeps the same part and the same job — but it switches the
**protected** positive lead, its terminals are sleeved, and its body mounts
with glue/epoxy to a frame member without its terminals touching brass. It
fails open = pager off. Unplugging the pack's JST is the hard disconnect.

## Phase 7 — battery *(video 4:35–5:05 — DO NOT copy this phase)*

The video strips the cell's wrapper and solders its can to the frame. That
sequence is the reason this repository exists. Corrected: the protected pack
slides into its fish-paper-lined bay, connects **only by its factory JST
lead**, and is retained by a strap/guard so it cannot chafe or escape —
removable by hand for service. The JST stays unplugged for every soldering,
painting, cleaning, or flashing operation, and while the unfinished device is
transported.

Before the first connection: meter the JST polarity against the charger's
markings, and check pack voltage (3.0–4.2 V; outside that, stop).

## Phase 8 — charging *(video 5:05–5:20, kept — with rules)*

The video wires a Type-C module permanently to the cell; R1 does the same,
with a charger whose current is documented (#4410: 100 mA default). The
rules:

- **Switch OFF while charging** (no load sharing on this class of board).
- **First charge attended**, on a non-flammable surface; pack cool to the
  touch; confirm the DONE LED and 4.20 ± 0.05 V at the pack.
- Only after a clean first cycle may you close the #4410's jumper for 500 mA
  (= 1C for the 500 mAh pack; leave at 100 mA for the 350 mAh alternate).

## Phase 9 — flash and configure *(video 5:20–6:35, same idea)*

The video flashes at web.esphome.io and pairs at xiaozhi.me. Do both during
Phase 0 with the bare SuperMini. For the assembled unit the rule is simple
and physical: **slide switch OFF and pack JST unplugged before the
SuperMini's USB-C is connected.** With the pack out of circuit, USB feeds
only the SuperMini's LDO and the 3.3 V peripherals — all rated for it.

Then `./scripts/flash.sh` (or the video's web flasher only for vendor-image
wiring), the Wi-Fi captive portal, and xiaozhi.me pairing as shown at
5:40–6:35.

**The source build is finalized for English:** wake word **"Hi, ESP"**
(`wn9s_hiesp` — say the letters), en-US display strings, spoken prompts and
activation digits. On first boot the device shows and *reads aloud* a 6-digit
code; enter it at xiaozhi.me and set the agent's language and voice to
English there too. (The vendor image instead answers to Mandarin
"ni hao xiao zhi" and boots in Chinese.)

## Phase 10 — bring-up gates *(not in the video; do them all)*

With a meter (and the bench supply for step 2):

1. Pack unplugged: every frame member ↔ BAT+, GND, 3.3 V, each signal, and
   both speaker leads open/high-resistance. This build has no deliberate
   frame bond.
2. Bench supply at the pack's JST position (4.0 V, 1 A limit) → boot,
   display, mic, amp, one voice round trip in final geometry.
3. Toggle the switch 20× — clean boot every time.
4. Ten minutes of loud audio + Wi-Fi → amp warm is fine; nothing too hot to
   touch; pack bay (still empty) unobstructed.
5. Wi-Fi in final geometry vs the bare board in open air at fixed distance:
   compare RSSI/reconnections; investigate any large degradation (brass near
   the antenna region is the usual suspect).
6. Only now does the pack live in the pager (Phase 7 checks), then Phase 8's
   attended first charge.

Current acceptance authority: the
[F0 promotion gates](FINAL_MATERIALS_FOR_REVIEW.md#promotion-gates-before-claude-may-say-final-go).

---

## What you'll have

A **≈ 45 × 32 × 20 mm** brass cage pager — video-scale — running the
corrected 16 kHz source firmware: OLED face, wake-word voice chat over
**Wi-Fi only** (a phone hotspot covers the street; cellular is out of scope),
half-duplex conversation (no barge-in on this chip). Estimated ~3 h of
always-on listening from the 500 mAh pack (measure it — acceptance test).
Speech is processed by the configured cloud backend. Not a replica of the
video's raw-cell sculpture — the same object, with a power system you can
hand to someone without a safety briefing. Well — a shorter one.

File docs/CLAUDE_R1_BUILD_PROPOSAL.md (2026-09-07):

# Claude R1 compact-build proposal — archived for review

> **ARCHIVED CANDIDATE; NOT PURCHASE OR ASSEMBLY AUTHORITY.** This is the
> unaltered substance of Claude's 2026-09-02 R1 proposal, retained so its
> reasoning can be reviewed. Independent power, digital-audio, and purchasing
> audits found release blockers. Use
> [FINAL_MATERIALS_FOR_REVIEW.md](FINAL_MATERIALS_FOR_REVIEW.md) for the
> reconciled procurement decision.
>
> **Original proposal status text follows for provenance:**
>
> **RELEASED FOR PURCHASE AND STAGED ASSEMBLY — 2026-09-02 final audit.**
> This document supersedes the R0 qualification release (which held the power
> system at NO-GO behind a Pololu buck-boost/fuse/16340 chain). The final audit
> found that architecture safe on paper but **triple the reference device's
> volume and indefinitely blocked** — the opposite of the project goal, which is
> a compact pocket device faithful to the
> [reference build](https://www.huyvector.org/robots-kinetic/pocket-ai-assistant)
> and its [video](https://www.youtube.com/watch?v=25RGnr407PM).
> R1 returns to the creator's power topology and makes it safe with documented
> parts and hard procedural rules, instead of replacing it.

**GO:** the complete R1 cart below, breadboard bring-up, frame fabrication
after the cardstock dry-fit closes, and staged final assembly per
[BUILD_GUIDE.md](BUILD_GUIDE.md).
**Still gated:** first cell connection, first attended charge, and pocket
carry. The current authority is the
[F0 promotion-gate list](FINAL_MATERIALS_FOR_REVIEW.md#promotion-gates-before-claude-may-say-final-go).

## The audit question, answered

*Can the materials be configured, soldered, and assembled into a compact
pocket AI assistant that talks over Wi-Fi?* **Yes — with the R1 part set
below.** The evidence:

- **The reference device exists and works** with exactly these part classes:
  ESP32-C3 SuperMini + SSD1306 OLED + INMP441 + MAX98357A + 8 Ω speaker +
  1S Li-ion + Type-C charge board + slide switch, free-formed in a brass frame.
- **Historical firmware build claim.** The then-current source port compiled
  twice with identical output. That evidence belongs to the earlier revision,
  not the current [source-build record](../firmware/source-build.json). Its pin/rate contract
  is legal per every datasheet involved (see
  [ASSEMBLY_EVIDENCE.md](ASSEMBLY_EVIDENCE.md)).
- **Every electrical interface closes on paper.** All modules are 3.3 V-logic
  compatible; the MAX98357A accepts 2.5–5.5 V so it runs happily from the raw
  cell; the SuperMini's onboard LDO makes 3.3 V from the cell for the MCU,
  OLED, and mic — the same arrangement the working reference uses.
- **The two genuinely dangerous things in the video are replaced, not
  reproduced**: the mystery `14250 1200 mAh` cell soldered by its can to the
  frame (replaced by a documented **protected** pack with a factory connector),
  and the frame-as-ground-bus wiring (the R1 frame is electrically floating).

What remains honest: `hardware_tested: false` — nothing in this workspace has
run on a physical board yet. That is why the build procedure is bench-first:
every part is proven on a breadboard, and the power chain from a
current-limited supply, before anything is soldered into the frame.

## R1 architecture

```text
protected 1S LiPo pack (protection PCM inside the pack, factory JST-PH lead)
  ↔ USB-C charge board, in the frame (charging port, like the video)
  → SPDT slide switch in the protected positive lead
  → switched battery bus (3.0–4.2 V)
      → ESP32-C3 SuperMini "5V" pin → onboard LDO → 3.3 V
            → OLED (I2C), INMP441 (I2S)
      → MAX98357A VIN (rated 2.5–5.5 V, so the raw cell rail is in-spec)
          + 220 µF bulk capacitor at the amp's VIN/GND (recommended)

speaker: MAX98357A OUT+/OUT− only — floating BTL pair, never grounded
brass frame: structure only — never GND, never a power or signal conductor
```

Deliberate deviations from the video, all safety-driven, all kept from the
earlier reviews:

1. **Protected pack, never a bare/mystery cell.** The video's `14250 1200 mAh`
   is almost certainly a primary Li-SOCl₂ cell mislabelled as rechargeable
   (see [BOM.md](BOM.md)); soldering to any cell's can remains **REJECT**.
2. **Frame floating.** All returns go through wires; Kapton/fish-paper
   insulation where conductors cross brass.
3. **Source firmware contract**: mic data on **GPIO4** (not the vendor GPIO8),
   16 kHz audio, OLED probed at 0x3C/0x3D. Vendor-image wiring (GPIO8) is
   documented separately and never mixed with this map.
4. **Charge current matched to the cell** (100→500 mA documented, not an
   unconditioned 1 A module).
5. **Hard rules** (below) for USB and charging states, since this simple
   topology has no load-sharing or source-mux hardware.

### The five hard rules

These are the whole price of the compact topology. They go on the bench card
and in every procedure:

1. **Slide switch OFF before plugging in either USB-C port** (SuperMini or
   charger), and never both USB ports at once. Most SuperMini clones tie the
   `5V` pin straight to USB VBUS; with the switch on, USB would meet the cell.
2. **Device OFF while charging.** The charge board has no load sharing; a load
   confuses CC/CV termination.
3. **First charge attended**, on a non-flammable surface, cell cool to the
   touch throughout; verify 4.20 ± 0.05 V termination.
4. **Never solder to, puncture, unwrap, or heat a cell.** The pack connects
   only by its factory lead. Cell disconnected (JST unplugged) for all
   soldering, painting, cleaning, and flashing.
5. **Stop conditions:** swelling, heat, odor, damaged insulation → disconnect
   if safe, move away, do not build on.

## R1 bill of materials — the released cart

Verification legend: **✅** = listing/product page fetched and specs read
during this audit cycle · **⚠️** = verify stated property on arrival.

### Electronics (digital + audio)

| Role | Released part | Why | Check |
| --- | --- | --- | --- |
| Controller | Plain **ESP32-C3 SuperMini**, USB-C, ≥4 MB flash — 3-pack (e.g. Amazon [B0G5XS345R](https://www.amazon.com/dp/B0G5XS345R) or [B0F888JQ91](https://www.amazon.com/dp/B0F888JQ91) 10-pack) | Reference layout; matches firmware/CAD | ⚠️ gate every board with `esptool flash_id` ≥ 4 MB; plain variant only (one blue LED, no U.FL, no WS2812) |
| Display | **0.96" SSD1306 128×64 I2C, white, 4-pin** — 5-pack (e.g. [B09T6SJBV5](https://www.amazon.com/dp/B09T6SJBV5)) | Creator-faithful, thin, 3.3 V, 0x3C (firmware also probes 0x3D) | ⚠️ read silkscreen pin order — vendors ship GND-VCC and VCC-GND variants |
| Microphone | **INMP441 I2S MEMS** breakout — 5-pack (e.g. [B092HWW4RS](https://www.amazon.com/dp/B092HWW4RS)) | Creator's exact mic; 64-SCK I2S at 1.024 MHz is in-spec; 3.3 V | `L/R` → GND (left slot). Alternate: Adafruit [#6049 ICS-43434](https://www.adafruit.com/product/6049) (controlled board, `SEL` → GND) — either works with the source build |
| Amplifier | **MAX98357A I2S class-D** breakout — HiLetgo 3-pack ([B0CDWXZZCH](https://www.amazon.com/dp/B0CDWXZZCH)) or Adafruit [#3006](https://www.adafruit.com/product/3006) | Creator's amp; 2.5–5.5 V VIN covers the cell rail | Stock SD ≈ 0.30 V = mono mix = full amplitude (see the [amplifier lesson](../edu/fundamentals/10-class-d-btl-speakers-and-acoustics.md)); GAIN floating = 9 dB |
| Speaker | **Same Sky CES-20134-088PM** — 8 Ω, 0.8 W, factory-enclosed, ~20 × 16 × 4.9 mm, bare leads ([DigiKey 2223-CES-20134-088PM-ND](https://www.digikey.com/en/products/detail/same-sky-formerly-cui-devices/CES-20134-088PM/10821309)) ×2 | Sealed rear cavity solves the hardest acoustic problem at phone-speaker size | Software volume limit keeps average ≤ 0.8 W. Fallback: video-style phone speaker (undocumented specs — A/B it) |
| Action button | 6×6 mm tact switch (+cap), from any kit (e.g. [B0FHW6HMG4](https://www.amazon.com/dp/B0FHW6HMG4)) | GPIO10 → GND, active low; chat toggle + long-press Wi-Fi reset | Onboard GPIO9 is ROM BOOT, not this input |

### Power — the audit's headline change

| Role | Released part | Why | Check |
| --- | --- | --- | --- |
| Cell | **Adafruit #1578** — 3.7 V 500 mAh LiPo, **protected** (overcharge, 3.0 V over-discharge cutout, short protection), JST-PH lead, 29 × 36 × 4.75 mm, $7.95 ✅ verified in stock 2026-09-02 | Documented protection + connector; half the volume of the withdrawn 16340+holder stack; ~3 h estimated idle-listening runtime | ⚠️ no thermistor — charge ≤ 500 mA per its own page. Smaller alternate: [#4237](https://www.adafruit.com/product/4237) 350 mAh protected |
| Charger (in frame) | **Adafruit #4410** — USB-C Micro-Lipo, 24 × 19 × 7.2 mm, 100 mA default / 500 mA via solder jumper, 4.2 V termination, JST battery port + 5V/GND/BAT breakout pads, $5.95 ✅ verified in stock 2026-09-02 | Documented current, right size, JST mates the pack directly; mounts in the frame like the video's Type-C board | Leave 100 mA for first charges; close the jumper (500 mA = 1C) only after a clean attended cycle. Creator-faithful alternate: TP4056-class USB-C module **only if** it carries DW01A+FS8205 protection and its 1.2 kΩ `Rprog` is replaced (3 kΩ ≈ 400 mA) |
| Power switch | **Mini SPDT slide** (SS12D00 class), e.g. from 25-pack [B09R434VJQ](https://www.amazon.com/dp/B09R434VJQ) | Creator's part; in the protected positive lead it is a true battery break | ⚠️ measure contact drop < 50 mV at 0.5 A on the chosen sample; average load ~0.15–0.25 A, transients < 1 A ms-scale |
| Bulk + local caps | 220 µF electrolytic at amp VIN; 100 nF + 10 µF ceramics at each module supply (e.g. [B0C1VBXCQM](https://www.amazon.com/dp/B0C1VBXCQM) + [B07P7HRGT9](https://www.amazon.com/dp/B07P7HRGT9)) | Wi-Fi + class-D transients on a shared cell rail | Fit the 220 µF from the start; the reference gets away without it, you might not |
| Pull/pulldown resistors | 10 kΩ (GPIO2 pull-up, button pull-up), 100 kΩ (GPIO4 pulldown) from any metal-film kit ([B0F4P352BB](https://www.amazon.com/dp/B0F4P352BB)) | Strap-pin hygiene per Espressif checklist | — |
| JST splitter/pigtail | JST-PH 2.0 mm pigtail pair | Taps the load off the pack↔charger connection without soldering to the pack | ⚠️ genuine JST-PH is 2.0 mm pitch — the old "2.5 mm JST-PH" claim was wrong |

**What the pack's PCM covers:** overcharge, over-discharge (3.0 V), and output
shorts — so no separate fuse, P-FET, or UVLO module is fitted. The LDO-direct
rail means the device browns out as the cell approaches the 3.0 V cutout
instead of regulating to the last millivolt: identical behavior to the
reference, and acceptable for R1. If bench testing shows resets during Wi-Fi
bursts near end-of-discharge, the fix is the 220 µF bulk cap and, failing
that, a bigger pack — not a return to the withdrawn converter chain.

### Frame, insulation, consumables

| Role | Released part | Note |
| --- | --- | --- |
| Frame tube | **K&S #9831** 1.5 mm OD × 0.225 mm wall brass, 4× 300 mm ([ksmetals](https://ksmetals.com/products/br225mm-1h)) | The reference's exact stock. Cut with jeweler's saw only; deburr every end |
| Frame rod | **K&S #9861** 1.0 mm brass rod, 5× 300 mm ([ksmetals](https://ksmetals.com/products/brrmet-1)) | Braces/posts; telescopes in the tube |
| Cell barrier | Fish paper 0.2 mm ([B0GZVDKBBS](https://www.amazon.com/dp/B0GZVDKBBS)) or Formex GK-10 | Flame-rated layer under/around the pack — mandatory |
| Local insulation | Kapton tape ([B072Z92QZ2](https://www.amazon.com/dp/B072Z92QZ2)), heat-shrink kit ([B08N4W4K9X](https://www.amazon.com/dp/B08N4W4K9X)) | Module backs, frame crossings, every splice |
| Wire | 26 AWG silicone (power/speaker, [B07G2LRX68](https://www.amazon.com/dp/B07G2LRX68)) + 30 AWG (signals, [B073RDGTPB](https://www.amazon.com/dp/B073RDGTPB)) | Speaker pair twisted; signals short |
| Adhesive | Electronics-safe hot glue + sparing CA | The video's method; keep away from mic port, switch, USB |
| Finish (optional) | Raw brass like the reference, or the white system in [edu/05_COLOR_AND_FINISH.md](../edu/05_COLOR_AND_FINISH.md) | Paint is decoration, never insulation |

### Tools

The owned X-Tronic 3020-XTS kit, CQ4LF flux pen, BOENFU cutters, WORKLION mat,
and OLFA cutter stand (see [MATERIALS.md](MATERIALS.md) for the
reconciliation). Still required: multimeter, current-limited bench supply
(the one non-negotiable instrument — it stands in for the cell during every
power test), calipers, jeweler's saw + pliers, wire strippers 26–30 AWG,
solder wick, heat gun, safety glasses, ventilation. 63/37 or verified
electronics solder for boards; hard-solder/flux for the empty frame only,
washed and neutralized before any electronics exist near it.

## Size and runtime targets

Provisional envelope **≈ 45 × 32 × 20 mm** plus the USB-C port projections —
set by the OLED face (27.5 × 27.8 mm), the pack (29 × 36 mm laid flat as the
back plane), and the charger board edge-mounted for port access. That is
video-scale, and roughly half the volume of the withdrawn R0 layout. The
number is a **target, not fit evidence**: the cardstock dry-fit with real
parts governs, and `cad/fitcheck.py` must be regenerated from measured parts
before brass is cut (the existing FITCHECK_REPORT models the withdrawn
architecture and is stale).

Runtime estimate: ~130–150 mA average from the cell while idle-listening →
**≈ 3 h** on 500 mAh. An estimate until measured (acceptance test 8.4).

## Withdrawn by this audit (R0 → R1)

Retained as history in the linked files; none of it is in the R1 cart.

| R0 item | R1 status | Reason |
| --- | --- | --- |
| Pololu #2873 buck-boost + #2810 MOSFET switch + PICO fuse chain | **WITHDRAWN** | Solved a marginality the reference proves survivable, at 3× device volume and an unbounded test program. The protected pack + rules cover the same failure classes at pocket scale |
| Nitecore NL169 16340 + MPD BH123A holder + external charger | **WITHDRAWN** | Cylindrical cell + holder is the single largest volume item; NL169's protection specs were never documented anyway. The Adafruit pack documents what the NL169 page does not |
| Oscilloscope/current-probe/load-step instrumentation gates | **RELAXED to recommended** | Right for a production release; disproportionate for a one-off that the bench supply, DMM, and staged bring-up adequately screen |
| 60 × 45 × 33 mm CAD envelope and 162-rule fitcheck | **STALE** | Models the withdrawn architecture; regenerate from measured R1 parts |
| `14250 1200 mAh` video cell; soldering to any cell | **REJECT (unchanged)** | Chemistry unproven, likely primary Li-SOCl₂; both remain prohibited |
| Frame as GND/power/speaker conductor | **REJECT (unchanged)** | Energized exposed structure in a pocket |
| Parallel PPTCs, unreviewed P-FET pairs, adjustable-output regulators, boost-only/buck-only converters | **REJECT (unchanged)** | The R0 analysis of these stands |
| "JST-PH 2.5 mm" | **REJECT (unchanged)** | JST-PH is 2.0 mm pitch |

## Release gates that remain

1. **Bench gate (before frame work):** full stack on a breadboard from USB +
   bench supply — flash, OLED at 0x3C/0x3D, mic capture, amp playback, one
   full cloud round trip; power chain from the current-limited supply swept
   3.3 → 4.2 V under Wi-Fi + audio load with no reset. Speaker A/B if using
   the phone-speaker fallback.
2. **Fit gate (before cutting brass):** cardstock 1:1 dry-fit with the real
   parts closes; every port, button, switch, mic hole, and the pack's removal
   path reachable.
3. **Unpowered gate (after mounting):** frame isolated from every net; no
   BTL lead grounded; polarity verified at the JST before first connection.
4. **Cell gate:** pack connected only after gates 1–3; first charge attended
   per the hard rules.
5. **Pocket gate:** every applicable
   [current F0 promotion gate](FINAL_MATERIALS_FOR_REVIEW.md#promotion-gates-before-claude-may-say-final-go)
   passes before the device rides in a pocket.

## Primary references

- [Reference build page](https://www.huyvector.org/robots-kinetic/pocket-ai-assistant) · [assembly video](https://www.youtube.com/watch?v=25RGnr407PM)
- [Firmware board configuration](../firmware/src/boards/pocket-wall-e-c3/config.h) · [source-build evidence](../firmware/source-build.json)
- [Adafruit #1578 protected 500 mAh pack](https://www.adafruit.com/product/1578) · [#4410 USB-C Micro-Lipo charger](https://www.adafruit.com/product/4410)
- [MAX98357A datasheet](https://www.analog.com/media/en/technical-documentation/data-sheets/max98357a-max98357b.pdf) · [INMP441 datasheet](https://invensense.tdk.com/wp-content/uploads/2015/02/INMP441.pdf)
- [Same Sky CES-20134-088PM](https://www.sameskydevices.com/product/audio/speakers/miniature-%2810-mm~40-mm%29/ces-20134-088pm)
- [ESP32-C3 datasheet](https://www.espressif.com/sites/default/files/documentation/esp32-c3_datasheet_en.pdf)
- Procedures: [BUILD_GUIDE.md](BUILD_GUIDE.md) · [WIRING_AND_ASSEMBLY.md](WIRING_AND_ASSEMBLY.md) · [staged integration lesson](../edu/fundamentals/13-debugging-integration-and-capstone.md)

## Release verdict

**GO for the complete R1 cart and the staged build procedure. The cell
connects only after the bench gate; charging and pocket carry only after
their gates.** The device this releases is a compact, video-faithful brass
pager running the corrected 16 kHz source firmware — with a protected,
removable, never-soldered power system and a frame that carries no current.

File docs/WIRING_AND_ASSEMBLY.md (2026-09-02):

# Wiring, assembly, and staged test guide — archived R1 candidate

> **SUPERSEDED; DO NOT WIRE THE POWER SECTION BELOW.** The digital GPIO table
> remains useful, but the #1578/direct-rail/generic-switch power chain is not
> accepted. The current Phase 0 parts and candidate power topology are in
> [FINAL_MATERIALS_FOR_REVIEW.md](FINAL_MATERIALS_FOR_REVIEW.md), and no cell
> connection or final assembly is released. The source build uses microphone
> data on GPIO4; the creator image uses GPIO8. Never mix those maps.

## Power rules

1. Use only the released **protected** pack (or its protected alternate) with
   intact insulation and its factory JST lead. Never charge an `ER14250`,
   `LS14250`, or other primary Li-SOCl₂ cell; never use an undocumented cell.
2. Do not solder to, strip, puncture, clamp, or use the brass frame as a
   terminal for any cell. The pack connects only by its connector.
3. The charger's 4.2 V termination and programmed current must match the
   pack: #4410 ships at 100 mA; 500 mA (jumper) only for the 500 mAh pack
   after a clean attended first cycle. A stock 1 A TP4056 module is not used
   unchanged.
4. **Keep the device off while charging.** This class of charge board has no
   power-path/load-sharing controller.
5. **Slide switch OFF and pack unplugged before USB-C goes into the
   SuperMini.** Never attach both USB-C ports at once. SuperMini clone power
   paths vary; use continuity/diode mode once on your exact board to learn
   whether USB VBUS and the `5V` pin are directly or diode-connected — then
   follow the rule regardless.
6. Insulate the frame from battery positive and every exposed powered node.
   Strain-relieve every wire. The frame floats: no ground, power, or signal
   ever runs through brass.

Stop immediately if the pack swells, leaks, dents, becomes hot, smells
unusual, or has damaged insulation. Disconnect external power only if that
can be done safely; do not touch or move a hot or venting cell. Move people
away and follow the cell maker's emergency procedure.

## Signal wiring — source build (current firmware)

| ESP32-C3 SuperMini | Destination | Destination pin | Electrical note |
| --- | --- | --- | --- |
| `3.3V` | SSD1306 OLED | `VCC` | From the SuperMini's LDO output, not the raw cell rail |
| `GND` | SSD1306 OLED | `GND` | Common ground bus |
| GPIO21 | SSD1306 OLED | `SDA` | Firmware probes address `0x3C`, then `0x3D` |
| GPIO20 | SSD1306 OLED | `SCL` | 128×64 geometry; 400 kHz requested |
| `3.3V` | INMP441 | `VDD` | Microphone supply |
| `GND` | INMP441 | `GND`, `L/R` | `L/R` low = left slot (ICS-43434 alternate: `SEL` low) |
| GPIO1 | INMP441 + MAX98357A | `WS`, `LRC` | Shared I2S word select — separate stub to each module |
| GPIO2 | INMP441 + MAX98357A | `SCK`, `BCLK` | Shared I2S bit clock + 10 kΩ pull-up to 3.3 V (strap pin) |
| GPIO4 | INMP441 | `SD` | Mic data in + 100 kΩ pull-down. **Vendor image uses GPIO8 instead** |
| GPIO3 | MAX98357A | `DIN` | Audio data out |
| GPIO10 | Action button | other leg to `GND` | Active low; 10 kΩ pull-up + 100 nF. GPIO9 remains ROM BOOT |
| Switched battery bus | SuperMini `5V` + MAX98357A `VIN` | — | 3.0–4.2 V from the protected pack through the slide switch; 220 µF + 10 µF at the amp's VIN/GND |
| `GND` bus | MAX98357A | `GND` | Common ground |
| MAX98357A `OUT+`/`OUT−` | Speaker | two leads | Floating bridge (BTL) load — **neither speaker lead ever goes to ground or frame** |

Why the `5V`-pin feed works: the SuperMini's onboard LDO regulates the cell's
3.0–4.2 V down to ~3.3 V for the MCU and peripherals (in dropout below
~3.4 V input, where the rail sags gracefully — the reference device runs
exactly this way), and the MAX98357A's own 2.5–5.5 V rating covers the raw
cell rail directly. Verify stable operation across 3.3–4.2 V on the bench
(build guide Phase 0.5) before final assembly.

## Power wiring — one topology

```text
protected pack (JST-PH) ↔ charger board battery port
charger BAT pad → SPDT slide switch → switched-positive bus → SuperMini 5V + amp VIN
charger GND pad → common ground bus → every module GND
```

- The pack's protection PCM stays in circuit by construction (it's inside the
  pack, upstream of the JST). Never bypass it or solder past it.
- The load taps the charger board's `BAT`/`GND` pads (or a JST splitter) so
  the pack is never soldered.
- Charger USB-C is a charging input only, device switched off.
- Never infer pad function from board color or marketplace photos — read the
  silkscreen and beep it out.

## Build in this order

The full staged procedure with video timestamps is
[BUILD_GUIDE.md](BUILD_GUIDE.md); this is the wiring-level summary.

### 1. Bench-test the electronics before making the frame

- Pack and charger disconnected. Inspect each module for bridges; verify pin
  labels against silkscreen (marketplace boards vary).
- Breadboard ESP32-C3 + OLED + mic + amp with insulated jumpers; speaker only
  at the amp's own terminals via a short twisted pair.
- Power from the SuperMini's USB data cable for flashing and digital tests.
- For full-load audio + Wi-Fi tests, power the switched bus from a
  current-limited bench supply (4.2 → 3.3 V sweep, no USB attached at the
  same time), per build guide Phase 0.5.

### 2. Make a physical template

- Real parts on cardstock; target ≈ 45 × 32 × 20 mm but let the parts decide.
- Access for both USB-C ports, BOOT, the switch, button, mic port, charger
  LED, and the pack's removal path.
- Mark insulation, wire routes, and the antenna keep-out before cutting brass.

### 3. Form and solder the unpowered frame

- Eye protection. Jeweler's saw, deburr, bend with pliers over the template.
- Brass flux/solder on the empty structural frame only; wash and neutralize
  per the flux data sheet. No electronics anywhere near this operation.
- After cleaning: no sharp edge anywhere the pack or wiring can reach.

### 4. Mount and wire modules — pack absent

- Fish paper lines the pack bay; Kapton on module backs and frame crossings.
- Mic hole, display face, speaker outlet, ports, and controls stay clear.
- Route switched-positive, ground, I2C, and I2S as distinct insulated nets.
- With no pack: resistance-check every rail to ground, every net to frame,
  and both speaker leads to everything (all open).

### 5. Current-limited power test in final geometry

- Bench supply at the pack's JST position, 4.0 V / 1 A limit. Boot, display,
  mic, amp, round trip; switch toggles; ten minutes of loud audio + Wi-Fi
  with nothing more than warm.

### 6. Add the pack last

- Meter JST polarity against the charger markings before the first mating.
- Retain the pack mechanically (strap/guard); strain-relieve its lead.
- First charge: attended, device off, non-flammable surface, pack cool,
  DONE LED, 4.20 ± 0.05 V.

## Firmware and functional acceptance checklist

- [ ] Source build digest matches `firmware/source-build.json` (or vendor
      image verified by `tools/pocket_ai_device.py verify`).
- [ ] Explicit serial port and `esp32c3` chip identity confirmed.
- [ ] Switch OFF + pack unplugged during every USB flash.
- [ ] OLED initializes (0x3C or 0x3D), shows the UI, no persistent I2C errors.
- [ ] INMP441 records intelligible audio with `L/R` grounded.
- [ ] MAX98357A drives the speaker; neither output lead grounded.
- [ ] Assistant survives repeated Wi-Fi association + loud audio without
      brownout/reset, on the bench supply and then on the pack.
- [ ] On a clean boot the `Xiaozhi-XXXX` provisioning AP appears and the
      captive portal works at `192.168.4.1`.
- [ ] The cloud backend's privacy posture is acceptable before speaking
      sensitive content near the device.
- [ ] Attended first charge passes: current ≤ programmed value, 4.2 V
      termination, pack cool, device off.
- [ ] No energized conductor or sharp edge can contact the pack, user, keys,
      or coins; all wiring strain-relieved; frame floats from every net.

## Known limitations of the reference (and this build)

- No editable schematic, enclosure drawing, battery datasheet, or exact
  speaker spec is published on the project page; this repository's released
  design substitutes documented parts where the reference used mystery ones.
- The firmware talks to a third-party Xiaozhi-compatible cloud service; it is
  not an offline/on-device language model. Self-hosting is the alternative.
- The creator's links are not stable part numbers; several resolve to
  variants that differ from the labels on the page.
- This topology has no load sharing and no USB source mux — the five hard
  rules are the mitigation, and they are procedural, not electronic. If you
  want plug-and-play USB behavior, that is a Rev B carrier-board project.

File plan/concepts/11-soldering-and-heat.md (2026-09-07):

# 11 — Soldering: heat flow makes the connection

[Concept index](README.md) · [Day 11 lab](../DAILY_STUDY_AND_LAB_PLAN.md#day-11--soldering-practice-before-project-hardware)

**The idea:** soldering is controlled heating and surface bonding, not sticking
two cold objects together with a blob of metal.

## What the physics is doing

Heat is energy transferred because of a temperature difference. The hot iron
transfers energy into the cooler pad and component lead. They, in turn, lose
energy into the board and air. A large copper area carries heat away more
readily than a tiny isolated pad.

Temperature tells you how hot something is; it does not tell you how quickly
heat can enter the joint. A tiny contact can transfer heat slowly even when the
station displays a high temperature. A suitable chisel tip contacts both
surfaces and can heat them promptly. The station display is not a thermometer
inside your joint.

Heat flows from an iron into both pad and lead; a second panel contrasts solder spreading along metal with a bead that has not wetted the surface.

*Arrows show heat flow, not electric current. The joint shapes are simplified
cross-sections, not an appearance-only acceptance test.*

**Wetting** means molten solder spreads onto a solderable surface and bonds at
the interface. Oxide and dirt interfere. Electronics flux helps remove oxide
during heating; it cannot replace heating both workpieces. Letting a large
drop fall from the iron onto a cold pad can leave a weak connection underneath.

## A small energy example

For a solid warming without melting:

```text
heat energy ≈ mass × specific heat capacity × temperature rise
E = m × c × ΔT
```

For an illustrative copper piece, assume `m = 0.10 g`,
`c ≈ 0.39 J/(g·°C)`, and a `200 °C` rise:

```text
E ≈ 0.10 × 0.39 × 200 = 7.8 joules
```

Ten times as much copper needs about ten times the energy for the same rise.
Real soldering also heats other material and loses heat continuously, so this
is **not** a temperature or dwell-time recipe.

## Why it matters for your prototype

Practice on the Day 11 sacrificial wire/header samples, with project parts
unpowered and batteries absent. Use the lab's ventilation, eye protection,
electronics-flux, and hand-washing precautions. No extra parts are needed.

Look for wetting onto both surfaces, unintended bridges, damaged insulation,
and lifted pads. Then check continuity and adjacent-node isolation with power
absent. Shine alone is not quality: alloy affects appearance, and lead-free
joints can be sound without a mirror finish. More heat can damage the board
without fixing contamination or poor tip contact.

## Predict before reading

Two equal-temperature tips touch a large pad: one barely touches it; the other
has a broad, well-wetted contact. Which is likely to heat the joint sooner?

<details>
<summary>Answer</summary>

The broad contact usually transfers heat faster. That can shorten the time the
part spends being heated. Tip suitability and surface condition matter, not
just the temperature setting; verify the process on your practice samples.

</details>

Go deeper: [Lesson 12 — wetting, tip choice, and inspection](../../edu/fundamentals/12-soldering-mechanics-insulation-tolerance.md#a-joint-is-a-controlled-metallurgical-interface).

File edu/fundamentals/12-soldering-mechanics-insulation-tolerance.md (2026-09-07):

# 12 — Soldering, mechanics, insulation, and tolerances

## Learning objectives

After this lesson, you should be able to:

- explain wetting, flux, heat flow, and why solder is not glue;
- make and inspect a practice electrical joint before touching project parts;
- separate electrical soldering from structural metalwork;
- design strain relief and insulation for a conductive enclosure;
- reason about nominal dimensions, tolerance, clearance, and tolerance stacks;
- identify where sound, radio, buttons, connectors, and the cell need space.

## A joint is a controlled metallurgical interface

Molten solder must **wet** the clean metal surfaces. Wetting means the solder
spreads and bonds at the interface instead of sitting as a ball. Three things
must happen together:

1. the surfaces must be solderable and free of disruptive oxide or dirt;
2. flux must remove or inhibit oxide while the joint is hot; and
3. both workpieces—not merely the solder wire—must reach the needed
   temperature for the needed time.

The iron transfers heat; solder supplies the alloy; flux enables wetting. A
tiny amount of solder on the tip improves thermal contact, but feeding all the
solder onto the tip can leave the workpieces too cold.

During soldering, a thin intermetallic layer forms between solder and the base
metal. Too little heat gives incomplete wetting. Excessive heat or dwell time
can damage pads, insulation, plastic connectors, microphones, and nearby
components. More temperature is not a substitute for the correct tip size,
clean surfaces, flux, and contact area.

## Electrical versus structural soldering

The pocket assistant contains two very different tasks:

- **Electrical joints:** small copper pads, wires, and headers. Use
  electronics-grade flux and solder with controlled heat.
- **Structural metalwork:** a brass or other metal shell/frame with much higher
  thermal mass and possibly a surface finish. It may need different surface
  preparation, flux, alloy, heat source, and ventilation.

Do not let aggressive acid/plumbing flux touch electronics. Residue can be
corrosive or conductive. Do not heat the enclosure with boards, display,
speaker, microphone, wiring, foam, or battery installed. Build and clean the
structure separately; mechanically finish it; then install electronics.

Whether a particular structural joint can be made safely with the purchased
iron is a **MEASURED process-qualification question**, not something CAD can
answer. Practice on offcuts of the exact stock and finish first.

Never solder directly to a lithium-ion cell. Use an intact, protected cell and
a mechanically matching connector/contact system specified for it.

## Tip, temperature, and thermal mass

Heat energy flows from the tip into the work. A very fine tip has little
contact area and stored thermal energy, so it may struggle with a ground plane
or metal frame even when its displayed temperature is high. A broader chisel
tip often heats a pad and lead faster, reducing total dwell time.

Use the lowest process temperature that produces prompt, repeatable wetting
with the actual solder alloy. Follow the solder/flux and component
manufacturers' limits. The station display is tip-heater feedback, not a
measurement of the component body or joint temperature.

For an electrical through-hole joint:

1. clean and mechanically stabilize the work;
2. wet the clean tip with a small amount of solder;
3. touch pad and lead together with the tip;
4. feed solder at the joint, not only onto the tip;
5. remove solder, then the iron;
6. hold still while it solidifies; and
7. clean residue if the flux process requires it.

Always use fume extraction or effective local ventilation and eye protection.
Wash hands after handling solder and do not eat at the bench. “Lead-free” does
not make fumes, flux, heat, or sharp clippings harmless.

## What inspection can and cannot prove

A good small electrical joint normally shows complete wetting of pad and lead,
a smooth continuous fillet, no unintended bridge, and no scorched laminate or
receded insulation. Appearance depends on alloy; lead-free joints need not look
mirror-bright.

Visual inspection finds many defects but not all of them. Follow it with:

- an unpowered continuity/net check;
- a gentle strain inspection of the wire's support, not a pull on the pad;
- current-limited functional testing; and
- voltage-drop measurement for important power paths.

A beeping continuity meter does not prove a high-current joint has low enough
resistance.

## Wires need mechanical support

A solder joint should make an electrical connection, not act as the only cable
anchor. Motion concentrates stress where flexible wire becomes rigid with
solder. Provide strain relief so the load is transferred to the enclosure or a
tie point before it reaches the pad.

In this mechanical-load sketch, arrows show force rather than current:

```text
external cable force
          ↓
cable jacket ── clamp / tie point ──→ enclosure
                         │
                         └── slack loop ── conductor ── solder pad
                                                        (little cable load)
```

Useful methods include a clamped cable jacket, lacing/tie points, adhesive made
for the materials and temperature, a service loop, and heat-shrink over a
spliced wire. Check that strain relief does not block a connector latch,
microphone port, speaker vent, antenna region, or service access.

Avoid wicking solder far up stranded wire; the stiffened section moves the
fatigue point rather than eliminating it.

## Conductive enclosure: insulation is a system

A white/silver metal enclosure is electrically conductive even if it is painted
or powder-coated. Decorative finish is not dependable primary insulation:
edges, screw heads, scratches, soldered seams, and abrasion can expose metal.

For each board and wire, define:

- a primary insulating barrier with a known material and thickness;
- edge and corner clearance;
- mechanical retention that prevents migration;
- protection against cut wire ends and solder spikes;
- inspection access; and
- a plan for heat without squeezing the cell.

The metal frame should not be used as the project's current return unless a
future reviewed schematic deliberately makes it one. A floating frame is not
automatically harmless: capacitive coupling, loose conductors, ESD, or a cut
insulation layer can still create faults.

## Dimensions are distributions, not perfect numbers

A drawing's nominal `20.0 mm` dimension is a target. Real parts vary. A
tolerance such as `20.0 ± 0.2 mm` permits values from `19.8` to `20.2 mm`.
Marketplace modules may also change layout without changing the listing.

For a simple worst-case clearance:

```text
minimum clearance
  = smallest available opening
  - largest possible installed part
```

If a slot is `20.2 ± 0.2 mm` and the received module is
`20.0 ± 0.15 mm`, then:

```text
smallest slot = 20.0 mm
largest module = 20.15 mm
minimum clearance = -0.15 mm
```

**CALCULATED:** the nominal `0.2 mm` gap can become a `0.15 mm` interference.
The design is not released merely because nominal CAD bodies do not collide.

### Tolerance stacks

Several small variations add along an assembly path: enclosure bend, bracket,
adhesive, board edge, connector body, plug, and cable bend radius. In an early
prototype, add the worst cases conservatively and measure exact received
parts. Statistical tolerance analysis becomes appropriate only with a known
manufacturing process and distribution.

## Functional keepouts

A component's rectangular body is not its whole envelope:

| Part | Space that a box model often misses |
| --- | --- |
| Connector | mating plug, latch, finger access, insertion/removal path, cable bend |
| Button/switch | actuator travel, finger/tool access, service clearance |
| Speaker | front opening, rear volume, seal, diaphragm excursion, wires |
| Microphone | acoustic port path, gasket/seal, contamination protection |
| Antenna | RF keepout, nearby metal/plastic, product-use orientation |
| Battery | wrapper protection, contacts, removal path, swelling/fault clearance |
| Board | solder joints, wire loops, programming cable, component height variation |

An enclosure can pass collision checking and still be unassemblable,
unserviceable, acoustically poor, or unsafe.

## Build order for this project

The robust order is:

```text
qualify soldering on scrap
→ measure exact received parts
→ make a paper/cardstock or printed fit mock-up
→ build and clean the empty metal structure
→ deburr and inspect every edge
→ install primary insulation and mechanical mounts
→ install already bench-tested electronics without a cell
→ test access, strain relief, acoustics, heat, and RF
→ introduce the protected cell only after the electrical release gates pass
```

This is deliberately different from soldering a shell around live,
irreplaceable electronics.

## Safe lab: a practice coupon and tolerance stack

### Part A — electrical coupon

Use scrap protoboard, inexpensive wire, and a resistor—not a project module.

1. Make five joints with the intended solder, flux, tip, and ventilation.
2. Photograph both sides and label tip, set temperature, and approximate dwell.
3. Inspect for wetting, bridges, pad damage, and melted insulation.
4. With power off, measure continuity and isolation to adjacent pads.
5. Anchor one wire with strain relief, leave another supported only by its pad,
   and gently move the cable near the anchor. Observe where bending concentrates.
6. Improve the process until five consecutive joints pass the same criteria.

Do structural-metal experiments on a separate offcut with electronics absent.

### Part B — paper tolerance model

Measure one received board in length, width, and maximum height. Add envelopes
for its connector, plug, cable bend, mounting/insulation thickness, and tool or
finger access. Cut both nominal and conservative maximum outlines from card.
Fit the conservative outline through the intended assembly and removal path.
Record what the model still omits.

## Common mistakes

- Treating solder as filler or glue instead of heating both interfaces.
- Raising temperature indefinitely when the real problem is an oxidized or
  undersized tip.
- Using plumbing flux near electronics.
- Assuming “no-clean” always means residue is harmless in every process.
- Using paint or anodizing as the only barrier against a metal enclosure.
- Modeling only component bodies, not plugs, cables, sound paths, and hands.
- Choosing wire length before the assembly and service routes are proven.
- Installing the cell before heating, drilling, deburring, or soldering the frame.

## Check yourself

1. Why can a broader tip expose a component to less total heating than a needle
   tip on a large pad?
2. Is a visually good solder joint sufficient evidence for a power connection?
3. Why is a painted metal frame still treated as conductive?
4. A module and opening both fit at nominal size. What two additional checks
   are required before release?

<details>
<summary>Answers</summary>

1. Better contact and thermal capacity can bring both surfaces to soldering
   temperature quickly, reducing dwell time.
2. No. Add unpowered checks and a loaded voltage-drop/functional test.
3. Finish can be thin, scratched, cut at edges, or penetrated by hardware; it
   is not reliable primary insulation.
4. Analyze worst-case tolerance/clearance and physically test the exact part's
   complete installation, connector, cable, access, and removal envelopes.

</details>

## Authoritative further reading

- [NASA workmanship standard for soldered electrical connections](https://standards.nasa.gov/standard/NASA/NASA-STD-87394)
- [Kester soldering knowledge base](https://www.kester.com/knowledge-base)
- [JST PH connector family drawing (2.0 mm pitch)](https://www.jst-mfg.com/product/pdf/eng/ePH.pdf)
- [Espressif ESP32-C3 PCB and antenna layout guidance](https://docs.espressif.com/projects/esp-hardware-design-guidelines/en/latest/esp32c3/pcb-layout-design.html)

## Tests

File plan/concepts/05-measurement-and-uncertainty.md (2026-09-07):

# Measurement: your meter joins the circuit

[Concept index](README.md) · [Day 5 lab](../DAILY_STUDY_AND_LAB_PLAN.md#day-5--measurement-as-a-controlled-experiment)

Optional reading · about 5 minutes · builds on parallel circuits and dividers.

## The physical idea

Measuring requires an interaction. A voltmeter draws a small current; a
current meter introduces a small voltage drop. Your instrument observes a
slightly changed circuit, not a circuit it magically leaves untouched.

A **voltmeter** compares two nodes, so it connects in **parallel**. Its high,
but finite, input resistance minimizes the extra current.

An **ammeter** measures current through itself, so it goes in **series**.
Its low internal resistance minimizes the added voltage drop, called
**burden voltage**. Low does not mean zero.

Two complete circuits: a voltmeter connected in parallel across a resistor, and an ammeter inserted in series with a resistor. A warning says never connect current mode across a source.

These drawings explain topology; they are not instructions to change a live
circuit. Day 5's current measurement is optional. Power off before moving
leads, verify the manual, fuse, jack, and range, and return the red lead to
the voltage jack afterward. **Never put current mode across a source.**

## One worked example: the meter loads a divider

Two `10 kΩ` resistors across `3.3 V` predict `1.65 V` at their midpoint.
Suppose a voltmeter has **1 MΩ input resistance**—an illustrative value,
not a specification for your meter. Connecting it from midpoint to GND
puts that resistance in parallel with the lower resistor:

```text
R_lower = 10,000 Ω || 1,000,000 Ω ≈ 9,901 Ω
V_measured = 3.3 × 9,901 / (10,000 + 9,901) ≈ 1.642 V
```

The roughly `8 mV` shift is a circuit effect, even with an otherwise perfect
meter. A plausible unloaded voltage still does not prove a divider can power
a module. Here `||` means “in parallel”; GND is the circuit's voltage
reference, not necessarily an earth connection.

## Digits are not the same as knowledge

| Word | What it tells you |
| --- | --- |
| Resolution | The smallest displayed change, such as 0.001 V. |
| Accuracy | How close the result is to the actual value under specified conditions. |
| Repeatability | How closely repeated readings agree under the same conditions. |

A meter can repeatedly show `3.300 V` while having a systematic error. For a
**toy accuracy bound** of ±1% of reading, `3.30 V` means approximately
`3.267–3.333 V`; your meter's real specification may also include counts,
range, and temperature terms.

A rail briefly falls from 3.3 volts to 2.7 volts for 100 microseconds. A slower meter reading can remain near 3.3 volts and fail to reveal the short dip.

A normal DMM reading can miss a fast rail dip because its measurement and
display updates average or sample over time. More displayed digits do not
make it a fast waveform recorder.

## In your prototype

Use your owned meter for polarity, steady voltage, and unpowered resistance
checks. Record **where**, **relative to what**, **in which mode**, and **under
what load** you measured. If the MCU resets despite a plausible reading,
mark fast-transient behavior unknown; this page does not require another tool.

<details>
<summary>Check yourself: ten identical voltage readings prove what—and not what?</summary>

They support repeatability under those conditions. They do not by themselves
prove accuracy, negligible meter loading, or absence of brief voltage dips.

</details>

Go deeper: [Lesson 05: measurement methods and safe connection procedures](../../edu/fundamentals/05-measurement-dmm-supply-scope-logic-analyzer.md).

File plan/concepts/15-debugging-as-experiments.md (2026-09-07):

# 15 — Debugging: ask the next question that separates causes

[Concept index](README.md) · [Day 15 lab](../DAILY_STUDY_AND_LAB_PLAN.md#day-15--battery-free-integration-and-debugging-capstone)

**The idea:** debugging is experimental science on a small system. A symptom
is an observation; a cause is an explanation that must survive useful tests.

## Start with competing explanations

“The screen is blank” does not tell you whether the board booted, the OLED
answered on I²C, or software drew any pixels. Write two or three plausible
causes, then choose a safe observation that predicts different outcomes for
them. This is a **discriminating test**.

You already do this in software: checking whether a request reached the server
separates a network problem from application behavior. Here, boot logs, bus
acknowledgments, and pixel diagnostics expose different hardware layers.

A blank OLED leads to checking the known diagnostic boot log, then its I2C probe result; each observation narrows the next investigation without claiming proof of all hardware behavior.

*A probe acknowledgment means some device answered at that address. It does
not prove that the display pixels, timing margins, or every connection work.*

## A concrete debugging example

Suppose the controller logs its expected diagnostic version, but the OLED is
blank. Consider:

| Explanation | What would help distinguish it? |
| --- | --- |
| The OLED is not reachable on the bus | Diagnostic address-probe result |
| The display responds but has a pixel/configuration problem | The existing all-pixels toggle result |
| Different firmware or pins are in use | Printed build identity and the wiring map |

If a probe reports a response, total loss of bus connectivity becomes less
likely; that observation does not eliminate intermittent wiring or a wrong
display type. If an all-pixels toggle works, the panel can display under those
conditions. A later blank application screen is now more likely to involve
application state or content, but you still verify rather than guess.

Change one relevant thing, rerun the original failure test, and check the
previously working button/microphone behavior. Otherwise the “fix” may have
introduced a regression or merely coincided with a loose wire moving.

## Confidence is not universal proof

An observation has a scope: **this board, this firmware, this wiring, this
power source, these conditions**. Ten successful starts are better evidence
than one, but do not guarantee every temperature or future wire position.
An unmeasured fast voltage dip stays unknown even if the multimeter looks steady.

Save a small record: symptom → hypotheses → test → result → next conclusion.
Keep the last known-good wiring photo and serial transcript. A narrowly stated
pass is more useful than “everything works.”

## Why it matters for your prototype

Use Day 15's existing offline diagnostics and USB-only, amplifier-absent setup.
Disconnect USB before changing wires and keep all grounds intact. This page
adds reasoning, not new fault-injection exercises or battery tests. Isolating a
problem often costs no new parts; an unsupported measurement can simply remain
inconclusive.

## Predict before reading

You change three wires and rebuild firmware; the screen starts working. Have
you isolated the cause?

<details>
<summary>Answer</summary>

No. Several explanations fit the result. Save the working state, then use the
logs and safe, controlled comparisons to isolate the relevant difference.
Do not recreate an electrically unsafe state just to make the explanation
more certain.

</details>

Go deeper: [Lesson 13 — hypotheses and separating tests](../../edu/fundamentals/13-debugging-integration-and-capstone.md#hypotheses-and-discriminating-tests).

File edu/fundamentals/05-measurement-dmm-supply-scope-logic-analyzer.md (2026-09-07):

# 05 — Measurement: DMM, bench supply, scope, and logic analyzer

## Learning objectives

After this lesson, you should be able to:

- choose an instrument that can answer a specific electrical question;
- measure voltage, resistance, continuity, and current without creating a short;
- use constant-voltage and current-limit controls on a bench supply;
- explain what a DMM can miss during a fast transient;
- capture I2C or I2S with a logic analyzer; and
- record a measurement so another person can reproduce it.

## Measurement is a controlled experiment

A meter does not simply reveal “the truth.” It becomes part of the circuit and
answers one question over a limited range and bandwidth. Before touching a
probe, write the question:

- Is 3V3 present relative to circuit ground?
- Is this connection open or continuous while power is off?
- How much current enters the whole assembly at idle?
- Does SDA acknowledge address `0x3C`?
- Does the rail dip below the controller's minimum during an audio burst?

That wording determines the instrument, connection, range, and test condition.

## Digital multimeter: the four common jobs

### Voltage

A voltmeter measures the potential difference **between two nodes**. Connect
it in parallel with the circuit being observed:

```text
3V3 o──────── load ───────o GND
    │                     │
    └───────( V )─────────┘
```

Put the black lead in `COM`, the red lead in the voltage/resistance jack, and
select DC volts. For the pager, “3.3 V” is incomplete unless the reference is
named: normally `3V3 relative to circuit GND`.

A DMM input is usually high resistance, so it draws little current. It can
still give a plausible voltage on a weakly coupled or floating node. A voltage
reading alone does not prove that a supply can deliver load current.

### Resistance and continuity

Resistance and continuity modes inject their own small test stimulus. Use them
only on an **unpowered** circuit whose capacitors have discharged.

Continuity answers “is the measured resistance below this meter's beeper
threshold?” It does not prove:

- that a solder joint can carry the intended current;
- that two boards use the same connector pin order;
- that a 0.3-ohm path is acceptable; or
- that a diode or semiconductor is healthy.

First touch the probes together and note the lead resistance. Very low
resistances are better evaluated by forcing a known current and measuring the
voltage drop: `R = V / I`.

### Diode mode

Diode mode reports a forward voltage under a small test current. It is useful
for checking a diode's direction and finding obvious shorts through protection
devices. In-circuit parallel paths can alter the result, so compare both probe
directions and consult the schematic.

### Current

An ammeter becomes a low-resistance part of the branch, so it must go **in
series**:

```text
supply + o────( A )──── device VIN
supply - o──────────── device GND
```

Move the red lead to the correct fused current jack, select a range above the
expected current, open the circuit, and insert the meter. Never touch a
current-mode meter across a supply; that is nearly a short through the meter's
fuse. Return the lead to the voltage jack immediately afterward.

For time-varying loads, an inline current meter also adds a small voltage drop
called burden voltage. A supply readout plus a scope across a current shunt is
often more informative for fast peaks.

## The current-limited bench supply

A bench supply has two interacting controls:

- **CV, constant voltage:** the supply holds the set voltage while the load
  takes less than the current limit.
- **CC, constant current:** the load tries to take too much, so the supply
  lowers its output voltage to keep current at the limit.

CC is not automatically a fault—it is the promised protection behavior—but an
unexpected transition into CC is evidence to stop and investigate.

### Safe first-power sequence

1. Disconnect the circuit.
2. Set the target voltage.
3. Set a deliberately low current limit appropriate for the stage under test.
4. Turn the output off.
5. Verify polarity at the cable end with a DMM.
6. Connect ground first and then positive.
7. Turn the output on while watching both voltage and current.
8. Stop for unexpected CC operation, heat, odor, or noise.
9. Raise the limit only after the measured behavior explains why more is safe.

The exact starting limit depends on what is connected. It is not a universal
number. Power one subsystem at a time and use its documented consumption plus
margin.

## Oscilloscope: voltage versus time

A DMM may update only a few times per second. A rail can average 3.30 V while
briefly collapsing during Wi-Fi or speaker peaks. A scope can show those
events, clock edges, ripple, ringing, and startup order.

This conceptual rail trace shows why the two instruments can report different
views of the same event (not to scale):

```text
rail voltage
3.30 V  --------------------+       +--------------------
                            |       |
                            +-------+
                              short dip
        -------------------------------------------------> time

DMM:   a few slow readings may miss the interval
scope: a captured trace shows the dip's depth and duration
```

Three settings matter immediately:

- **vertical scale:** volts per division;
- **timebase:** seconds per division; and
- **trigger:** the event that stabilizes the display.

Use the probe's short ground spring for fast edges when possible. A long ground
lead adds inductance and can create ringing that is mostly the measurement
setup.

Many bench scopes connect the probe ground clip to protective earth. Clipping
it to a non-ground node can short that node to earth. Confirm the scope,
supply, and circuit references before connecting. This is especially important
around bridge-tied speaker outputs: neither output is ground.

Record probe attenuation (`1x` or `10x`), coupling, bandwidth limit, sample
rate, vertical scale, and where both probe leads were connected.

## Logic analyzer: digital timing and protocol

A logic analyzer classifies voltages as 0 or 1 and samples them over time. It
is ideal for questions such as:

- Was there an I2C START?
- Which 7-bit address was sent?
- Did the OLED ACK?
- Are I2S `BCLK` and `WS` present at the expected frequencies?
- Does a control pin change before or after reset?

Connect analyzer ground to circuit ground, verify that its inputs tolerate the
logic voltage, and sample comfortably faster than the fastest signal. Ten times
the bit clock is a useful starting point, not a mathematical guarantee. Set the
decoder's address convention, clock polarity, word length, and sample edge to
match the protocol and firmware.

A logic analyzer cannot show how much analog margin an edge has. If a decoder
fails intermittently, inspect the actual waveform with a scope.

## Instrument loading and bandwidth

Every instrument has limits:

| Instrument | It adds or assumes | Easy-to-miss problem |
| --- | --- | --- |
| DMM voltmeter | finite input resistance/capacitance | fast dips and noise |
| DMM ammeter | shunt resistance and fuse | burden voltage and fast peaks |
| Scope probe | resistance, capacitance, ground path | probe-induced ringing or short |
| Logic analyzer | threshold and input capacitance | marginal analog levels |
| Bench supply | cable resistance and control-loop response | voltage at supply differs from voltage at board |

Measure the rail at the load as well as at the supply. A cable or connector may
drop voltage under current even when the supply display looks perfect.

## Worked rail-drop example

Suppose the supply display says 3.30 V and 420 mA during a loud tone, while a
DMM at the controller reads 3.21 V.

**MEASURED:** path drop `Vdrop = 3.30 V - 3.21 V = 0.09 V`.

**CALCULATED:** the total resistance of positive and return paths is roughly:

```text
Rpath = Vdrop / I = 0.09 V / 0.420 A ≈ 0.21 Ω
```

This value includes leads, contacts, switches, protection parts, solder joints,
and PCB traces. It does not identify the culprit. Measure smaller sections
under the same load to localize the drop. Then use a scope at the controller to
check whether short dips are worse than the DMM average.

## Safe lab: characterize a resistor load

Use a current-limited supply, DMM, a `1 kΩ` resistor rated at least `0.25 W`,
and jumper leads. No battery is required.

1. With power off, measure the resistor and label the result **MEASURED**.
2. Calculate expected current at `3.3 V`: `I = V/R`, about `3.3 mA` for exactly
   `1 kΩ`.
3. Set the supply to `3.3 V` with a `10 mA` limit; verify cable polarity.
4. Connect the resistor, turn on the output, and measure voltage across it.
5. Insert the DMM in series to measure current, then return its lead to the
   voltage jack.
6. Calculate `R = V/I` and compare with the unpowered resistance reading.
7. Set the current limit below the load current and observe CC mode. Explain
   why both voltage and current change.

Do not substitute an LED without a series resistor.

## A reproducible measurement record

Use a fresh [lab record template](reference/lab-record-template.md) rather than
maintaining another field list here. “It worked” cannot be audited; a dated
trace tied to an exact unit, setup, prediction, and pass/fail rule can.

## Common mistakes

- Leaving the red lead in the current jack and later trying to measure voltage.
- Measuring resistance on a powered board.
- Calling circuit ground “zero everywhere”; current causes real drops along
  conductors.
- Using a DMM average to approve transient-sensitive power.
- Trusting an auto-decoder without checking protocol settings and waveforms.
- Moving a grounded scope clip between nodes while the circuit is powered.
- Reporting extra decimal places that the instrument cannot justify.

## Check yourself

1. Where is an ammeter placed, and why must it not be placed across a supply?
2. The supply shows `CC` and only `0.8 V` despite a `3.3 V` setting. What does
   that mean?
3. Why might a DMM show a healthy rail while the ESP32-C3 resets?
4. What must be recorded with an I2C logic-analyzer capture?

<details>
<summary>Answers</summary>

1. In series with the measured branch. Its low-resistance shunt would nearly
   short a source if connected across it.
2. The load is demanding more than the set limit, so the supply is lowering
   voltage to hold the limit. Turn off and explain the demand before proceeding.
3. The reset may be caused by a short voltage dip faster than the DMM's update
   rate, or by a local drop the meter was not probing.
4. At least the device, firmware, probe points, voltage, sample rate, decoder
   settings, operating condition, and expected address/transaction.

</details>

## Authoritative further reading

- [Fluke: how to measure voltage with a digital multimeter](https://www.fluke.com/en-us/learn/blog/digital-multimeters/how-to-measure-voltage-with-a-digital-multimeter)
- [Fluke: how to measure current with a digital multimeter](https://www.fluke.com/en-us/learn/blog/digital-multimeters/how-to-measure-current-with-a-digital-multimeter)
- [Saleae: logic analyzer tutorial](https://www.saleae.com/support/tutorials-learning/guides/logic-analyzer-tutorial)
- [Tektronix: oscilloscope fundamentals](https://www.tek.com/en/documents/primer/oscilloscope-basics)

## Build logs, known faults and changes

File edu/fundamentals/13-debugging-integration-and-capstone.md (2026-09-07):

# 13 — Systematic debugging and the capstone

## Learning objectives

After this lesson, you should be able to:

- bring up a mixed power, digital, audio, and RF system one layer at a time;
- turn a vague symptom into competing, testable hypotheses;
- choose a measurement that separates those hypotheses;
- distinguish diagnosis from qualification and qualification from release;
- write a test plan with conditions, stop rules, and acceptance limits;
- complete a battery-free capstone that exercises the whole course.

## Debugging is information gathering

“The OLED does not work” is a symptom, not a cause. Possible causes include:

- no input power;
- missing or low 3V3 rail;
- reversed connector pins;
- no common return;
- firmware using different GPIOs;
- absent or excessive I2C pull-ups;
- wrong address;
- reset or boot failure;
- a solder open/bridge; or
- a damaged or different module revision.

Changing several things at once may hide the cause. Good debugging finds the
cheapest safe observation that separates hypotheses.

## The bring-up ladder

Do not assemble every subsystem and then apply cell power. Move through layers:

```text
0  documents and exact part identity
          ↓
1  visual and mechanical inspection, power off
          ↓
2  continuity, isolation, and resistance sanity, power off
          ↓
3  input path and rails from a current-limited supply
          ↓
4  controller boot and serial log
          ↓
5  one digital bus and one peripheral at a time
          ↓
6  audio at low level, then controlled load changes
          ↓
7  transient, fault-containment, and thermal tests
          ↓
8  enclosure, acoustic, control-access, and RF A/B tests
          ↓
9  protected cell integration only after an explicit release review
```

At each layer, define what “pass” means before testing. If a lower layer fails,
do not debug a higher one. A protocol trace is meaningless if the target rail
is absent.

## Step 0: freeze the test article, not the design forever

Record enough identity that a result applies to one known article:

- exact seller/manufacturer and order code;
- photographs of both sides and visible chip markings;
- measured dimensions, connector pitch, pin labels, and pin order;
- schematic/BOM revision;
- firmware commit and build command;
- configuration, jumpers, and wiring map; and
- serial number or simple unit label.

“ESP32-C3 SuperMini” or “0.96-inch OLED” describes a family of marketplace
boards, not a controlled electrical part. If a later shipment changes layout,
repeat incoming inspection and affected qualification tests.

## Steps 1–2: unpowered evidence

Inspect under magnification for bridges, whiskers, reversed parts, pin-order
mistakes, exposed conductor near metal, solder balls, cut insulation, and
strained pads.

With power off and capacitors discharged:

1. verify intended grounds are continuous;
2. verify the positive rail is not shorted to ground;
3. verify each signal reaches its intended endpoint and no adjacent pin;
4. verify switches and removable isolation links in every position;
5. verify the frame is isolated from both rails and BTL speaker outputs; and
6. record actual readings, not only a beep.

A low initial resistance that rises can be capacitors charging from the
meter. Compare polarity and repeat; use the schematic rather than declaring a
short from one number.

## Step 3: power as its own subsystem

Disconnect expensive or sensitive loads where possible. Use a current-limited
supply in place of the battery and test the input/protection/converter path.

Measure:

- polarity and rail voltage at no load and controlled loads;
- startup at the lowest intended input, not only operation after startup;
- rail behavior during a load step;
- voltage drop across each important path segment;
- quiescent and operating current; and
- temperature rise after reaching thermal equilibrium.

Do not infer converter capability from its controller IC headline. Module
inductor, layout, thermal path, capacitors, protection devices, and input leads
all matter. Do not call a room-temperature ten-start sample test a universal
guarantee; record the sample, ramp, load, and temperature.

## Step 4: establish a heartbeat

Power only the controller by its documented service method. Confirm:

- enumeration or serial output;
- reset reason;
- expected firmware version;
- no boot loop;
- known idle current; and
- GPIO assignment printed by the build or documented from source.

A repeated reboot is often a power symptom, not “bad code.” Capture the rail
and reset log together before changing firmware.

## Step 5: one bus, one device

For I2C, begin with the controller and one OLED. Run an address scan and record
the address and effective pull-up resistance. If qualifying multiple samples,
test them one at a time under the same conditions; do not turn spare samples
into an unintended multi-display bus. Capture SDA/SCL if the scan fails.

For I2S, first confirm clock frequencies without the amplifier or microphone,
then add one endpoint. Verify `BCLK`, `WS`, data direction, slot format, and
word length against source and datasheets. Short digital wires are helpful but
do not make signal integrity automatic.

For any failed peripheral, ask in this order:

```text
correct power and return?
→ correct pin order and voltage level?
→ correct reset/enable/strap state?
→ expected clock/activity?
→ expected address or data format?
→ analog edge/timing margin?
→ exact module fault or incompatibility?
```

## Step 6: add energy-producing loads carefully

An amplifier and speaker can create large, fast current changes. Begin with a
low digital level and a current-limited source at the fixture's documented
voltage. Confirm the speaker is connected only between the two BTL outputs;
neither lead goes to ground.

Observe rail voltage and current while increasing the level in controlled
steps. Stop for clipping, resets, unexpected CC operation, heating, or
mechanical buzzing. Test microphone capture before closing the acoustic path.

## Steps 7–8: qualification is wider than “works once”

Functional bring-up proves an article operated under one condition.
Qualification asks whether it meets stated limits across intended conditions.

| Domain | Example question | Evidence needed |
| --- | --- | --- |
| Power | Does 3V3 stay in bounds during worst credible transient? | scope trace at load, defined input/load/temp |
| Startup | Can it cold-start at minimum intended input? | repeated starts with controlled input ramp and load |
| Thermal | Is every accessible/critical part within its limit? | stabilized temperatures under defined high-average use |
| I2C | Does each exact OLED sample ACK with adequate edge timing when tested separately? | scan plus captured rise time and logic levels |
| Audio | Is speech intelligible without resets/clipping? | waveform/current plus repeatable acoustic test |
| RF | What does the final frame do relative to the bare baseline? | repeated A/B RSSI/loss/throughput trials |
| Mechanical | Can it be assembled, controlled, and serviced safely? | exact-part fit, plug/cable/tool/removal-path checks |
| Faults | Does a single foreseeable fault become hazardous? | reviewed fault table and safe, bounded tests |

Set quantitative limits from applicable datasheets and project requirements.
Do not invent a limit after seeing the result.

## Hypotheses and discriminating tests

Use a table instead of random rework:

| Symptom | Hypothesis A | Hypothesis B | A useful separating test |
| --- | --- | --- | --- |
| OLED absent | wrong address | no target power | measure target VCC, then scan/capture address |
| resets on tone | rail dip | software crash | scope 3V3 while saving reset reason/log |
| I2C intermittent | weak pull-up | loose connection | measure rise time, then continuity while unpowered |
| quiet/distorted audio | wrong slot/format | bad enclosure/load | inspect I2S frame into a known load before enclosure A/B |
| weak Wi-Fi in frame | metal detuning/coupling | power instability | repeat RF A/B while separately recording rail/reset behavior |
| power path hot | excess current | high path resistance | measure branch current and loaded drop across segments |

The result of a test updates the causal model; one observation need not prove
a cause. The diagnostic decision flow is:

```text
symptom → preserve evidence → list competing hypotheses
                                      ↓
                             one safe separating test
                                      ↓
                              observation / result
                                      ↓
                          eliminate or rank hypotheses
                               │                 │
                      cause not isolated      cause isolated
                               │                 └─→ correct cause
                               └─→ next test              ↓
                                                   rerun failure test
                                                   and regressions
```

If the cause is not isolated, choose another separating test. Once it is
isolated, correct it and rerun the original failure test plus the relevant
regressions.

The best test often eliminates several causes without changing the device.

## Root cause versus workaround

If touching a wire makes I2C work, the root cause is not “needs a finger.” The
touch may add capacitance, coupling, pressure, or a return path. Measure which
parameter changed.

Similarly:

- reducing speaker level may mask power-path weakness;
- adding arbitrary capacitance may mask layout or pull-up errors;
- retrying startup may hide inadequate startup margin;
- moving a cable may hide a broken conductor;
- resetting after failure may erase the useful log.

A workaround can be valuable, but label it and continue until the causal model
predicts the evidence.

## Fault containment without unsafe fault injection

Begin with analysis and current-limited substitutes. Do not deliberately short,
overcharge, heat, puncture, or reverse a lithium cell. Safe exercises include:

- omit an I2C target or replace the pull-up with a deliberately weak value;
- lower the bench-supply current limit and predict CC behavior;
- insert a known resistor in a simulated source path to study sag;
- disconnect an I2S signal with power off;
- place a nonconductive dummy in the enclosure for fit tests; and
- use metal coupons near a USB-powered radio for RF A/B tests.

High-energy, compliance, abuse, and battery-fault testing require appropriate
facilities and expertise beyond this course.

## Capstone: explain, wire, observe, diagnose

Build a battery-free bench article with:

- a current-limited supply or the controller's documented USB-only setup;
- ESP32-C3 development board;
- one qualified 3.3 V-compatible I2C OLED module;
- optional I2S microphone and amplifier, with speaker initially disconnected;
- DMM and, ideally, a logic analyzer; and
- exact firmware built from the corrected source path.

### Deliverable A — one-page system drawing

Draw:

- every source and return-current path;
- all rail names and nominal voltages;
- each connector pin in physical order;
- I2C SDA/SCL and pull-ups;
- I2S BCLK/WS/data directions;
- enable, reset, and boot-strap pins; and
- frame isolation and the floating speaker connection.

### Deliverable B — calculations

Show with labels and units:

1. current and power for one resistor load;
2. loaded source drop from a known series resistance;
3. approximate I2C pull-up low current and rise time;
4. I2S bit clock from sample rate, slots, and bits per slot;
5. ideal BTL sine power into an 8-ohm nominal load, clearly labeled as an
   idealized calculation; and
6. nominal battery energy from rated voltage and amp-hours, without treating
   it as guaranteed runtime.

### Deliverable C — measurements

Record:

- unpowered rail isolation;
- controller rail and idle current;
- I2C addresses and a decoded transaction;
- I2C rise time or a reason your tool cannot measure it;
- I2S `WS` and `BCLK` frequencies;
- low-level audio test current and rail behavior, if audio is installed; and
- exact test conditions and evidence labels.

### Deliverable D — diagnose three planted faults

With USB disconnected between wiring changes, choose three reversible faults
on the button/OLED/microphone prototype:

- swap one OLED's SDA and SCL;
- disconnect one OLED signal wire;
- select the wrong I2C address in firmware;
- make pull-up resistance too weak or too strong within safe current limits;
- impose a low supply current limit; or
- choose the wrong logic-analyzer decoder setting.

Keep common ground intact during powered tests. Missing-ground and
missing-I2S-clock faults may be inspected using unpowered continuity checks
only; restore the complete wiring before applying power. In particular, an
amplifier receiving BCLK without WS can produce a damaging DC output, so that
is not a powered fault exercise.

For each, write symptom → hypotheses → discriminating test → evidence → root
cause → verified correction. Do not use the lithium cell.

## Final cell-integration gate

Completing this course is not itself permission to install the cell. The exact
Pocket Assistant must also have:

- one reconciled schematic, BOM, and assembly wiring map;
- qualified exact modules and connector pinouts;
- adequate cold-start and transient margin at intended input conditions;
- normal low-voltage shutdown rather than reliance on protection cutoff;
- reviewed USB/service-power isolation with no backfeed;
- measured thermal and audio behavior;
- exact-part mechanical fit including wires, insulation, controls, and removal;
- RF comparison in the final arrangement; and
- a dated, signed acceptance record with every failure resolved.

Until then, it is a qualification prototype—not a frozen production design.

## Common debugging mistakes

- Replacing parts before recording the failing state.
- Changing wiring, firmware, and power simultaneously.
- Debugging protocol before verifying power, return, and pin order.
- Treating a static tool, simulator, or CAD pass as physical test evidence.
- Confusing peak, average, and RMS conditions.
- Repeating a flaky test until it passes and discarding failures.
- Testing only one marketplace sample or one room temperature.
- Installing in the enclosure before the open-bench reference works.

## Check yourself

1. An OLED scan fails. Name the first three physical checks before editing the
   display library.
2. The device works open-air but resets only at loud volume in the case. What
   two domains should be measured together?
3. Does passing one cold start prove adequate minimum-input startup margin?
4. What is the difference between a diagnosis and an acceptance test?

<details>
<summary>Answers</summary>

1. Correct target supply/ground, physical connector pin order and continuity,
   then SDA/SCL levels/pull-ups. Exact order can vary, but power comes first.
2. Electrical power integrity/current/temperature and the audio/mechanical load
   or enclosure condition. Correlated rail and reset evidence is especially useful.
3. No. Define the input ramp, load, temperature, samples, repetition, and
   datasheet margin; then test the intended range.
4. Diagnosis identifies the cause of a symptom. Acceptance applies a pre-set
   pass/fail rule under defined conditions to decide whether an article meets a
   requirement.

</details>

## Authoritative further reading

- [NASA systems engineering handbook](https://www.nasa.gov/reference/systems-engineering-handbook/)
- [KiCad schematic editor and ERC documentation](https://docs.kicad.org/9.0/en/eeschema/eeschema.html)
- [KiCad PCB editor and DRC documentation](https://docs.kicad.org/9.0/en/pcbnew/pcbnew.html)
- [Espressif ESP32-C3 hardware design guidelines](https://docs.espressif.com/projects/esp-hardware-design-guidelines/en/latest/esp32c3/index.html)

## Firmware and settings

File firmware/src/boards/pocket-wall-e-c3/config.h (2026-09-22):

#ifndef _POCKET_WALL_E_C3_CONFIG_H_
#define _POCKET_WALL_E_C3_CONFIG_H_

#include <driver/gpio.h>

// The microphone and amplifier share the same I2S clocks in duplex mode.
//
// The vendor image runs 24 kHz, but the MAX98357A datasheet states twice that
// 24 kHz LRCLK is NOT supported (supported: 8/16/32/44.1/48/88.2/96 kHz).
// 16 kHz sits centered in the amplifier's fS2 window and is legal for the
// Phase 0 primary, Adafruit #6049 ICS-43434 (SEL low, DOUT on GPIO4). The held
// INMP441 alternative uses analogous signals but not an interchangeable carrier
// pin order. Both use 64 SCK per frame at BCLK 1.024 MHz. This also matches
// Xiaozhi's Opus encoder,
// which is hard-coded to 16 kHz, so the input resampler is never created and
// server audio is resampled 24k->16k by the existing output_resampler_ path
// in audio_service.cc.
#define AUDIO_INPUT_SAMPLE_RATE  16000
#define AUDIO_OUTPUT_SAMPLE_RATE 16000
#define AUDIO_I2S_GPIO_WS        GPIO_NUM_1
#define AUDIO_I2S_GPIO_BCLK      GPIO_NUM_2
#define AUDIO_I2S_GPIO_DOUT      GPIO_NUM_3  // ESP32-C3 -> MAX98357A DIN

// I2S microphone SD -> ESP32-C3. The vendor image uses GPIO8, but on the ESP32-C3
// SuperMini GPIO8 carries the onboard blue LED and is a boot-strapping pin:
// GPIO8 must read high to enter the serial bootloader, and this board has no
// OTA app slots, so losing download mode inside a finished frame is
// unrecoverable. GPIO4 (ADC1_CH4/MTMS) is free once native USB-JTAG is used.
// Wiring built for the vendor image must keep the microphone on GPIO8.
#define AUDIO_I2S_GPIO_DIN       GPIO_NUM_4

// This is the project's external action/config button. GPIO9 remains the
// ESP32-C3 SuperMini's ROM BOOT strap button.
#define ACTION_BUTTON_GPIO GPIO_NUM_10

// Drives MAX98357A SD_MODE directly in the USB-powered Step 11 stage, where the
// amplifier's VIN comes only from the controller's 5V pin (one supply, so the
// earlier TXU0104 translator design is not used). An external pull-down keeps
// the amplifier in shutdown through reset. Firmware raises this pin only in a
// build made with --amplifier, after silent clocks and the startup delay.
#define AMPLIFIER_ENABLE_GPIO GPIO_NUM_5

#define DISPLAY_SCL_PIN       GPIO_NUM_20
#define DISPLAY_SDA_PIN       GPIO_NUM_21
// Generic 4-pin SSD1306 modules answer at 0x3C; Adafruit's 128x64 breakouts
// (e.g. the white #326) default to 0x3D with jumper SJ3 open. The board probes
// the primary address first, then the alternate, and finally falls back to a
// headless NoDisplay boot instead of aborting into a panic-reboot loop.
#define DISPLAY_I2C_ADDRESS       0x3C
#define DISPLAY_I2C_ADDRESS_ALT   0x3D
#define DISPLAY_I2C_FREQUENCY 400000
#define DISPLAY_WIDTH         128
#define DISPLAY_HEIGHT        64
#define DISPLAY_MIRROR_X      false
#define DISPLAY_MIRROR_Y      false
#define DISPLAY_INVERT_COLOR  true

#endif  // _POCKET_WALL_E_C3_CONFIG_H_

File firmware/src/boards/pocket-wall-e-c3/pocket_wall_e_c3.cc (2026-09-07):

#include "wifi_board.h"
#include "codecs/no_audio_codec.h"
#include "display/display.h"
#include "display/oled_display.h"
#include "application.h"
#include "button.h"
#include "config.h"
#include "settings.h"

#include <driver/i2c_master.h>
#include <esp_log.h>
#include <esp_lcd_panel_ops.h>
#include <esp_lcd_panel_vendor.h>
#include <esp_timer.h>

#include <algorithm>
#include <array>
#include <atomic>
#include <cmath>
#include <limits>
#include <mutex>

#define TAG "PocketWallEC3"

// The author's display class is not published. Keeping a distinct board class
// preserves the extension point while using Xiaozhi's maintained 128x64 UI.
class PocketOledDisplay final : public OledDisplay {
public:
    using OledDisplay::OledDisplay;
};

namespace {

void InitializeAmplifierMute() {
    // Set the output latch before enabling the driver. Never gpio_reset_pin()
    // here: GPIO5/MTDI must not be returned to a pulled-up state.
    ESP_ERROR_CHECK(gpio_set_level(AMPLIFIER_ENABLE_GPIO, 0));
    ESP_ERROR_CHECK(gpio_pullup_dis(AMPLIFIER_ENABLE_GPIO));
    ESP_ERROR_CHECK(gpio_pulldown_en(AMPLIFIER_ENABLE_GPIO));
    ESP_ERROR_CHECK(gpio_set_direction(AMPLIFIER_ENABLE_GPIO, GPIO_MODE_OUTPUT));
}

class PocketAudioCodec final : public NoAudioCodecDuplex {
private:
    std::mutex control_mutex_;
    bool amplifier_enabled_ = false;
    int64_t clocks_ready_at_us_ = 0;

    void MuteAmplifier() {
        ESP_ERROR_CHECK(gpio_set_level(AMPLIFIER_ENABLE_GPIO, 0));
        amplifier_enabled_ = false;
    }

    bool WriteZeros(int samples) {
        const std::array<int32_t, AUDIO_CODEC_DMA_FRAME_NUM> zeros{};
        while (samples > 0) {
            const size_t bytes = std::min(samples, AUDIO_CODEC_DMA_FRAME_NUM) * sizeof(int32_t);
            size_t written = 0;
            const auto err = i2s_channel_write(tx_handle_, zeros.data(), bytes, &written, 200);
            if (err != ESP_OK || written != bytes) {
                MuteAmplifier();
                ESP_LOGE(TAG, "Silent I2S write failed: %s", esp_err_to_name(err));
                return false;
            }
            samples -= written / sizeof(int32_t);
        }
        return true;
    }

    bool WriteSilenceUntil(int64_t deadline_us) {
        // Runs only in the PCM writer, paced by I2S DMA. No startup sleep is
        // added to the application event loop or a timer callback.
        while (esp_timer_get_time() < deadline_us) {
            if (!WriteZeros(AUDIO_CODEC_DMA_FRAME_NUM)) {
                return false;
            }
        }
        return true;
    }

    void StartSilentClocks() {
        if (output_enabled_) {
            return;
        }
        MuteAmplifier();
        // Replace every DMA buffer, including data left from earlier playback,
        // before clocks start. The upstream codec auto-clears consumed buffers.
        const std::vector<int32_t> zeros(AUDIO_CODEC_DMA_DESC_NUM * AUDIO_CODEC_DMA_FRAME_NUM, 0);
        size_t loaded = 0;
        ESP_ERROR_CHECK(i2s_channel_preload_data(tx_handle_, zeros.data(),
                                               zeros.size() * sizeof(int32_t), &loaded));
        ESP_ERROR_CHECK(loaded == zeros.size() * sizeof(int32_t) ? ESP_OK : ESP_FAIL);
        NoAudioCodecDuplex::EnableOutput(true);
        clocks_ready_at_us_ = esp_timer_get_time() + CONFIG_POCKET_AI_AMP_STARTUP_DELAY_MS * 1000LL;
    }

protected:
    int Write(const int16_t* data, int samples) override {
        std::lock_guard<std::mutex> lock(control_mutex_);
        if (!output_enabled_) {
            return 0;
        }
#if CONFIG_POCKET_AI_ENABLE_QUALIFIED_AMPLIFIER && !CONFIG_POCKET_AI_BENCH_DIAGNOSTICS
        if (!amplifier_enabled_) {
            if (!WriteSilenceUntil(clocks_ready_at_us_)) {
                return 0;
            }
            ESP_ERROR_CHECK(gpio_set_level(AMPLIFIER_ENABLE_GPIO, 1));
            amplifier_enabled_ = true;
            if (!WriteSilenceUntil(esp_timer_get_time() +
                                  CONFIG_POCKET_AI_AMP_TURN_ON_DELAY_MS * 1000LL)) {
                return 0;
            }
        }
        return NoAudioCodecDuplex::Write(data, samples);
#else
        // The unqualified prototype supplies clocks to its microphone, while
        // amplifier SD_MODE stays low and speaker data stays zero.
        (void)data;
        return WriteZeros(samples) ? samples : 0;
#endif
    }

public:
    PocketAudioCodec()
        : NoAudioCodecDuplex(AUDIO_INPUT_SAMPLE_RATE, AUDIO_OUTPUT_SAMPLE_RATE,
                             AUDIO_I2S_GPIO_BCLK, AUDIO_I2S_GPIO_WS,
                             AUDIO_I2S_GPIO_DOUT, AUDIO_I2S_GPIO_DIN) {
    }

    void Start() override {
        // Preserve a saved zero (mute); the upstream Start() raises zero to 10.
        Settings settings("audio", false);
        output_volume_ = std::clamp<int32_t>(settings.GetInt("output_volume", CONFIG_POCKET_AI_MAX_VOLUME),
                                             0, CONFIG_POCKET_AI_MAX_VOLUME);
        ESP_LOGI(TAG, "Prototype volume cap: %d; amplifier: %s", CONFIG_POCKET_AI_MAX_VOLUME,
#if CONFIG_POCKET_AI_ENABLE_QUALIFIED_AMPLIFIER && !CONFIG_POCKET_AI_BENCH_DIAGNOSTICS
                 "qualified opt-in"
#else
                 "disabled"
#endif
        );
    }

    void SetOutputVolume(int volume) override {
        std::lock_guard<std::mutex> lock(control_mutex_);
        NoAudioCodecDuplex::SetOutputVolume(std::clamp(volume, 0, CONFIG_POCKET_AI_MAX_VOLUME));
    }

    void EnableInput(bool enable) override {
        std::lock_guard<std::mutex> lock(control_mutex_);
        if (enable) {
            StartSilentClocks();
        }
        NoAudioCodecDuplex::EnableInput(enable);
    }

    void EnableOutput(bool enable) override {
        std::lock_guard<std::mutex> lock(control_mutex_);
        if (enable) {
            StartSilentClocks();
        } else {
            MuteAmplifier();
            NoAudioCodecDuplex::EnableOutput(false);
        }
    }

    int ReadBenchSamples(int32_t* samples, size_t count) {
        size_t bytes_read = 0;
        const auto err = i2s_channel_read(rx_handle_, samples, count * sizeof(int32_t),
                                        &bytes_read, 200);
        return err == ESP_OK ? bytes_read / sizeof(int32_t) : 0;
    }
};

}  // namespace
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

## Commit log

2026-09-02 Update docs, CAD, and educational content; add fundamentals course
    Expands the edu/fundamentals curriculum with a new course sequence
    covering circuits, components, measurement, digital logic, I2C/I2S,
    audio, RF/EMC, and soldering, plus reference materials. Also updates
    build guide, materials, assembly evidence docs, and CAD files.
    [pager_rev_a.FCStd, pager_rev_a.step]
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2026-09-02 Release R1 build: creator-faithful compact power design, updated all guides
    Final audit replaces the R0 NO-GO converter/fuse/16340 chain with the
    reference build's own topology on documented protected parts: Adafruit
    #1578 protected 500 mAh LiPo + #4410 USB-C charger in-frame + slide
    switch feeding the SuperMini 5V pin and amp VIN. Restores INMP441 as
    primary microphone, keeps the safety corrections (frame floating,
    GPIO4 mic, 16 kHz, no cell soldering), and rewrites the materials,
    build, wiring, evidence, sourcing, and acceptance docs for the
    ~45x32x20 mm target. Marks CAD stale pending regeneration.
    [parts.csv]
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2026-09-02 Correct wire-gauge guidance: 30 AWG adequate, 26 AWG optional upgrade
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2026-09-02 Finalize Phase 0 materials review
    [parts.csv]
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2026-09-07 Simplify USB prototype workflow and fix firmware validation
    [parts.csv]
2026-09-07 Ground every day's material prep list in the actual purchase record
    Each of the 15 sessions already had a Prepare block, but the blocks were
    prose bullets that assumed possession of items the inventory does not
    record, and they omitted much of what the lab steps actually require.
    Every day now carries a three-part preparation list:
    - an "Already in hand" table with a real quantity and the specific lab step
    each item serves, drawn only from what INVENTORY.md records as purchased;
    - a "Not in hand" section naming the substitute or the gate that closes,
    per the plan's existing no-purchase rule; and
    - a "Keep off the bench" list plus pre-session incoming checks.
    Correct five rows that the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
2026-09-13 Add six-session build-first fast track for software engineers
    The repo had the build mechanics (PROTOTYPE_QUICKSTART.md) and short theory
    (plan/concepts/), but the only guided program was the ~35-hour 15-session
    plan. plan/FAST_TRACK.md is the lean program: six sessions, roughly 10-12
    hours, ending at the same USB prototype - flash and boot, solder the
    headers, button, OLED, microphone, then a cold-start rebuild with a planted
    fault and a proven/inconclusive/held review.
    Each session is build-first: bench list, quickstart link for the mechanics,
    and a few core-concept bullets with software-engineer mappings (pull-up as
    default value, boot straps as env vars read at process start, I2C ACK as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
2026-09-13 Add materials and tools tables with purchase links to the fast track
    Two tables up front: the short shopping list (data cable, header strips,
    wick, perfboard, optional fume/loupe) with the recorded Amazon picks where
    INVENTORY.md names one and clearly-labelled search links where it does not,
    and an already-owned table mapping every item the six sessions use to its
    sessions and original recorded order link. Items whose order URL was never
    preserved are marked as such rather than given substitute links.
2026-09-20 Split the fast track into action, theory, and parts guides
    The fast track mixed step-by-step instructions with engineering
    explanation, which made it hard to follow at the bench. Separate the
    three jobs:
    - plan/FAST_TRACK.md keeps only actions: what to take out, what to
    connect, what command to run, and what result counts as a pass.
    - plan/FAST_TRACK_THEORY.md holds the explanations, keyed to each step.
    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
2026-09-20 Add CLAUDE.md so remote sessions start with project rules
    Cloud sessions started from the phone land in a fresh checkout with none
    of the context a local session accumulates. Record the parts that are
    costly to rediscover: which documents are authority versus deliberately
    archived, the USB-only safety invariants, the corrected-source pin
    contract and how it differs from the vendor image, the build and test
    commands, and the evidence rule that hardware_tested is still false.
2026-09-21 Record the USB prototype passing on hardware
    PASS 9 was established on a physical board on 2026-09-20: two cold starts
    without a reset loop, every button press logged, the OLED starting and
    toggling, and speech microphone RMS roughly 4x the quiet floor with
    read_errors=0 across ~100 seconds of capture.
    Four documents still asserted that no physical ESP32-C3 had ever been
    connected in this workspace. That is no longer true, so each now states what
    was actually established and what was not: no battery circuit, amplifier
    still disabled, nothing past Step 9.
    firmware/source-build.json keeps hardware_tested: false deliberately. That
    flag is regenerated with False hard-coded by record_source_bui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
2026-09-21 Cap SuperMini Wi-Fi TX power and record Step 10 passing
    The ESP32-C3 SuperMini boards in this batch carry a poorly matched ceramic
    chip antenna. At the firmware's default 20 dBm their provisioning access
    point was invisible on three boards, including A1, even at close range.
    Capping transmit power at 8.5 dBm (esp_wifi_set_max_tx_power(34), in
    quarter-dBm units) made A1's hotspot visible. This lowers power; it is not
    a boost.
    ESP-IDF only honours the cap after esp_wifi_start(), so the board applies
    it after both starts: the provisioning access point and the station
    connection. The station path matters because a provisioned board skips the
    hotspot on every later boot, and the pinned esp-wifi-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
2026-09-21 Add a local OpenAI voice bridge build mode
    build.sh --assistant-local --bridge-url=http://HOST:PORT/ota/SECRET builds
    the A1 assistant with Xiaozhi's OTA bootstrap pointed at a host on the LAN
    instead of the third-party cloud. The new firmware/bridge/ program (aiohttp)
    answers that bootstrap, accepts A1's Xiaozhi WebSocket, decodes its 16 kHz
    Opus audio, relays it to the OpenAI Realtime API at 24 kHz, and encodes the
    reply as Opus for A1. The OpenAI API key and both LAN tokens are read from
    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
2026-09-21 Add capacitor electron-flow diagram for the fundamentals course
    Three panels follow electrons through a 1000 uF capacitor and a 1 kOhm +
    LED branch on a 5 V supply: charging, holding charge at steady DC, and
    discharging through the LED after the supply is isolated. They show that
    no electrons cross the dielectric and that conventional current points
    opposite the drawn electron flow.
    The SVG is the editable source; the PNG is a 1500 x 800 render of it. No
    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
2026-09-21 Record the DHO802 oscilloscope purchase and the instrument decision
    The builder bought a Rigol DHO802 on 2026-09-21 (Amazon B0CKX699F5):
    70 MHz, two channels plus external trigger, 12-bit, Single trigger mode,
    A-B math, two PVP3150 probes. It meets every part of the purchase
    authority's two-channel scope specification, so that row moves from
    ARRANGE to OWNED with its incoming checks. The inventory gains the order,
    a measurement-tools row marked not yet received, and the price caveat.
    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
2026-09-21 Add an index of published learning pages under edu/
    Educational material is now also published as illustrated web pages
    (Claude artifacts) built from the repository's Markdown, which remains
    the authority. edu/ARTIFACTS.md lists each page with its source file,
    what it covers, and the publish date: the Fast Track Theory companion
    with one mechanism drawing per step, the Step 10 bench guide, and the
    22-30 September scope-countdown plan. The edu README and the theory
    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
2026-09-21 Publish the course as illustrated three-page lessons; fix the pull-up note
    Every fundamentals lesson (00 to 13) and the project overview now exist as
    illustrated web pages, each condensed to at most three printed pages with
    two to four inline diagrams of the mechanisms, three check-yourself
    questions, and a link back to the full lesson. edu/ARTIFACTS.md lists all
    fifteen with their source files, and the edu and fundamentals READMEs
    point at the index. The Markdown lessons remain the authority.
    The Scope Countdown plan row is updated: the week of 22 to 30 September is
    now a concept week, two illustrated lessons a day with the bench optional.
    docs/INVENTORY.md said the 10 kOhm resistor pulls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
2026-09-22 Add an opt-in amplifier build for the USB-powered speaker stage
    The board firmware already held GPIO5 low from its earliest init, started
    the I2S clocks with zero data, waited a startup delay, raised GPIO5, waited
    a turn-on delay, and capped the volume. Only the build tooling kept it from
    ever being used: build.sh forced the option off and the record and verify
    scripts rejected any amplifier-enabled build.
    build.sh --assistant --amplifier (or --assistant-local ... --amplifier) now
    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
2026-09-22 Make the prototype a USB-powered home device and add Step 11
    The builder decided on 2026-09-21 that the prototype stays on USB power:
    it lives at home or moves between Wi-Fi networks, and portable battery
    power is out of scope. That removes the reason for most of the purchase
    authority's audio fixture. With the amplifier powered from the
    controller's 5V pin, one USB supply feeds both sides, so there is no
    powered-controller, unpowered-amplifier state and no translator,
    regulator, switch, fuses, or harness are needed.
    - FINAL_MATERIALS gains a scope-decision section: Fixtures A and B and
    gates 5, 6, 8 and 9 do not apply; gate 7 is met by Step 11's
    measurement; the do-not-buy list; gates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
2026-09-22 Index the Step 11 bench guide and the updated theory page
    Adds the illustrated Step 11 guide (one-supply idea, wiring, SD
    pull-down, kit-resistor dummy load, three gates) to edu/ARTIFACTS.md and
    notes that the Fast Track Theory page now covers Step 11.
2026-09-22 Record the 21 September consumables and five more speakers
    The builder bought the enclosure consumables the audit found missing and
    five more speakers:
    - Amazon: BAISDY 45-piece wet/dry sandpaper, 400-3000 grit; JoTownCand
    solder wick 3-pack; Epic Medical Supply 91% isopropyl alcohol, 2 x 16 oz.
    - DigiKey: 5 x Same Sky CES-20134-088PM (2223-CES-20134-088PM-ND) at
    $4.10, $20.50, making six speakers in total.
    The inventory gains the orders and owned rows, and its still-needed list
    shrinks to local swabs and baking soda (only for acid-flux frame joints)
    plus two optional items; the battery-era wording is gone. The fast track,
    parts guide and theory companion no longer call the speaker the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
2026-09-22 Switch the planned finish to a white primer and record the cancellation
    The builder canceled the Rust-Oleum 249322 dark-green self-etching primer
    and wants an all-white system. The inventory drops that order and plans
    Rust-Oleum 7780830 Stops Rust Clean Metal Primer (flat white) under
    7791830 satin white, over brass sanded with the owned 400-600 grit and
    wiped with the owned 91% IPA. Neither can is bought. Without an etching
    primer, adhesion on brass is the open question, so the note keeps the
    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
2026-09-22 Record the two white topcoats
    The builder bought Rust-Oleum Stops Rust 7789830 gloss canvas white and
    7791830 satin white on Amazon on 2026-09-21. The inventory's finish note
    now lists both as owned, has the brass test coupons choose one sheen for
    the whole frame, and keeps the 7780830 white primer as planned but not
    bought.
2026-09-22 Restructure the week plan as two lesson hours and one build hour a day
    The builder wants each day split into two hours of lessons and one hour of
    building. The Scope Countdown page now pairs two lessons with one build
    hour from Tuesday 22 to Wednesday 30, and the build hours line up Step 11:
    the unpowered speaker lab, the Step 10 record and 5V-pin check, a radio
    survey of the spare boards, the amplifier's headers, the dummy load and SD
    pull-down, wiring and PASS 11A, measuring every part, and scope prep, then
    I2S-01 and a new SD-through-reset capture on the 30th. The rail capture
    moves to the 11B session, where Wi-Fi and audio run together.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
2026-09-22 Index the Wednesday 23 build-hour page
    Adds the illustrated one-hour build plan for Wednesday 23 September to
    edu/ARTIFACTS.md: the Wi-Fi credential read from A1's flash, the
    diode-mode check of whether USB reaches the 5V pin directly, and the
    STEP10-01 and VBUS-01 records.
2026-09-22 Add a script that shows a board's saved Wi-Fi with passwords hidden
    The credential check was a long shell pipeline that was hard to read on
    the build-hour page. tools/saved_wifi.py does the same work in one
    command: it reads only the NVS partition with esptool, parses it with
    ESP-IDF's nvs_tool, prints the wifi namespace with every password shown
    as <hidden, set> or <hidden, empty>, and deletes the temporary dump in a
    TemporaryDirectory even if a step fails. It refuses to run outside the
    ESP-IDF environment. Two unit tests cover the password hiding and the
    no-network case; tools/README.md documents it.
    Run on A1 (MAC e8:f6:0a:4f:09:30) on 2026-09-22 it reported one saved
    network with a pass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
    [saved_wifi.py, test_saved_wifi.py]
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2026-09-22 Add the VBUS-01 diode-mode readings for A1
    The builder reported the readings behind the direct-link result: 0.001 V
    with red on VBUS and black on 5V, and 0.002 V with the probes swapped.
    Both are near zero, as a direct connection reads; a diode would read a
    few tenths of a volt one way and OL the other.
2026-09-22 Add the Step 11 prototype shortcut: speaker at cap 30 or less, no scope
    The builder decided on 2026-09-22 to skip the dummy load and PASS 11B for
    this prototype. The firmware volume cap now protects the speaker on its own.
    From the MAX98357A gain table (2.1 dBV reference, 15.6 dB maximum), cap 15
    peaks at 0.24 V and cap 30 at 0.98 V, both below the speaker's 2.53 V. A cap
    above 30 still goes through the dummy load and PASS 11B.
    PASS 11A may now run on the assistant build without --amplifier, which also
    holds GPIO5 low. Measuring SD before the GPIO5 jumper is fitted shows that
    the pull-down alone holds shutdown. The flash warning and the CLAUDE.md
    amplifier rule match. The illustrated build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

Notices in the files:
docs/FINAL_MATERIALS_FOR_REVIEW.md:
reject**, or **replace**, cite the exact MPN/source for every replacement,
